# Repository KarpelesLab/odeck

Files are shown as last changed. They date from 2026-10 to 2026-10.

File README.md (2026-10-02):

# odeck

An open-hardware USB-C deck you can order fully assembled from JLCPCB and use as a bare PCB the day it
arrives: USB-C upstream, display out, USB-A, SD + microSD, 2.5 GbE, up to **140 W** pass-through
charging, a small status LCD instead of a wall of LEDs, and an RP2350 you can reprogram.

The long-term goal is a **40 Gbps USB4** deck. The first board, **odeck-10**, is a 10 Gbps USB-C deck
built only from parts JLC stocks, to prove out everything the USB4 version will reuse: power, PD,
firmware, display, card reader, Ethernet, board shape and silkscreen.

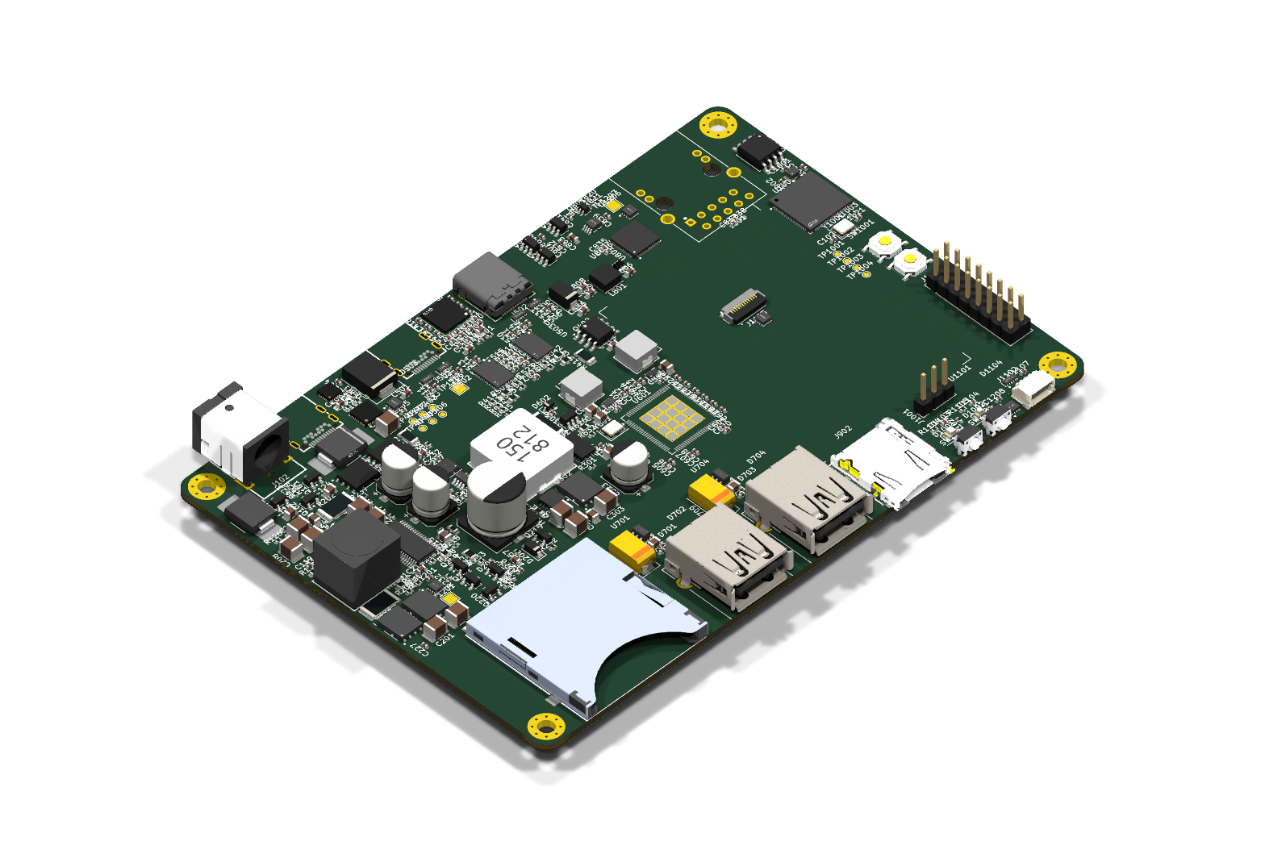
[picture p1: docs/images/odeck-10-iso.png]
odeck-10 rough placement


> **Status (2026-10): schematic complete and reviewed, placement done (DRC-clean, unrouted) — not routed,
> not fabricated.** Placement is code: `hardware/odeck-10/layout/*.py` (one script per board region, see
> `docs/floorplan.md`). The LCD panel and the two JAE USB-C receptacles have no 3D model yet, and the
> GPIO header is shown although it ships unpopulated. More views: [top](docs/images/odeck-10-top.png) ·
> [bottom](docs/images/odeck-10-bottom.png).

## odeck-10 at a glance

| | |
|---|---|
| Upstream | USB-C, USB 3.2 Gen 2 (10 Gbps) + DisplayPort Alt Mode (2-lane HBR3, 4K60) |
| Charging the laptop | USB PD 3.1 EPR up to **140 W** (28 V × 5 A), 100 W SPR fallback |
| Power inputs | USB-C PD in (EPR, up to 48 V) · DC barrel 5.5×2.5 mm 9–24 V · or bus-powered from the laptop |
| Display | Downstream USB-C with DP Alt Mode (works with any USB-C→HDMI/DP cable) |
| USB | 2× USB-A 10 Gbps (BC1.2 charging), downstream USB-C 10 Gbps, forced-5 V "dumb charge" mode with auto-off |
| Storage | SD + microSD (Genesys GL3224) |
| Network | 2.5 GbE (Realtek RTL8156BG) |
| Brains | RP2350B — drives a 2.0" 320×240 IPS status LCD, reads every PD contract / link speed / temperature / port current, and updates every other chip's firmware from a single UF2 |
| Hackable | 2 user buttons, unpopulated GPIO header (series-R + ESD protected), Qwiic connector, SWD |
| Board | 6-layer JLC impedance stack-up (JLC061611-1080A), 130×89 mm, ~800 parts (double-sided), all JLC stock |

### Architecture

```
 Laptop USB-C ══ TUSB1064 ══ USB 10G ══► Microchip USB7206C hub ──► USB-A ×2 · GL3224 (SD/µSD) · RTL8156BG (2.5GbE)
 (10G + DP alt,      ║                                        └──► downstream USB-C ◄══ TUSB1046 ◄═ DP 2-lane
  140 W EPR out)     ╚═════════════ DP lanes + AUX ═══════════════════════════════╝      (USB2 port → RP2350)

 Infineon PMG1-S3: laptop port (EPR source, DP UFP_D) + downstream port (5 V/3 A, DP DFP_D)
 TI TPS26750: USB-C PD-in sink (up to 48 V)        Barrel 9–24 V ─┐
 PD-in ─► ideal-diode OR ◄──────────────────────────────────────────┘ → VIN 9–48 V
   VIN ─► LM51770 buck-boost → 5–28 V × 5 A → laptop (gated, interlocked, hardware OVP)
   VIN ─► LM5148 → 5 V / 8 A → 3.3 V, 1.15 V …     laptop VBUS ─► 5 V when bus-powered
 RP2350B: LCD, buttons, I²C to PD controllers / INA2xx power monitors / 8× TMP1075 / hub SMBus
```

## Repository layout

| Path | What |
|---|---|
| `docs/requirements.md` | Goals and constraints for the whole project (USB4 end goal) |
| `docs/odeck-10.md` | **Start here** — odeck-10 architecture, part choices, design rules, integration items, status |
| `docs/power-budget.md`, `docs/board-layout.md` | Power/thermal budget, outline & placement plan, stack-up |
| `docs/design/*.md` | Per-sheet design notes with every calculation |
| `docs/review/*.md` | Independent schematic and footprint reviews, with resolutions |
| `docs/research/*.md` | Chip, JLC capability and sourcing research (incl. why 40G is not buildable from JLC stock yet) |
| `hardware/odeck-10/` | KiCad 10 project. Schematic sheets are **generated** from `sheets/*.py` |
| `hardware/lib/` | Project symbols, footprints (all checked against manufacturer drawings) and 3D models |
| `tools/schgen/` | Schematics-as-code generator + netlist verification |
| `tools/pcbsync.py` | Scripted "update PCB from schematic" (keeps placed parts where they are; `--refresh` reloads footprints) |
| `tools/apply_layout.py`, `tools/apply_routing.py` | Placement-as-code and routing-as-code runners (`layout/*.py`, `routing/*.py`) |
| `tools/autoroute.py` | Freerouting wrapper for the non-critical nets |
| `tools/bom_check.py` | Checks every part against live JLC stock (rule: JLC parts only, ≥ 5 in stock) |
| `tools/import_lcsc.sh` | Imports LCSC parts (symbol/footprint/3D) via easyeda2kicad |

## Working on it

Requires KiCad 10 (`/Applications/KiCad` on macOS) and Python 3.10+.

```sh
# regenerate every schematic sheet from its Python source and verify the netlist
python3 hardware/odeck-10/sheets/build_all.py

# electrical rules check
/Applications/KiCad/KiCad.app/Contents/MacOS/kicad-cli sch erc hardware/odeck-10/odeck-10.kicad_sch

# every part in JLC stock?  (+ cost summary)
python3 tools/bom_check.py

# push schematic changes into the PCB (uses KiCad's bundled Python)
/Applications/KiCad/KiCad.app/Contents/Frameworks/Python.framework/Versions/3.9/bin/python3 tools/pcbsync.py hardware/odeck-10

# render
/Applications/KiCad/KiCad.app/Contents/MacOS/kicad-cli pcb render --side top -o top.png hardware/odeck-10/odeck-10.kicad_pcb
```

Edit schematics by editing `hardware/odeck-10/sheets/<sheet>.py`, never the generated `.kicad_sch`.
Inter-sheet nets are declared in `tools/schgen/nets.py`.

## Roadmap

1. **odeck-10** (10 Gbps, JLC parts only) — schematic ✅ · review ✅ · footprints ✅ · placement ✅ ·
   routing ⏳ · firmware · order prototypes · bring-up
2. **20/40 Gbps USB4** — waiting on a USB4 hub controller (and its firmware) that can actually be sourced;
   see `docs/research/usb4-hub.md`.

## License

- **Hardware** — everything under `hardware/` (schematics, sheet sources, PCB, symbols, footprints, 3D
  models we created) and the hardware documentation in `docs/`: **CERN-OHL-P v2**
  ([LICENSE-HARDWARE](LICENSE-HARDWARE)).
  Copyright © 2026 Karpelès Lab Inc.
- **Software** — `tools/` and future firmware: **MIT** ([LICENSE-SOFTWARE](LICENSE-SOFTWARE)).

Not covered: third-party datasheets in `docs/datasheets/` (copyright of their manufacturers, included for
reference), footprints/3D models derived from KiCad's libraries or LCSC/EasyEDA (their own terms), and vendor
firmware/libraries (e.g. Infineon's PD stack), which are fetched at build time and never committed.

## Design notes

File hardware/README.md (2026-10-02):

# Hardware

KiCad 10 projects.

- `odeck-10/` — 10 Gbps prototype (see `../docs/odeck-10.md`, `../docs/board-layout.md`)
  - Hierarchical schematic: one sheet per block (power input, laptop power out, rails, PD controller,
    USB-C muxes & DP, USB hub, USB-A, Ethernet, card reader, MCU, display & UI, sensors)
  - PCB: JLC061611-1080A 6-layer stackup, 110 × 75 mm provisional outline, JLC design rules, net classes
- `lib/` — shared project symbol/footprint libraries (`odeck.kicad_sym`, `odeck.pretty`), referenced via
  each project's `sym-lib-table` / `fp-lib-table`. Parts from LCSC can be imported with `easyeda2kicad`.

CLI checks:

```sh
K=/Applications/KiCad/KiCad.app/Contents/MacOS/kicad-cli
$K sch erc odeck-10/odeck-10.kicad_sch
$K pcb drc odeck-10/odeck-10.kicad_pcb
```

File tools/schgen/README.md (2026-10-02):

# schgen — schematics as code

odeck-10 schematic sheets are generated from Python so they can be reviewed, diffed and verified.

- Sheet sources: `hardware/odeck-10/sheets/<sheet>.py`, each exposing `build(project_dir) -> Sheet`.
- Build + verify everything: `python3 hardware/odeck-10/sheets/build_all.py` (or pass module names).
  Verification exports the netlist with `kicad-cli` and checks every pin is on its intended net.
- Never hand-edit generated `.kicad_sch` files — edit the Python and rebuild.

## Writing a sheet

```python
import sys, os
sys.path.insert(0, os.path.join(os.path.dirname(__file__), "..", "..", "..", "tools", "schgen"))
from schgen import Sheet

def build(D):
    s = Sheet(D, "sensors.kicad_sch", "odeck-10 — Sensors", ref_base=1200)
    s.part("odeck:TMP1075DSGR", "U", "TMP1075", at=(60.96, 50.8),
           pins={"SDA": "I2C_SYS_SDA", "SCL": "I2C_SYS_SCL", "ALERT": "TEMP_ALERT_N",
                 "V+": "+3V3", "GND": "GND", "A0": "GND", "A1": "GND", "A2": "GND", "EP": "GND"})
    s.c("100n", "+3V3", "GND", at=(91.44, 50.8), lcsc="C1525")
    s.r("10k", "I2C_SYS_SDA", "+3V3", size="0402", lcsc="C25744")
    s.flag("+3V3")           # PWR_FLAG, only on the sheet that sources the rail
    s.note("Design notes ...", at=(20.32, 200))
    s.build()
    return s
```

- `pins` maps pin **name or number** → net. Every pin must be mapped or listed in `nc=[...]`.
- Nets in `nets.py: GLOBAL_NETS` become global labels (inter-sheet). `GND` uses the power symbol.
  Everything else is a local label scoped to the sheet. Add new inter-sheet nets to `nets.py`.
- `ref_base`: sheet reference offset (power_input 100, power_laptop 200, power_rails 300, pd_pmg1 400,
  usbc_muxes 500, usb_hub 600, usb_a 700, ethernet 800, card_reader 900, mcu 1000, display_ui 1100,
  sensors 1200) so references never collide.
- `at` positions in mm on a 2.54 mm grid; place related parts near each other. Symbols are placed
  unrotated (rot=0); a short wire stub + label is added on each pin.
- Passives: `s.r()`, `s.c()` with KiCad standard footprints; set `lcsc=` to a JLC **basic** part
  whenever possible. Other parts: `s.part("Device:L", ...)`, `s.part("odeck:<symbol>", ...)`.

## Adding parts from LCSC

```sh
tools/import_lcsc.sh C42166327 C43131250      # symbol + footprint + 3D into hardware/lib
```
Then set pin electrical types (easyeda imports them as unspecified):
```python
from fix_pins import fix_pins
fix_pins("TPS26750SRSMR", {"VBUS": "power_in", "GND": "power_in", "SDA": "bidirectional"}, default="passive")
```
Both tools take a lock on `hardware/lib/.lock`, so parallel runs are safe. Always check the imported
footprint against the datasheet land pattern before layout.

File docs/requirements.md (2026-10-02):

# odeck — Requirements

Open USB4 (40 Gbps) deck, designed to be fabricated **and fully assembled** by JLCPCB,
usable as a bare PCB straight out of the box.

## Goals

- **Upstream:** USB-C, USB4 40 Gbps (TB3/TB4 host compatible), PD source to host up to **140 W (PD 3.1 EPR, 28 V × 5 A)**, 100 W SPR fallback.
- **Downstream:**
  - 1× USB-C USB4/TB (daisy chain, DP alt mode monitor — "USB display")
  - 1× HDMI (target HDMI 2.1 / 4K120 via DP→HDMI PCON; 4K60 minimum) — 40G version; odeck-10 uses DP alt mode on the downstream USB-C only
  - 2× USB-A 10 Gbps
  - SD (UHS-I min, UHS-II stretch) + microSD
  - 2.5GbE RJ45
- **Power:** both modes
  - Bus-powered: runs from host with reduced features / downstream power budget
  - PD-in USB-C (EPR sink, up to 240 W chargers): full features + pass-through charging of host
  - DC barrel jack (5.5×2.5 mm high-current, accept 9–24 V, up to ~200 W at 24 V, overvoltage + reverse polarity
    protected): full features; host charging limited by PSU capability (12 V ≈ 60 W total)
  - Input priority: PD-in > barrel > bus power (ideal-diode / power-mux OR-ing, no back-feeding)
  - MCU-managed dynamic power budget: laptop contract renegotiated as input capability and downstream load change
  - Power path: 9–48 V in → buck-boost (LM5176/LM5177 class, external FETs) → 5–28 V PD source
- **Status display** (small SPI IPS LCD, MCU-driven; replaces most status LEDs — size TBD):
  - Negotiated link speed per port (USB2 / 5G / 10G / 20G / 40G)
  - LAN link speed (from RTL8156 LED pins) and activity
  - Display output: mode / lanes / resolution where readable
  - PD: input source + W available, contract with host (V × A), downstream port power, bus-powered mode
  - Mounting: panel on ~1 mm+ double-sided foam tape (or perimeter foam gasket) on the board surface; FPC tail
    bent back and soldered to pads or plugged into a connector. Area under the panel: copper/silk only if full-pad
    tape, or low-profile parts inside a perimeter gasket. Confirm JLC can apply tape + mount panel.
  - Keep a minimal LED or two (power / fault) for when the display is off or firmware is broken
  - Optional: MCU as USB device on the hub so a host-side app can push extra info
- **System MCU: RP2350B** (QFN-80, 48 GPIO; JLC C42415655 in stock) + QSPI flash
  - Drives the LCD, collects status (I2C/SMBus to PD controllers & hub, LED pins of PHY/card reader)
  - USB device on an internal hub port: UF2 drag-and-drop firmware updates through the deck itself,
    optional host-side status app, can reflash other on-board SPI flashes
  - **RP2350 flashes every other programmable component** (PD controllers, config EEPROMs, hub config);
    its firmware bundles their images so a single UF2 updates the whole deck.
  - PD controllers still boot autonomously from their own flash/EEPROM at runtime; hardware backstops
    (independent VBUS OVP, power-good gating) protect the laptop regardless of any firmware.
  - **User GPIO expansion (optional, unpopulated by default or low-profile):** 2.54 mm header with spare
    GPIOs (incl. ADC-capable pins, PIO-friendly), 3V3 / 5V / GND, series resistors + ESD; Qwiic/STEMMA QT
    (JST-SH 4-pin) I2C connector; SWD pads; BOOTSEL + reset buttons
- **Form factor:** compact, target ~100×60 mm, bare-PCB friendly (no sharp/live parts
  exposed on the bottom, thermal solution that works without an enclosure).
- **Silkscreen:** looks good — port/LED legend, back-side spec & pinout art.

## Constraints

- All parts orderable through JLCPCB assembly (LCSC stock or Global Sourcing).
- Works on arrival: any chip firmware must be pre-programmed by JLC, ROM-based, or
  self-flashable on first boot without extra tools.
- **Openness:** schematic, layout, and MCU firmware fully open. Vendor firmware blobs
  allowed but not committed if license forbids; no NDA content in the repo.
- Tooling: KiCad 9+, JLC impedance-controlled stackup (6–8 layers expected).

## Roadmap
1. **odeck-10** — USB 3.2 10 Gbps + DP alt mode, all JLC-assemblable (see `odeck-10.md`). Current focus.
2. 20G / 40G — USB4 core, once a chip + firmware can be sourced. Not started.

User GPIO header ships unpopulated. Display: 2.0" 320×240 IPS.

## Phases (per board)

0. Chip selection — availability, package/pitch, datasheet access, firmware story
1. Block diagram, power budget, stackup, board outline & connector placement
2. Schematic
3. Layout
4. MCU firmware (PD policy, status LEDs)
5. Prototype order (2–5 assembled) & bring-up
6. Rev B

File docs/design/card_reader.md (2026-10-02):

# odeck-10 — Card reader sheet (`card_reader.kicad_sch`, ref 900)

Source: `hardware/odeck-10/sheets/card_reader.py`. Genesys **GL3224-ONY04** (QFN-48, 2 LUN) on USB7206C hub port 1. It
drives a full-size SD socket (slot 1) and a microSD socket (slot 2).

```
CR_SS_TXP/N (hub TX, 220 nF on usb_hub) ──────────► RXP/RXN 11/10
CR_SS_RXP/N ◄── 100 nF ◄── TXP/TXN 8/7                     GL3224-ONY04 (U901)
CR_DP/CR_DN ──────────────── DP/DM 5/4                      ROM firmware, internal POR
+5V ── VBUS 22 ─► int. LDO ─► CR_3V3 (25; AVDD33 6/15, DVDD33 34/44) ─► int. LDO ─► CR_1V2 (26; AVDD12 9)
25 MHz (YXC 3225) X1/X2 13/14     RTERM 16 ── 680 Ω 1 %      SPI_MISO 10k PU (ROM boot), SPI_CK DNP 10k PD
S1M1_VCC 23 ─ CR_SD_VCC ─► SD-111  VDD      S1 CLK/CMD/D0-3, SD1_CDZ ◄─ CD sw, SD1_WP ◄─ WP sw
S2M2_VCC 24 ─ CR_USD_VCC ► DM3AT   VDD      S2 CLK/CMD/D0-3, SD2_CDZ = MS2_INS/SD2_WP ◄─ detect sw
SD1_CDZ ─ 1k ─► CR_CD_SD_N    SD2_CDZ ─ 1k ─► CR_CD_USD_N    LED 21 ─ 1k ─► CR_LED  (+ DNP bench LED)
```

## Choices

### GL3224-ONY04 (C157358, 1646 in stock)
- **It is USB 3.1 Gen1 (5 Gbps), not 10G** (DS rev 1.11 ch. 1–2), so hub port 1 trains at 5 Gbps.
  - That is about 400 MB/s usable, against UHS-I SDR104 at 104 MB/s per card, so it is not a bottleneck.
  - No Gen2 card reader is in JLC stock.
- Runs from ROM. **No SPI flash fitted**:
  - SPI_MISO has a 10 kΩ pull-up to CR_3V3, so a missing flash reads 0xFF and the chip boots from ROM.
  - SPI_CS and SPI_MOSI are NC.
  - SPI_CK has a DNP 10 kΩ pull-down. This is the Genesys ROM-option strap: pull-down = SSC on the card clock, for EMI
    tuning.
  - A flash footprint is not worth it. Updates go through Genesys' MP tool only, and the RP2350 does not need it.
- No reset pin; the chip has an internal POR (DS fig. 5.2: 95 ms from reset release to USB ready).
- MS (Memory Stick) is not supported by our sockets. S1D4–S1D7 (MMC 8-bit) are NC.

### Power
- The only supply is **+5V on VBUS** (4.75–5.25 V; +5V is about 5.11 V).
- The internal 5 → 3.3 V LDO output is DVDD33 pin 25, which feeds the local net CR_3V3 (AVDD33 6/15, DVDD33 34/44). The
  internal 3.3 → 1.2 V LDO output is DVDD12 pin 26, which feeds CR_1V2 (AVDD12 9).
  - These nets are **local** and must never be tied to +3V3.
- Decoupling follows the Genesys GL3224(E) QFN48 demo board V3.00 and the open GL3224 designs (wuxx/SD-Reader-GL3224,
  OSHWHub):

  | Pin(s) | Cap |
  |---|---|
  | VBUS 22 | 10 µF + 100 nF |
  | CR_3V3 at pin 25 | 10 µF |
  | AVDD33 6 | 1 µF + 100 nF |
  | AVDD33 15, DVDD33 34, 44 | 100 nF each |
  | AVDD12 9 | 2.2 µF |
  | DVDD12 26 | 1 µF |
  | VUHS_1 43, VUHS_2 33 (internal SD IO 3.3/1.8 V for UHS-I) | 1 µF each |
  | Card VCC (S1M1_VCC 23, S2M2_VCC 24; on-chip card power FETs) | 4.7 µF + 100 nF each, at the socket |

- Card VCC is kept below the 10 µF some designs use, so the internal LDO dips less at card power-on.
- Budget:
  - GL3224 draws 147 mA in SS U0 active (DS table 5.3). Each UHS-I card draws up to about 200 mA. Everything runs through
    the internal LDO.
  - Worst case is (5.11 − 3.3) V × ~0.35–0.55 A ≈ 0.6–1.0 W in the QFN. θJA is 33 °C/W, giving +20…33 K.
  - The power budget lists 0.4 W for the chip plus 1.0 W for the cards; the LDO loss sits inside those numbers.
  - The thermal pad needs a via array to inner GND.

### Clock, USB, RTERM
- 25 MHz crystal: YXC X322525MOB4SI (C9006, JLC basic, the same as the hub). CL is 12 pF with 2 × 20 pF.
  - The GL3224 only needs ±300 ppm (25 MHz ± 0.03 %).
  - The Genesys demo board V3 removed its crystal option. Crystal-less operation is not documented for the -ONY04, so
    the crystal stays.
- RTERM: 680 Ω 1 % (UNI-ROYAL 0603WAF6800T5E 0603, C23228) to GND, as DS table 3.1 recommends.
- AC coupling, following integration item 14 (the transmitter side owns the cap):
  - Hub TX → CR_SS_TX* (220 nF on usb_hub) → GL3224 RX directly.
  - GL3224 TX → **100 nF** here → CR_SS_RX* → hub RX.
  - **100 nF, not 220 nF**, because the GL3224 is a Gen1 transmitter, and Gen1 allows C_AC_COUPLING of 75–200 nF. The
    open-source GL3224 boards also use 100 nF.
  - The hub-side 220 nF is fine because the USB7206C is a Gen2 transmitter (75–265 nF).
- USB2 D+/D− go to the hub directly.
- Embedded link, so no ESD on the USB lines. The hub straps port 1 as non-removable.

### Sockets
- **Full-size SD: Hanbo SD-111** (C410353, 5209 in stock), push-push.
  - From the Hanbo drawing, the **CD** switch (pin 10) closes to VSS1 (pin 3) when a card is inserted.
  - The **WP** switch (pin 11) closes to GND when the card is **unlocked**. It is open when the card is locked or no card
    is present.
  - This matches the GL3224 directly. SD1_CDZ: 0 = card. MS1_INS/SD1_WP has a 46 kΩ pull-up: 0 = write enable,
    1 = write protect.
  - With no card, pin 2 is high, so the ROM never sees a false Memory Stick insert.
- **microSD: Hirose DM3AT-SF-PEJM5** (C114218, 16 792 in stock), push-push.
  - The detect switch is normally open between SW_A (GND) and SW_B (CR_USD_CDZ).
  - Shell pads 10, 12, 13 and 14 go to GND.
  - **Pin 35 MS2_INS/SD2_WP is tied to `CR_USD_CDZ`** (review data #1). It is a shared pin: as Memory Stick insert
    detect, 0 means card inserted (GL3224 DS Table 3.1).
    - The old tie to GND made slot 2 permanently report "MS inserted". The internal pull-up alone would report every
      microSD as write-protected.
    - With the tie to CR_USD_CDZ: no card → high, so no MS and no WP. Card → low, so SD present and write enabled.
      This is the same state slot 1 has with an unlocked SD.
    - The two 46 kΩ internal pull-ups in parallel (≈ 23 kΩ) are fine.
- CMD/DAT pull-ups: the GL3224 has internal 15 kΩ pull-ups on CMD and D[3:0] (DS table 5.3), so there are no external
  resistors.
- No ESD array on the card lines, which follows every reference design. The GL3224 is rated 4 kV HBM. Any array would load
  the 208 MHz SDR104 clock; see open issues.

### Card detect → TCA9534, activity → RP2350
- The GL3224 needs both CD switches itself (SD1_CDZ / SD2_CDZ), so the switches connect to the GL3224. The **TCA9534
  I/O expander** (mcu, P3/P4) taps the same nodes through 1 kΩ, onto `CR_CD_SD_N` and `CR_CD_USD_N`.
  - The TCA9534 has no internal pulls (DS §8) and is 5 V tolerant, so the old "RP2350 pulls off" rule no longer
    applies.
  - The 1 kΩ limits current if the pin is ever mis-configured as an output against a closed switch.
  - CR_3V3 exists whenever +5V exists, and +3V3 is made from +5V, so there is no back-powering path.
- `CR_LED`: the GL3224 LED output (push-pull 3.3 V, active high) goes through 1 kΩ to an RP2350 GPIO, and the LCD shows
  activity.
  - A DNP 1 kΩ + green 0805 LED is provided for bench use.

## Part list (this sheet)

| Ref | Part | LCSC | JLC stock (2026-10-02) | Type | Qty |
|---|---|---|---|---|---|
| U901 | Genesys GL3224-ONY04 QFN-48 | C157358 | 1646 | ext | 1 |
| J901 | Hanbo SD-111 full-size SD push-push | C410353 | 5209 | ext | 1 |
| J902 | Hirose DM3AT-SF-PEJM5 microSD push-push | C114218 | 16 792 | ext | 1 |
| Y901 | YXC X322525MOB4SI 25 MHz 3225 | C9006 | 199 410 | basic | 1 |
| R901 | UNI-ROYAL 0603WAF6800T5E 680 Ω 1 % 0603 | C23228 | 2 389 645 | basic | 1 |
| R902, R903 (DNP) | 10 kΩ 0402 | C25744 | 21 M | basic | 2 |
| R904–R906, R907 (DNP) | 1 kΩ 0402 | C11702 | 7.2 M | basic | 4 |
| D901 (DNP) | KENTO KT-0805G green LED | C2297 | 3.1 M | basic | 1 |
| C901 | 10 µF 25 V 0805 | C15850 | 4.9 M | basic | 1 |
| C903 | 10 µF 10 V 0603 | C19702 | 10 M | basic | 1 |
| C909 | 2.2 µF 0402 | C12530 | 5.1 M | basic | 1 |
| C913, C915 | 4.7 µF 0402 | C23733 | 2.4 M | basic | 2 |
| C904, C910–C912 | 1 µF 0402 | C52923 | 5.6 M | basic | 4 |
| C902, C905–C908, C914, C916–C918 | 100 nF 0402 (decoupling + 2× TX AC caps) | C1525 | 21 M | basic | 9 |
| C919, C920 | 20 pF C0G 0402 | C1554 | 657 k | basic | 2 |

`tools/bom_check.py`: 149 unique parts across the project, 0 failing, 0 without LCSC.

## Open issues
1. **No official GL3224 SD reference schematic** was available; the datasheet has no application circuit.
   - Decoupling and pin usage come from the Genesys eMMC demo board (same QFN48) and two working open designs.
   - Ask Genesys or the LCSC FAE for the SD/microSD reference before layout, especially about card-VCC capacitance and
     whether VUHS needs 1 µF or 0.1 µF.
2. **Thermal.** The internal LDO burns up to about 1 W with two UHS-I cards active.
   - Option (seen on OSHWHub "GL3224_DUALTF"): an external 3.3 V buck onto DVDD33, back-driving the internal LDO.
   - That is undocumented, so it is not done here. Revisit with prototype temperature data (place a TMP1075/NTC nearby).
3. **+5V in bus-powered mode** must stay ≥ 4.75 V at the GL3224 (integration item 2).
4. **Footprints.** Check the SD-111 easyeda footprint (NPTH pegs, WP/CD pad positions) and the DM3AT (shell pads 10, 12,
   13, 14 and switch pads 9/11) against the manufacturer land patterns. The GL3224 EP is 5.1 mm (QFN-48 7×7).
5. **Card-line ESD / series termination.** None is fitted. If SDR104 shows ringing on the bench, add 22–33 Ω series
   resistors on CLK; a 0402 footprint could be added at layout.
6. **Firmware (RP2350):** CD inputs on TCA9534 P3/P4. Optionally clear BC1.2 on hub port 1 (usb_hub already plans
   `BC_CONFIG_P1` = 0).

No new inter-sheet nets are needed. The mcu sheet reads CR_CD_SD_N and CR_CD_USD_N on the TCA9534, and CR_LED on an
RP2350 GPIO with pulls disabled.
7. **Bench: MS-vs-SD priority** (review data #1 and #7). Both slots rely on the GL3224 ROM giving SDx_CDZ = 0 priority
   over MSx_INS = 0, and the DS does not state that priority. Test: an unlocked SD in slot 1 and a microSD in slot 2 must
   each enumerate as a writable SD, not as MS. If either fails, add an inverter or strap and ask the Genesys/LCSC FAE.

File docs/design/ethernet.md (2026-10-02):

# odeck-10 — Ethernet sheet (`ethernet.kicad_sch`, refs 800+)

Source: `hardware/odeck-10/sheets/ethernet.py` (generated, netlist-verified). Stock figures are from the JLC parts API on
2026-10-02. Re-check them before ordering.

## Sources used
- **RTL8156BG(S)-CG datasheet Rev 1.1** (Realtek, NDA, but a copy circulates publicly, e.g. on doc.chipmall.com). It gives
  pinout, power, sequencing, crystal specs, EEPROM/eFuse/I2C-MACID behaviour and LED registers.
- **Realtek RTL8125D/8125B(G)(S)/8111K reference schematic** (2024, public). This is the PCIe sibling and uses the same
  2.5G PHY and the same `POW_EXT_SWR` scheme. It gives RSET, the magnetics centre-tap capacitor, LED circuit, strap pull-ups
  and the "switcher must run PWM ≥ 1 MHz" rule.
- **gamefunc/rtl8156-vl822-fe2.1-open-pcb** (GitHub, verified working RTL8156B board). The EasyEDA Pro `.eprj` file is
  SQLite, and its pad netlist was extracted. It confirms the pull values (4.7k PU on GPI, LANWAKEB, DOCK_DET, GPIO1/2/4, LED0,
  LED1; 4.7k PD on EECS; 2.49k RSET; 1 µF on DVDD09_UPS; 12 pF crystal caps) and that CONFIG_SEQ/GPIO3/LED2/3 can float.
  It also warns that some EasyEDA RTL8156 libraries use a 7×7 package: the real part is **QFN-56 6×6, 0.35 mm**.

## Topology

```
+3V3 ─ TPS22918 (ON = ETH_RESET_N, CT 1 nF, QOD) ─► ETH_3V3 ─┬─ RTL8156BG 3.3 V pins (+ bead ─► pin 9 PLL)
                                                              └─ TPS62A02A (EN = POW_EXT_SWR) ─ 1 µH ─► ETH_0V95 ─► 0.95 V pins
hub P4 ── ETH_SS_TX± (capped on usb_hub) ──► U3SSRX     U3SSTX ─ 100 nF ─► ETH_SS_RX± ── hub P4
       ── ETH_DP/DN ─────────────────────► U2DP/DM
RTL MDI0..3 ──► USAKRO DGUK211Q340CD2A4D2 (2.5G magjack, CT 390 pF, green/yellow LEDs)
RTL LED0/1/2 ─┬─ jack LEDs (LED0 green, LED1 yellow, 510 Ω from ETH_3V3)
              └─ SN74LVC3G17 (+3V3) ─► ETH_LED0..2 ─► RP2350 GPIO36-38
24AA025E48 (I2C_SYS 0x50) ── RP2350 reads EUI-48
RTL GPIO1/SDA, GPIO2/SCL ── BSS138DW bridge (gates = ETH_I2C_EN AND ETH_3V3, via 74LVC1G17 on ETH_3V3) ── I2C_SYS   (MAC programming into the PHY eFuse)
```

## 1. Reset = power cycle
**The RTL8156BG has no reset pin.** Its 56 pins are fully allocated: there is no PERST#/RESETB. So `ETH_RESET_N` drives the
ON pin of a TPS22918 load switch that feeds the whole PHY. Because the 0.95 V buck runs from ETH_3V3, it switches off too.
- `ETH_RESET_N` comes from TCA9534 P5 on the mcu sheet, with a 10k pull-up there (no pull-up on this sheet).
  - The expander powers up as inputs, so the PHY is powered with a dead or blank RP2350.
- **Firmware:** hold `ETH_RESET_N` low for at least 100 ms. That covers t4 (≥ 50 ms off-to-on interval, DS table 25)
  plus QOD discharge of ~45 µF.
  - The same control turns 2.5GbE off for thermal derating, which saves ~0.6 W.
- **Rise time:** CT = 1 nF gives tR ≈ 1.7 ms at 3.3 V (TPS22918 DS), inside the PHY's t1 of 0.5–10 ms. Inrush is about
  45 µF × 3.3 V / 1.7 ms ≈ 90 mA.
- **QOD** is tied to VOUT, so the internal pull-down discharges ETH_3V3 and the 0.95 V buck sees UVLO quickly.
- **No back-powering of the off PHY:**
  - Every strap and pull-up returns to ETH_3V3, never +3V3.
  - The LED buffer inputs have no VCC clamp (LVC Ioff).
  - The I2C bridge's body diodes point away from the PHY.
  - The USB lines come from the hub, and an unpowered USB device is a normal case.
- Alternative (unused): DOCK_DET low triggers a "self-reset" (DS 6.23). The feature is eFuse-dependent and undocumented, so
  DOCK_DET is simply pulled high.

## 2. 0.95 V core rail (integration item #1)
- **Requirement (DS 9.2/9.7/8.1):**
  - 0.92–0.98 V (±3 %), 364 mA typ / 650 mA max.
  - Rise 0.5–2.2 ms; ≥ 50 ms off-on.
  - Abs max 1.05 V.
  - The PHY enables the regulator itself through **pin 5 POW_EXT_SWR**, an active-high output.
  - Realtek's reference says a switcher feeding the PHY must run PWM ≥ 1 MHz.
- **Part:** TPS62A02A**DRLR** (C5820994, 11.6k stock).
  - It is the forced-PWM "A" variant at 2.4 MHz, so there is no PSM ripple at the PHY's light load.
  - Internal 1 ms soft start, which meets t3.
  - VIN 2.5–5.5 V from ETH_3V3, with UVLO at 2.3–2.5 V.
  - Output discharge when disabled.
  - Chosen over TLV62569 (the PSM part named in power_rails.md) because of the forced-PWM requirement.
- **Setpoint:** VOUT = 0.6 V × (1 + 59k/100k) = **0.954 V**.
  - Tolerance stack: VFB ±1.5 % over temperature and two 1 % resistors (±0.8 %).
  - Worst case 0.932–0.977 V, inside the 0.92–0.98 V window. Ripple at 2.4 MHz with 2×22 µF is a few mV.
- **Filter:**
  - L = 1 µH SWPA4018S1R0NT; COUT = 2 × 22 µF 0603 at the buck (TI table 8-3 standard combination for VOUT < 1.2 V).
  - Plus 3 × 2.2 µF + 2 × 10 µF + 4 × 100 nF + 2.2 µF at the PHY pins.
- **EN:** 100k pull-down. The buck stays off until the PHY asserts POW_EXT_SWR. PG is unused.
- **Loss:** ≈ 0.1 W in the buck. PHY total ≈ 0.6–0.65 W typ (0.95 V × 0.36 A + 3.3 V × 0.09 A), about 1 W worst case.

## 3. Clock, bias, straps
- **Crystal:** YXC X322525MOB4SI 25 MHz (C9006, basic). This is the same part as the hub (12 pF CL, ±10 ppm) with 2 × 20 pF.
  The PHY needs ±50 ppm all-in, ESR ≤ 70 Ω and an SMD package. A 0 Ω series resistor on the CKXTAL2 side (Realtek R27) lets
  the drive level be tuned (PHY DL max 0.5 mW).
- **RSET:** 2.49k 1 % at pin 14.

| Pin | Net | Termination | Why |
|---|---|---|---|
| 1 LANWAKEB | ETH_LANWAKE_N | 4.7k PU | open drain, unused |
| 2 GPI | ETH_GPI | 4.7k PU | LAN-disable input if enabled in eFuse; otherwise idle |
| 5 POW_EXT_SWR | ETH_SWR_EN | 100k PD → buck EN | defined level while the PHY powers up |
| 30 EECS/TWSI_SCL | ETH_EECS | 4.7k PD | no EEPROM (Realtek and open design) |
| 33/34 GPIO2/SCL, GPIO1/SDA | ETH_SCL/SDA | 4.7k PU + bridge | I2C slave for MACID (§5) |
| 35 CONFIG_SEQ | ETH_CFG_SEQ | 10k PD (+10k PU DNP) | low = CDC-NCM first; only active if enabled in eFuse |
| 37 DOCK_DET | ETH_DOCK_DET | 4.7k PU | "connected" → no self-reset |
| 38 LED0/EEDI | ETH_LED0_N | 4.7k PU + green LED | strap/idle; mcu requires ≤ 10k on strap pins |
| 39 LED1/EESK | ETH_LED1_N | 4.7k PU + yellow LED | Realtek "PU for normal application" |
| 40 LED2 | ETH_LED2_N | 10k PU | LED pins float when off |
| 53 GPIO4 | ETH_GPIO4 | 4.7k PU | as the open design |
| 3, 4, 6, 8, 28, 29, 32, 41 | — | NC | BGS-only pins, CKOUT, SPI flash, GPIO3, LED3 |

## 4. LEDs
- **Jack LEDs:**
  - LED anode at ETH_3V3, cathode through 510 Ω into the PHY pin (Realtek's low-side, active-low scheme). This gives
    ~2.5–3 mA.
  - Green (left) = LED0, yellow (right) = LED1.
  - What each LED shows (link speed, activity) is set by the LED registers (DS tables 14–18, OCP 0xDD90 area) through eFuse or
    the host driver. Blink rate is set at OCP 0xDD88.
- **RP2350 inputs:**
  - The jack LEDs and 4.7k pull-ups load the pins, and the PHY rail is switched. So a SN74LVC3G17 Schmitt triple buffer on
    +3V3 drives `ETH_LED0..2`.
  - The levels are **active low** (low = LED lit). The mcu sheet counts edges on GPIO36-38 for activity.
  - With the PHY off, the buffer inputs sit at 0 V, so the outputs are low. Firmware ignores the LEDs while it holds
    ETH_RESET_N low.
  - The buffer also means the RP2350 never loads the LED0/LED1 strap pins (mcu requirement 3).

## 5. MAC address
How the RTL8156BG gets its MAC (DS 6.4, 6.6, tables 20–21):
1. **eFuse/OTP autoload** (≥ 512 B, programmed with Realtek's PG tool). Distribution parts are blank, so you get the chip's
   default MAC or a host-randomised one. Commercial dongles have their MAC burnt into eFuse at the factory.
2. **External 93C46/56/66 (3-wire) or TWSI EEPROM.** It is only read after an eFuse autoload command (`20 DC 00 01` = TWSI)
   selects it, which again needs the PG tool. The content uses Realtek's layout, which a 24AA0xxE48 with its EUI-48 at
   0xFA–0xFF does not match. **Not usable as a plug-in MAC source.**
3. **I2C slave "MACID modified via I2C" (DS 6.6, figure 4)** on GPIO1/SDA (34) and GPIO2/SCL (33). The host writes a 36-byte
   "OTP code":
   - `[7-bit addr][W] 25 C0 00 MAC0 MAC1 MAC2 MAC3 MAC4 MAC5` followed by 26 × `00`.
   - Decoded, `25 C0 00` is an eFuse autoload record: "write 6 bytes to OCP 0xC000". That address is PLA_IDR, the MAC
     register in the Linux r8152 driver.
   - So this **burns the MAC into the PHY's eFuse** from an I2C master. That master can be the RP2350.

**Implemented path:**
- **U805, 24AA025E48T-I/OT** (C129895, SOT-23-6) on I2C_SYS at **0x50** (A1 = A0 = GND).
  - The 24AA**02**E48 was rejected: it ignores its chip-select bits and would occupy 0x50–0x57.
  - The RP2350 reads the EUI-48 at 0xFA–0xFF.
- **I2C bridge Q801 (BSS138DW, VGS(th) 0.5–1.5 V):**
  - Sources sit on the PHY side, pulled up to ETH_3V3. Drains sit on I2C_SYS.
  - The gates are `ETH_BR_G`, driven by **U806 74LVC1G17 powered from ETH_3V3**. Its input is `ETH_I2C_EN` (TCA9534
    P6, 100k PD R820), and R821 (100k) holds ETH_BR_G low.
    - The gates can therefore be high only while ETH_I2C_EN = 1 **and** ETH_3V3 is up.
    - With ETH_3V3 off, the driver is unpowered. The LVC Ioff input takes the 3.3 V from P6 without back-feeding
      ETH_3V3, and R821 keeps the gates at 0 V.
    - While ETH_3V3 decays, VOH ≤ ETH_3V3, so the gates never exceed the PHY rail. The TPS22918 QOD then takes it to
      0 V.
  - This fixes review mcu_ui #5. Before, ETH_I2C_EN = 1 with ETH_RESET_N = 0 (a firmware bug, or a thermal power-down
    in the middle of a write) pulled I2C_SYS into the dead 4.7k pull-ups and PHY clamps to about 2.25 V. That is
    below VIH, and it locked the TCA9534 that controls both signals until a power cycle. Firmware should still clear
    P6 before powering the PHY down.
  - **Off:** the PHY can see I2C_SYS traffic through the body diodes but can never pull I2C_SYS low. An unpowered PHY is not
    back-fed.
  - **On:** a normal bidirectional bridge. The BSS138DW replaces the 2N7002DW (VGS(th) up to 2.5 V) for solid
    conduction with a 3.3 V gate.
- **Firmware flow:**
  1. On first boot (flag in RP2350 flash), with the PHY powered, set ETH_I2C_EN.
  2. Write the OTP code with the EUI-48.
  3. Clear ETH_I2C_EN.
  4. Power-cycle the PHY through ETH_RESET_N so the eFuse is re-autoloaded.
  - **Program once.** eFuse is one-time, and every rewrite appends ~36 B of the ≥ 512 B.
- **Unknowns to settle on the bench:**
  - The 7-bit slave address is not given in the datasheet. Scan with the bridge on and the PHY powered.
  - Whether the I2C slave is active on a blank eFuse.
  - Whether the address collides with an I2C_SYS device while the bridge is on (0x20, 0x41/0x44/0x45, 0x48–0x4F,
    0x50). Scan with the bridge on and then off.
  - Whether the write **persists**. Write once, power-cycle with ETH_RESET_N, and read PLA_IDR back over USB. If the
    write turns out to be volatile, use the host-tool or OS fallbacks rather than rewriting on every power-up, which
    would race the host driver.
- **Fallbacks:**
  - (a) A host tool (Realtek PG tool for Windows, or `rtunicpg` on Linux) writes the same EUI-48 over USB. The RP2350 shows the
    address in the status app/LCD.
  - (b) The OS sets the MAC at runtime (`ip link set address`, `ifconfig en… ether`).
  - (c) The 24AA025E48 still gives every deck a unique, printable address for the label.

## 6. MDI and magjack
- **Jack:** USAKRO DGUK211Q340CD2A4D2 (C19725134, 111 in stock, $2.85), tab-up, THT.
  - The jack datasheet shows **green (14+/13−) and yellow (12+/11−) LEDs**, so the "no LEDs" note in odeck-10.md was wrong.
  - 1CT:1CT, OCL 180 µH, return loss to 200 MHz, Hi-pot 2250 VDC. Cable-side 4 × 75 Ω + 1000 pF/2 kV are inside.
  - It is the only stocked 2.5G-rated jack with ≥ 100 stock. Alternates: DGUK511Q340AB2A8D2 (C19725141, 47 stock, same
    LEDs, different footprint) and DGUK111Q340AB2A1D2 (8 stock). The common HR911130A (10k stock) is 1G-rated only.
- **Footprint:** the imported easyeda footprint numbered both shell pads "15", while the symbol has 15/16. The second shell
  pad was renamed to 16 in `hardware/lib/odeck.pretty/RJ45-TH_DGUK211Q340CD2A4D2.kicad_mod`. Verify the rest of the
  footprint against the drawing (pitch 1.27/2.54 staggered, LED pins 11–14, Ø3.2 pegs).
- **Pair mapping:** MDI0→TD1 (RJ 1/2, BI_DA), MDI1→TD2 (3/6, BI_DB), MDI2→TD3 (4/5, BI_DC), MDI3→TD4 (7/8, BI_DD). If the
  QFN-to-jack order forces crossings, use the PHY MDI-swap option (DS 6.15) rather than vias. Auto-MDIX and polarity
  correction cover the rest.
- **PHY-side centre taps** (pins 5 and 6): 390 pF C0G to GND, the RTL8125B-series value (2.5G voltage-mode driver: no bias
  feed). A 100 nF DNP alternate is provided.
- **No ESD array on MDI.** The magnetics isolate and Realtek's reference has none.
- **Shell to GND directly.** This follows the odeck convention of no chassis net, the same as USB connectors.

## Global nets used
`+3V3`, `GND`, `ETH_SS_TXP/TXN/RXP/RXN`, `ETH_DP`, `ETH_DN`, `ETH_LED0..2`, `ETH_RESET_N`, `I2C_SYS_SCL`, `I2C_SYS_SDA`.
There are no PWR_FLAGs: ETH_3V3 and ETH_0V95 are local and driven by power_out pins.

## Inter-sheet nets
- `ETH_I2C_EN` is global (TCA9534 P6 on mcu). Its only pull-down is R820 (100k) on this sheet; mcu has none.
- New local nets: `ETH_BR_G` (bridge gates).

## Part list (this sheet)

| Ref | Part | LCSC | JLC stock | Type |
|---|---|---|---|---|
| U801 | Realtek RTL8156BG-CG (QFN-56 6×6) | C41376388 | 2 915 | ext |
| U802 | TI TPS22918DBVR load switch | C131941 | 12 939 | ext |
| U803 | TI TPS62A02ADRLR 2 A FPWM buck | C5820994 | 11 582 | ext |
| U804 | TI SN74LVC3G17DCUR | C68245 | 3 108 | ext |
| U805 | Microchip 24AA025E48T-I/OT | C129895 | 6 430 | ext |
| Q801 | Diodes BSS138DW-7-F | C154900 | 121 051 | ext |
| U806 | Diodes 74LVC1G17W5-7 (bridge gate driver) | C151394 | 10 871 | ext |
| J801 | USAKRO DGUK211Q340CD2A4D2 2.5G magjack | C19725134 | 111 | ext |
| L801 | Sunlord SWPA4018S1R0NT 1 µH | C91250 | 5 113 | ext |
| FB801 | Sunlord GZ2012D101TF 100 Ω bead 0805 | C1015 | 2.3 M | basic |
| Y801 | YXC X322525MOB4SI 25 MHz | C9006 | 199 k | basic |
| R | 2.49k 1 % C25884, 59k 1 % C32297 | | > 100 k | ext |
| C | 390 pF C0G 50 V C282239 (same as pd_pmg1 CC caps) | | 70 k | ext |
| R/C basic | 0 Ω C17168, 510 Ω C25123, 4.7k C25900, 10k C25744, 100k C25741; 20 pF C1554, 1 nF C1523, 100 nF C1525 (incl. C835/C836 PHY TX AC caps, C841), 1 µF C52923, 2.2 µF C12530, 10 µF 0603 C19702, 22 µF 0603 C59461 | | | basic |

DNP: the CONFIG_SEQ pull-up (10k) and the 100 nF alternate CT cap.

## Open issues / risks
1. **I2C MACID path is unverified.** The slave address and whether it works on a blank eFuse are unknown. Bench-test early.
   The host-tool fallback always works.
2. ~~3.3 V supply PWM ≥ 1 MHz~~ — resolved: +3V3 is already the TPS62933**F** (FCCM, 1.2 MHz) on power_rails.
3. **RTL QFN-56 footprint:** EP is 4.7 mm in the easyeda import vs 4.5 mm (J/K) in the datasheet. Pads are 0.15 mm at
   0.35 mm pitch. Check paste and mask.
4. **Magjack stock (111)** is low. Order early, or switch footprint to C19725141.
5. **LED functions/polarity** depend on eFuse defaults of the delivered chips. Firmware can only observe, not set them, unless
   the host driver or PG tool programs the LED registers.
6. **Thermal:** about 1 W worst case in a 6×6 QFN, θJA 19 °C/W on Realtek's 4-layer board, gives about +20 K. The DS notes
   the PHY masks 2.5G when it overheats. TMP1075 U1206 sits between the QFN and the jack.

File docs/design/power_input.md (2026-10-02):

# odeck-10 — power_input sheet

Source: `hardware/odeck-10/sheets/power_input.py` (generates `power_input.kicad_sch`, ref_base 100, A2).
Status: second pass after the power review (`docs/review/power.md`), 2026-10-02. `build_all.py power_input` →
`netlist verify: OK`.
Stock figures: JLC parts API on 2026-10-02.

## Topology

```
 USB-C PD-in (J101) ─ VBUS_PDIN ─┬─ 5.0SMDJ51A, 2.2 µF + 100 nF
   CC ─ TPD4S480 (U101) ─ TPS26750 (U102) ── EEPROM AT24C512C (U103, private I2Cc)
   │       VBUS → VBUS_LV (×0.42 in EPR) → TPS26750 VBUS
   │       TPS26750 POWER_PATH_EN ─ 2×2N7002 buffer ─ PD_SINK_EN
   └─ Q104 ──(PD_MID)── Q105 ──┐   LM74800 U104: ideal diode + load switch, EN = PD_SINK_EN, OV 57 V
                                ├── VIN_OR ── 2 mΩ shunt ── VIN (47 µF/100 V alu damping + 1 µF + 100 nF)
 Barrel PJ-063BH (J102) ─ VBAR ─┤                           INA237 (U109) on I2C_SYS, 0x45
   5.0SMDJ48CA, 100 nF          │
   └─ Q106 ──(BAR_MID)── Q107 ──┘   LM74800 U105: reverse polarity, OV 27.4 V, UVLO 6.8 V
                                    (always armed: no PD-in priority, the higher input feeds VIN)

 EXT_PWR_PRESENT = BAR_OK OR PD_OK      (SN74LVC1G32, U108; all on +3V3)
   BAR_OK = TLV6700 window on VBAR (8.2 … 28.5 V), via 1N4148W
   PD_OK  = TLV6700 window on VBUS_PDIN (7.7 … 56.2 V) AND TPS26750 sink path enabled (Q103)
```

All four path FETs are BSC026N08NS5 (80 V, 2.6 mΩ, TDSON-8). Both inputs are true ideal diodes with a
second, series cut-off FET, so neither input can back-feed the other. VIN may also be back-fed from
downstream (e.g. the bidirectional buck-boost); both paths block that.

**No hardware input priority (review findings 1 and 2).** Both LM74800s stay armed whenever their input is
within its UVLO/OV window; the input with the higher voltage supplies VIN, and when it goes away the other ideal
diode takes over within the LM74800 reverse/forward response (µs), with VIN dipping only to the other input's
voltage. The earlier design shut the barrel LM74800 down from `PDIN_PRESENT` (Q108); that browned the deck out on
every PD-in loss (HGATE needs ms to re-arm from 0 V) and disabled a working barrel on a 5 V PD contract. Source
preference is now a firmware/power-budget policy: to prefer PD-in over a barrel, request a PD voltage above the
barrel (e.g. 28/36/48 V vs 19–24 V); to prefer the barrel, request a lower PD voltage or none. `PDIN_PRESENT` is
kept as an informational signal only.

### Interface nets
Global (from `nets.py`): `VIN`, `VBUS_PDIN`, `EXT_PWR_PRESENT`, `PDIN_PRESENT`, `I2C_PD_SCL/SDA`,
`PDIN_INT_N`, `I2C_SYS_SCL/SDA`, `+3V3`, `GND`. **No new inter-sheet nets.** (The `nets.py` comment on
`PDIN_PRESENT` still says "disables barrel path"; that is no longer true — it is status only.)
PWR_FLAGs: `VIN`, `VBUS_PDIN`, plus local `VBAR`.

## 1. PD-in connector and protection

- **J101 JAE DX07S024XJ1R1100** (C134113, 1626 in stock): 24-pin, 5 A / 48 V EPR rated. Same part as the
  laptop port, so one footprint to validate. Power only: VBUS, CC1/CC2, GND, shell → GND.
  **USB2 D+/D-, SBU and SuperSpeed pins are left unconnected** (no data on this port). Consequence: no
  BC1.2 detection, which is irrelevant here since a 5 V-only charger cannot run the deck anyway.
- **TVS 5.0SMDJ51A** (Liown, C2990373, 2.8k; replaced SMCJ51A C408371 on the same SMC/DO-214AB footprint):
  VRWM 51 V ≥ 50.4 V (EPR 48 V + 5 %), VBR 56.7–62.7 V, VC 82.4 V at 61 A. The 5 kW die has about a third of the
  SMCJ51A dynamic resistance (≈ 0.32 Ω vs ≈ 1.1 Ω): ≈ 64 V at 5 A and ≈ 68 V at 18 A, where the SMCJ51A was at
  82 V. See risks: the TPD4S480 VBUS pin is 63 V abs max.
- **TPD4S480** (C43131250, 2881): follows the TI reference (TPD4S480 Fig. 7-1, TPS26750 Fig. 8-24):
  RPD_G1/G2 shorted to C_CC1/C_CC2 (dead-battery Rd needed: the deck may be completely unpowered),
  VBIAS 100 nF/100 V (≥ 63 V required), VPWR from TPS26750 LDO_3V3 with 1 µF, VBUS_LV 100 nF/50 V,
  FLT# 10 k to LDO_3V3 → TPS26750 GPIO2. EPR_EN from TPS26750 GPIO0 (also auto-asserts above
  EPR_THRESH). EPR_BLK_G unused (the optional blocking FET is only needed to source 5 V from PP5V).
  SBU channels unused.

## 2. TPS26750 (U102)

- Supplies: VIN_3V3 = `+3V3` (10 µF), LDO_3V3 10 µF (5–25 µF allowed), LDO_1V5 10 µF (4.5–12 µF), CC1/CC2
  220 pF each (200–480 pF). VBUS pins = VBUS_LV (≤ 21.2 V in EPR: 0.42 × 50.4 V).
- **PP5V tied to GND**: sink-only port, no 5 V source and no VCONN needed. (Open issue: confirm with TI that
  grounding PP5V is acceptable; alternative is +5V with 10 µF.)
- **ADCIN1/ADCIN2 = 100 k / 100 k each** (DIV 0.5 → decoded 5/5): *AlwaysEnableSink*, I2C target address
  index #2 = **0x21**. The sink path is enabled at the implicit 5 V contract. **With a blank EEPROM (JLC
  delivers it blank) USB PD stays disabled** until a host loads a configuration (SLVSH67 §7.4.1), so VIN is only
  5 V, which does not start the LM5148 (UVLO 8 V): the RP2350 does **not** power up from PD-in alone. First
  programming needs the barrel, laptop bus power, or the I2Cc test pads (see bring-up below). Consider ordering
  the EEPROM pre-programmed. This matches the TI example schematic. Alternative (TI's recommendation when a patch is loaded from EEPROM): *SafeMode*,
  ADCIN1 → LDO_3V3, ADCIN2 → GND (7/0), address 0x20 — then a blank EEPROM means no PD-in power.
- **EEPROM AT24C512C-SSHD-T** (C12371, 53k): 64 KB ≥ 36 KB required, address 0x50 (A2..A0 = GND), WP = GND,
  4.7 k pull-ups to LDO_3V3 (was 2.2 k: less load on the 5 mA dead-battery LDO), own 100 nF. Test pads TP101/TP102 on I2Cc for recovery programming.
  The RP2350 reaches it only through the TPS26750 host interface (I2Ct at 0x21); see open issues.
- GPIO use (configured in the EEPROM image):
  - GPIO0 → `PDIN_EPR_EN` (TPD4S480 EPR_EN), 100 k pull-down.
  - GPIO1 → `PDIN_PRES_L` → 47 k (R117) → **`PDIN_PRESENT`**; 100 k pull-down so Hi-Z / blank EEPROM = low.
    Configure as push-pull "sink contract active / PD power path enabled". **Informational only** (PMG1 P7.2,
    RP2350); it no longer controls any power path. The 47 k limits back-drive into the unpowered PMG1 P7.2
    (not fail-safe) during a PD-in-only cold start to (3.3 − 0.5) V / 47 k ≈ 60 µA (< 0.5 mA PMG1 injection limit,
    < 1 mA TPS26750 GPIO limit). Both loads are CMOS inputs, so the RC delay is negligible.
  - GPIO2 ← TPD4S480 FLT#.
  - GPIO3–7, GPIO11: 100 k to GND (datasheet: tie low when unused; resistor avoids a short if a config drives one).
  - I2Ct_IRQ → `PDIN_INT_N` (10 k to +3V3 on this sheet). I2Cc_IRQ 10 k to LDO_3V3 (must not be grounded).
  - I2Ct SDA/SCL → `I2C_PD_SDA/SCL`; pull-ups expected on the MCU sheet.
- POWER_PATH_EN (6–12 V, ~10 µA charge-pump output, not a logic level) is buffered exactly as datasheet
  Fig. 8-5: Q101 inverts it (`PD_PP_EN_INV`, 100 k to LDO_3V3), Q102 gives `PD_SINK_EN` (100 k to LDO_3V3)
  for the LM74800 EN. Q103 (gate = `PD_PP_EN_INV`) pulls `PD_OK` low while the sink path is off.

## 3. PD-in sink path (U104 LM74800-Q1, Q104/Q105)

Chosen over a TPS26750-driven FET pair because POWER_PATH_EN is referenced to GND and cannot drive a high-side
NFET at 48 V; the LM74800 adds reverse blocking (ideal diode), OV cut-off and inrush control.

- Common-drain back-to-back: Q104 source = VBUS_PDIN (DGATE, ideal diode), Q105 source = VIN_OR (HGATE).
  VS = C = PD_MID, 100 nF VS–GND (100 V), 100 nF CAP–VS.
- **OV**: R121 100 k (from SW) / R122 2.2 k → V_OV = 1.231 × (102.2 / 2.2) = **57.2 V** (55.5–58.9 V with
  V_OVR 1.195–1.267 V); recovery at 1.13 × 46.45 = 52.5 V. Above 50.4 V EPR max, below 70 V abs max.
- **Inrush**: CdVdT = 47 nF/100 V + 100 Ω on HGATE. dV/dt = 55 µA / 47 nF = 1.17 V/ms → 48 V in ~41 ms;
  into ≤ 100 µF total on VIN (§6) I ≈ 0.12 A. (The cap sees up to VIN + 11 V ≈ 62 V → 100 V part.)
  HGATE dV/dt acts only at turn-on: during PD voltage transitions the path is fully on and the source charges
  all of VIN directly, which is why VIN capacitance is budgeted to cSnkBulkPd (§6).
- R121 (OV divider top, sees VBUS_PDIN through SW) is 0805 (150 V working voltage), like every resistor with a
  terminal on VBUS_PDIN or VBAR.
- Losses: 5 A × (2 × 2.6 mΩ) = 0.13 W (+ 10.5 mV regulated drop on Q104 at light load).

## 4. Barrel path (U105 LM74800-Q1, Q106/Q107)

- **J102 Same Sky PJ-063BH** (C3095900, 240 stock — low, pre-order): 5.5 × 2.5 mm, 8 A, 24 V.
  Pin 1 = centre pin (+), pin 2 = sleeve/spring (–) per datasheet. The two MS (mounting/shield) tabs are
  **left unconnected**: tying them to GND would short a reversed plug if the shield touches the sleeve.
- **TVS 5.0SMDJ48CA** (Littelfuse, C2649886, 1.3k; replaced SMCJ48CA C408370, same SMC footprint, bidirectional):
  standoff 48 V so a wrongly plugged 36–48 V brick or a reversed 24 V supply does not destroy it; VC 77.4 V at
  65 A, ≈ 64 V at 19 A (SMCJ48CA: 77.4 V at 19 A), under the 80 V FETs and the 70 V LM74800 A pin.
- **Why LM74800 instead of the planned LM74720 (C5219205)**: the LM74720 turns its second FET off by pulling
  the gate (PD pin) to GND. In an OR-ing design VIN stays up from PD-in, so that gives Vgs ≈ −48 V (beyond the
  ±20 V rating); TI's 18 V gate-source zener would then conduct and dump up to 10 mA × ~47 V into the PD
  pull-down. The LM74800 references HGATE to OUT, provides the same −65 V reverse protection and an
  adjustable OV, adds an accurate UVLO, needs no boost inductor, and is the same part as the PD path (4040 in
  stock vs 776).
- **OV**: R125 100 k / R126 4.7 k → 1.231 × 104.7 / 4.7 = **27.4 V** (26.6–28.2 V); recovers at 25.2 V
  (1.132 × 22.28). A 24 V ± 5 % brick (25.2 V max) never trips it.
- **UVLO**: R127 100 k / R128 22 k on EN/UVLO → rising 1.231 × 122 / 22 = **6.8 V**, falling 6.3 V.
  R125/R127 (tops on BAR_SW / VBAR) are 0805, 150 V.
- **No PD-in priority** (review findings 1/2): Q108 and the `PDIN_PRES_L` → EN/UVLO connection are removed.
  Both paths are always-armed ideal diodes; the higher voltage wins with no cross-conduction, and a hand-over
  in either direction never passes through a shutdown/re-arm of an LM74800.
- Inrush: identical to the PD path (47 nF + 100 Ω, 1.17 V/ms).
- Losses: 8.3 A × 2 × 2.6 mΩ = 0.36 W (on top of the jack contact resistance).

## 5. EXT_PWR_PRESENT

Derived from the input side only (VIN can be back-fed, and a plain VIN comparator would see that):

**Meaning:** VIN is (or is about to be) supplied at ≥ ~8 V by PD-in or the barrel. Because both input paths
are always armed, an asserted OK term really means that input is feeding (or about to feed) VIN; a 5 V PD
contract never counts. The laptop sink switch is released only on `EXT_PWR_PRESENT` AND `PG_5V` (power_laptop),
so an `EXT_PWR_PRESENT` that rises while VIN is still ramping cannot brown the deck out.

- **BAR_OK**: TLV6700 U106 window on VBAR through D103 (1N4148W, keeps negative voltage off the TLV6700
  inputs, abs min −0.3 V). Ladder R129 1 M (0805) / R130 39 k / R131 15 k (total 1.054 MΩ), V_IT 0.40 V, diode
  ≈ 0.4 V at the ~8 µA ladder current (0.3–0.5 V):
  - UV (INA+ at the 1 M / 39 k node): 0.4 × 1054 / 54 + 0.4 = **8.2 V** (≈ 8.0–8.5 V with TLV6700, 1 % R and
    diode tolerance), so a 9 V −5 % brick (8.55 V) counts. Was 9.2 V (review finding 7).
  - OV (INB− at the 39 k / 15 k node): 0.4 × 1054 / 15 + 0.4 = **28.5 V** (≈ barrel OV 27.4 V; in the
    26.6–28.5 V band BAR_OK may read high while the LM74800 is already cut off — only reachable with an
    out-of-spec 27–28 V brick; harmless now because the sink release also needs `PG_5V`).
  - At 48 V on VBAR the UV input sees 2.4 V (< 7 V abs max).
- **PD_OK**: TLV6700 U107 window on VBUS_PDIN, R133 1 M (0805) / R134 47 k / R135 7.5 k (1.0545 MΩ):
  UV 0.4 × 1054.5 / 54.5 = **7.7 V**, OV 0.4 × 1054.5 / 7.5 = **56.2 V**, wire-ANDed with Q103 (sink path
  enabled). **A 5 V PD contract therefore does not count as external power** (5 V on VIN cannot run the
  buck-boost/laptop source path usefully).
- Open-drain outputs per source wire-AND into BAR_OK / PD_OK (100 k pull-ups to +3V3), then SN74LVC1G32 U108
  → `EXT_PWR_PRESENT` (push-pull, +3V3). Everything runs from +3V3, which exists whenever anything powers the
  deck (both TLV6700s are low when +3V3 is absent, and so is the gate).

## 6. VIN: shunt, monitor, bulk

- **Shunt** R137 TA-I RLP25FEGR002, 2 mΩ 1 % 3 W 50 ppm 2512 (C459679, 52k; same part as R312): 8.3 A → 16.6 mV, P = 0.14 W.
  Placed between VIN_OR and VIN so both sources and any back-feed are measured. Route IN+/IN− as Kelvin pairs.
- **INA237** (U109, C2864837, JLC stock ~5k; replaced the 0-stock INA228 — same pinout):
  85 V common mode, 16-bit. VBUS pin = VIN. VS = +3V3. Address **0x45**
  (A1 = A0 = VS) — chosen to avoid the TMP1075 range 0x48–0x4F and the usual 0x40/0x41 of the INA226s.
  ADCRANGE = 1 (±40.96 mV) → ±20.5 A full scale. The INA237 is 16-bit: CURRENT_LSB = 20.48 A / 2¹⁵ = 625 µA;
  SHUNT_CAL = 819.2 × 10⁶ × 625 µA × 0.002 Ω × 4 (ADCRANGE=1) = **4096**. ALERT unused (NC).
- **VIN capacitance (review finding 4).** With the PD-in sink path on, the PD source charges *everything* on
  VBUS_PDIN and VIN at every upward PD transition (HGATE dV/dt only acts at turn-on). USB PD limits this to
  **cSnkBulkPd ≤ 100 µF**. The old 2 × 100 µF + 2 × 47 µF electrolytics (≈ 320 µF) are gone; VIN now carries
  one **47 µF / 100 V alu (C122, SamYoung MVK, C371305)** for damping, plus C123 1 µF / 100 V and C124 100 nF.
  The converter sheets keep only their input ceramics. Budget (ceramics with DC-bias derating; alu at +20 %
  tolerance, 56.4 µF):

  | Where | Parts | at 5 V | at 20 V | at 48 V |
  |---|---|---|---|---|
  | VBUS_PDIN (before the switch) | C101 2.2 µF/100 V 1210, C102 100 nF, PD_MID 100 nF | 2.4 | 2.0 | 1.4 |
  | VIN, power_input | C122 47 µF alu, C123 1 µF/100 V 0805, C124 100 nF, BAR_MID 100 nF | 57.6 | 57.3 | 57.0 |
  | VIN, power_laptop | C201–C204 4 × 4.7 µF/100 V X7S 1210, C214 100 nF, C215 1 µF | 19.9 | 14.9 | 9.0 |
  | VIN, power_rails | C301–C304 4 × 4.7 µF/100 V X7S 1210, C305/C306 100 nF, C315 1 µF (behind D301) | 20.0 | 15.0 | 9.1 |
  | **Total** | | **≈ 100 (worst)** | **≈ 89** | **≈ 76** |

  Derating used: 4.7 µF/100 V X7S 1210 ≈ 75 % at 20 V and 45 % at 48 V; 2.2 µF/100 V X7R ≈ 80 % / 55 %;
  1 µF/100 V 0805 ≈ 70 % / 40 %. With the nominal 47 µF the 5 V figure is 91 µF. At 30 mV/µs (vSrcSlewPos max)
  the transition charge current is ≤ 2.7 A at 20 V+, ≤ 3 A at 5 V.
- **Damping / input-filter stability.** The source (charger + cable, ≈ 0.5–2 µH, ≈ 30 mΩ) and the ≈ 31 µF of
  converter ceramics form an LC with Z0 ≈ 0.13–0.25 Ω; undamped, its peak output impedance is 0.55–2.2 Ω, which
  meets the converters' negative input impedance (|Zin| = V²/P ≥ 1.35 Ω at 9 V / 60 W, 2.1 Ω at 20 V / 190 W).
  The 47 µF alu is a series R-C damping branch through its own ESR (≈ 0.1–0.6 Ω): computed peak |Zout| is
  0.13–0.5 Ω over that L/ESR range (0.7 Ω with a cold, 1 Ω ESR and 2 µH) — ≥ 6 dB below |Zin|min. It sits at
  the VIN node next to the shunt, between the two converter input groups.
- Firmware contract: before any PD-in renegotiation (Request after Accept, EPR entry) the deck must drop to
  pSnkStdby (≤ 2.5 W) — reduce the laptop contract (PMG1) and port loads, or renegotiate only while the barrel
  carries the load. VIN hold-up with ≈ 90 µF is negligible; a PD hard reset without a barrel resets the deck.

## Part list

| Ref | Part | LCSC | JLC stock | Notes |
|---|---|---|---|---|
| J101 | JAE DX07S024XJ1R1100 | C134113 | 1626 | USB-C 48 V/5 A, hybrid THT |
| J102 | Same Sky PJ-063BH | C3095900 | 240 | Low stock; pre-order |
| U101 | TI TPD4S480RUKR | C43131250 | 2881 | |
| U102 | TI TPS26750SRSMR | C42166327 | 165 | Low stock; Mouser ~1500 |
| U103 | Microchip AT24C512C-SSHD-T | C12371 | 53480 | |
| U104, U105 | TI LM74800QDRRRQ1 | C3215600 | 4040 | LM74800MDRRR C7216630 (6031) is a drop-in |
| U106, U107 | TI TLV6700DDCR | C2868382 | 1613 | |
| U108 | TI SN74LVC1G32DBVR | C10096 | 112k | |
| U109 | TI INA237AIDGSR | C2864837 | 5240 | Replaced INA228 (0 stock) |
| Q104–Q107 | Infineon BSC026N08NS5 | C5955453 | 5786 | 80 V 2.6 mΩ; TPH2R608NH C5379811 alternative |
| Q101–Q103 | 2N7002 | C8545 | basic | (Q108 removed with the PD-in priority) |
| D101 | 5.0SMDJ51A (Liown) | C2990373 | 2797 | 5 kW, SMC; same footprint as SMCJ51A |
| D102 | 5.0SMDJ48CA (Littelfuse) | C2649886 | 1332 | 5 kW bidirectional, SMC |
| D103 | 1N4148W | C81598 | basic | |
| R137 | RLP25FEGR002 2 mΩ 2512 | C459679 | 52095 | same as R312 |
| C122 | SamYoung MVK 47 µF 100 V alu 10×10 | C371305 | 1847 | VIN damping (only VIN electrolytic) |
| C123 | 1 µF 100 V X7S 0805 | C126585 | 30k | |
| C101 | 2.2 µF 100 V X7R 1210 | C153036 | 347k | |
| C102, C103, C112, C115, C116, C124 | 100 nF 100 V X7R 0805 | C28233 | 1.25M | basic |
| C114, C118 | 47 nF 100 V 0603 | C576852 | 233k | |
| C106–C108 | 10 µF 0603 | C19702 | basic | |
| R121, R125, R127 | 100 k 0805 (150 V) | C149504 | basic | divider tops on VBUS_PDIN / BAR_SW / VBAR |
| R129, R133 | 1 M 0805 (150 V) | C17514 | basic | |
| others | 0402/0603 R & C | C25741, C25744, C25879, C25900, C25076, C25768, C25756, C25792, C1525, C14663, C52923, C1603 | basic | |
| R135 | 7.5 k 1 % 0603 | C23234 | 1.3M | basic |
| R130 | 39 k 1 % 0603 | C23153 | 458k | basic |

Approximate cost of the sheet: ≈ $21 incl. INA237 (~$1.9) and TPS26750 (~$3.2).

## Assumptions

- PD-in sources are USB PD compliant: VBUS starts at vSafe5V, and 28–48 V only after EPR entry. This matters
  because the TPD4S480 VBUS pin tolerates only 24 V until VPWR (TPS26750 LDO_3V3) is up.
- The TPS26750 configuration (TI web tool) sets: sink-only, PDOs 5 V + 9/15/20 V SPR + 28/36/48 V EPR,
  GPIO0 = EPR mode, GPIO1 = power path / contract active (push-pull), GPIO2 = fault input.
- Total VIN capacitance (this sheet + downstream) ≤ 100 µF (§6); other sheets must not add capacitance on VIN.
- +3V3 is generated from VIN (or from laptop 5 V in bus-powered mode) on the power_rails sheet.

## Open issues / risks

1. **TVS margin (accepted residual risk for the prototype).** No stocked TVS with VRWM ≥ 50.4 V stays under
   63 V (TPD4S480 VBUS abs max) at its full rated surge. The 5 kW parts now fitted clamp PD-in at ≈ 64 V (5 A) /
   68 V (18 A) and the barrel at ≈ 64 V (19 A), i.e. inside the 70 V LM74800 A/VS rating and the 80 V FETs up to
   ≈ 20 A, and marginally above the TPD4S480 63 V only for surges ≥ ~5 A. Realistic events on these ports are
   cable hot-plug ringing and ESD (sub-amp to few-amp, µs); IEC 61000-4-5 surge does not apply to a ≤ 3 m DC/USB
   cable input. Fallback if a prototype fails: a series 10–47 Ω on the TPD4S480 VBUS sense pin (check its
   supply current first). A reversed barrel together with 48 V PD-in still exceeds the LM74800 OUT/C rating
   (70 V + V(A)) — see item 7.
2. **AlwaysEnableSink at 5 V**: before a contract (or with a blank EEPROM) the sink path is closed at 5 V.
   5 V on VIN runs nothing (LM5148 UVLO 8 V, LM51770 8.06 V, `PD_OK` low), and the always-armed barrel still
   feeds VIN if present. A blank EEPROM therefore cannot boot the deck from PD-in (see §2 bring-up).
3. **EEPROM update path**: RP2350 → TPS26750 I2Ct → EEPROM requires the TPS26750 host commands for I2C
   pass-through/EEPROM programming — confirm in the TPS26750 Host Interface TRM. Fallback: I2Cc test pads
   TP101/TP102 (programming jig) or an optional link from RP2350 to the I2Cc bus (would need a new global net).
   WP is hard-tied to GND (writable); the odeck-10 plan mentions a controlled WP — not implemented, needs a net.
4. **PP5V tied to GND** — confirm with TI (E2E) for a sink-only TPS26750.
5. **TPS26750 I2C address 0x21** on I2C_PD: check against the PMG1-S3 address chosen on pd_pmg1.
6. **PJ-063BH footprint** (easyeda import): pad spacing (hole → MS 2.0 mm, hole → pin 2 3.0 mm, pin 2 → pin 1
   6.0 mm) has to be checked against the datasheet's recommended layout (which seems to give 3.0 / 5.0 / 12.0
   mm from a different reference) before layout.
7. **Reverse barrel + PD 48 V at the same time**: with A = −24 V, the LM74800 OUT/C pins are rated only up to
   70 V + V(A) = 46 V while VIN = 48 V. Edge case; accepted for the prototype.
8. **BAR_OK OV window** (28.5 V) is ~1 V above the LM74800 OV (27.4 V); EXT_PWR_PRESENT may read high with an
   out-of-spec 27–28 V brick while the barrel path is already off.
9. PJ-063BH (240) and TPS26750 (165) stock is low at JLC — order early.
10. `tools/import_lcsc.sh` appends symbols with space indentation that `kicad-cli sym upgrade` does not
    rewrite unless `--force` is given, and `fix_pins.py` only matches tab-indented symbols. I ran
    `sym upgrade --force` once under the lock. Also `schgen.verify()` reports `#FLG` PWR_FLAG pins as missing,
    and multi-line `note()` text is lost (embedded newlines). The sheet works around both locally.

## Bring-up: first EEPROM programming

The TPS26750 EEPROM ships blank, and a blank TPS26750 never negotiates above 5 V, so the RP2350 cannot be
powered from PD-in alone. Program it with one of:
1. Barrel (≥ 9 V) or laptop bus power, then RP2350 → TPS26750 host interface (I2Ct, 0x21) → EEPROM.
2. A programming jig on the I2Cc test pads TP101/TP102 (TPS26750 held unpowered or in reset).
3. JLC/LCSC pre-programmed EEPROM (cleanest for production).

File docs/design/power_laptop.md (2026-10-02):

# odeck-10 — power_laptop sheet

Source: `hardware/odeck-10/sheets/power_laptop.py` (generates `power_laptop.kicad_sch`, ref_base 200, A2).
Status: second pass after the power review (`docs/review/power.md`), 2026-10-02. `build_all.py power_laptop` → `netlist verify: OK`;
`tools/bom_check.py` → all parts on this sheet are JLC parts with stock (none consigned).
Stock figures: JLC parts API on 2026-10-02. Datasheets used: TI SNVSCL2A (LM51770), SNOSD95C (LM7480-Q1),
SNOSDE5A (LM74502), SLVSFC9C (TPS25947), SBOS300C (TLV3011), SBOS547 (INA226), Infineon BSC0805LS rev 2.1,
TI SLPS633 (CSD18543Q3A).

## Topology

```
 VIN 9-50 V ──┬─ 4x4.7µ/100V (no electrolytic: VIN ≤ 100 µF budget, see power_input §6)
              Q201 (HO1) ─ BB_SW1 ─ RCS 4 mΩ ─ L201 10 µH ─ BB_SW2 ─ Q204 (HO2) ─ BB_PSO ─ RISNS 8 mΩ ─ VBB_OUT
              Q202 (LO1)                                  Q203 (LO2)    4x10µ/50V              2x10µ + 2x100µ polymer
              U201 LM51770: 347 kHz, PSM, avg I-limit 6.25 A (hiccup), FB network selected by VBB_VSEL0..2
              EN = VBB_EN AND LAPTOP_OVP_N (discharge 150 Ω while disabled), nFLT = VBB_PG

 VBB_OUT ─ Q213 (DGATE, ideal diode) ─ SRC_MID ─ Q214 (HGATE) ─ VBUS_LSW ─ 5 mΩ (INA226 U204, 0x44) ─ VBUS_LAPTOP
            U202 LM74800-Q1, EN = SRC_ON, OV backstop 32.6 V on VBUS_LAPTOP          10 µF/50 V + 100 nF   (to connector)

 VBUS_LSW ─ Q215 (60 V, LM74502 U205, OV 6.5 V) ─ SNK_MID ─ U206 TPS259470A eFuse (3.3 A, OVLO 6 V, RCB) ─ +5V
            EN = SNK_ON

 PG5_DLY = PG_5V delayed 2.7–6.7 ms on rising, fast falling               (R251/C242/D204, node SNK_PGD)
 SRC_ON = LAPTOP_SRC_EN · EXT_PWR_PRESENT · VBB_PG · LAPTOP_OVP_N · PG5_DLY  (U203 74LVC1G11 + BAT54A + Q215/Q216)
 SNK_ON = LAPTOP_SNK_EN · /(EXT_PWR_PRESENT · PG5_DLY) · /SRC_ON          (resistor + series FET pair + kill FET)
 VBB_PG = nFLT, held low while disabled and 5.4–9.2 ms after enable (Q208, BB_PGH 1M/4.7 nF)
 LAPTOP_OVP_N = NOT latch( max(VBUS_LAPTOP, VBB_OUT) > 31.1 V ), reset by VBB_EN low   (U207 TLV3011)
```

### Interface nets
Global (all from `nets.py`): `VIN`, `VBB_OUT`, `VBUS_LAPTOP`, `+5V`, `VBB_EN`, `VBB_PG`,
`VBB_VSEL0..2`, `LAPTOP_SRC_EN`, `LAPTOP_SNK_EN`, `LAPTOP_OVP_N`, `EXT_PWR_PRESENT`, **`PG_5V`** (input; LM5148
power-good from power_rails, open drain, 100 k to 5V_BUCK, 5.1 V level), `I2C_SYS_SCL/SDA`, `+3V3`, `GND`.
PWR_FLAG on `VBB_OUT`.

Signals this sheet *drives*: `VBB_PG` (open-drain + 10k pull-up to +3V3 here), `LAPTOP_OVP_N` (open-drain FET +
10k pull-up here), `VBB_OUT`, `VBUS_LAPTOP` (when sourcing), `+5V` (when sinking). Other sheets must not add
pull-ups/pull-downs to `VBB_PG` / `LAPTOP_OVP_N`. Inputs `VBB_EN`, `VBB_VSELx`, `LAPTOP_SRC_EN` have 100k
pull-downs here (floating PMG1 → converter off, 5 V setting, source off). `LAPTOP_SNK_EN` has an effective
47k pull-down (through 10k). Inputs are 3.3 V logic (5 V tolerant except `LAPTOP_SNK_EN`, which sees 0.82× its level).

PMG1 firmware contract:
- VBB_EN high → converter starts at 5.115 V; `VBB_PG` is held low for 5.4–9.2 ms after enable (LM51770 nFLT is
  not valid during its 2.2 ms soft start) and is a true power-good after that. Firmware should still check VBUS
  with the PMG1 ADC before PS_RDY.
- VSEL codes (VSEL2..0): `000` 5.1 V, `001` 9 V, `010` 15 V, `100` 20 V, `111` 28 V. Any code change is
  slewed in hardware (τ 4.6–7 ms, ≤ 5 mV/µs); wait ≥ 35 ms (or measure VBUS) before PS_RDY.
- Assert `LAPTOP_SRC_EN` only after `VBB_PG`; hardware blocks it otherwise (and also until `PG_5V` has been
  high for the RC delay, i.e. the deck runs from its own buck and the sink switch is released).
- `LAPTOP_SNK_EN` may stay asserted through a bus-power → external-power hand-over: hardware releases the sink
  only after the LM5148 regulates. De-assert it before a PR_Swap to source.
- To clear an OVP latch, drop `VBB_EN` (≥ 1 ms), then restart at 5 V.
- After a down-step with no laptop load, enable the PMG1 VBUS discharge or cycle VBB_EN.

## 1. Buck-boost power stage (LM51770)

Part choice: **LM51770DCPR** (C43351171, 1007 in stock, $5.32): 3.5–78 V in (85 V abs), 1.8 MHz capable,
average current limiter, PSM. LM5177 (60 V, 151 stock) has less margin at 50.4 V; LM51772 (I2C, 55 V) has
1 piece in stock. Its features fit: external FB divider (hardware voltage select), ISNS average current
limit with hiccup, nFLT power-good.

| Quantity | Formula (datasheet) | Value |
|---|---|---|
| fsw | R_RT = (1/fsw − 20 ns)·30.3 GΩ (Eq. 2) | R_RT = 86.6k → **347 kHz** |
| Gate charge check | ≤ 42 nC/driver at 600 kHz | BSC0805LS 16 nC, CSD18543Q3A ~6 nC at 5 V |
| Inductor ripple, buck 48→28 V | (VIN−VO)·D/(L·f) | 3.36 A p-p (worst) |
| Ripple, buck 48→5 V / 20→5 V | | 1.29 / 1.08 A |
| Ripple, boost 14→28 / 12→28 / 9→28 V | VIN·D/(L·f) | 2.0 / 1.98 / 1.76 A |
| Peak inductor current, 140 W from 20 V | IIN + ΔI/2 = 7.19 + 0.83 | 8.0 A |
| Peak current limit | Vth+(CSB−CSA) / RCS = 50 mV / 4 mΩ | **12.5 A** (10.6–14.4 A) |
| Inductor | Isat 17.5 A > 14.4 A max limit; Irms 15.5 A | XAL1010-103 |
| Avg output current limit | 50 mV / RISNS 8 mΩ (49–51.7 mV) | **6.25 A** (6.1–6.5 A), hiccup 1 ms/24 ms |
| Slope | R_SLOPE = L/RCS · 50e6 (Eq. 12) = 125k | **100k** (×0.8 → more slope, TI guidance) |
| Eq. 13 / Eq. 14 | RCS/L < fsw/(10·VOmax); 100 < RCS/L < 8000 | 400 < 1240 ✓; 400 ✓ |
| CSA/CSB filter | C = t_on,min / (2π·20 Ω·10) | 10 Ω + 10 Ω + 100 pF |
| Soft start | C_SS = 10 µA · t / 1 V | 22 nF → 2.2 ms |
| UVLO | 1.25 V·(1 + 200k/43k) + 200k·5 µA | on 8.06 V, off 6.78 V |
| VCC | ≥ 10 µF effective | 2× 22 µF 0805 (≈ 24 µF at 5 V) |

Full 140 W needs VIN ≳ 16 V: from 12 V the input current would be 12.4 A average (13.4 A peak), above the
10.6 A guaranteed peak limit. With CFG row 8 the peak/average limit **hiccups** (1 ms on / 24 ms off) rather than
limiting, so the laptop would lose VBUS — it does *not* "deliver ~100–130 W". PMG1 policy must cap the laptop
offer by input voltage so the input current stays below ≈ 10 A peak: 12 V barrel → ≤ 100 W including the 5 V
rail (a 12 V barrel is budgeted at 60 W total in `power-budget.md` anyway).

CFG = 6.49k (R2D setting #7, table row 8): DRSS spread spectrum **on**, hiccup **on**, PSM entry 10 %,
ISNS **current limiter** on. SYNC = VCC (positive limit direction latched at start-up, no external clock),
DTRK = GND, HO1_LL/HO2_LL open. BIAS = VBB_OUT via 10 Ω/1 µF: VMAX picks min(VIN, BIAS) above 6.5 V, so the VCC
LDO runs from VBB_OUT (≤ 28 V) instead of 48 V once the output is above 6.5 V.

MODE = GND (PSM, 0 Ω; DNP 0 Ω to VCC selects FPWM). Reasons: no reverse current, so down-steps never pump
VBB_OUT energy back into VIN (VIN is fed through ideal diodes and could rise by tens of volts with only the
input caps to absorb 0.5·220 µF·(28²−5²) = 83 mJ); OVP1 is masked in PSM so nFLT does not glitch during
down-steps; light-load efficiency. Down-steps are then discharged by the laptop (it drops to standby before a
lower PDO, ~90 mA at 28 V → ~0.4 V/ms on 220 µF) and the PMG1 VBUS discharge.

### Compensation (Eq. 3–11), starting point
Feedback AC gain is fixed by the slew network (section 2): at crossover Cm shorts node BB_FBM, so the AC divider is
Rtop : (Rbot‖Rs) = 100k : 1.42k → **71.8 V equivalent** for every code.

- f_RHPZ = VO(1−D)²/(2π·IO·L): 14.4 kHz (9 V→28 V, 3.2 A current-limited), 20 kHz (12 V, 4.1 A), 45 kHz (20 V, 5 A).
- f_BW < f_RHPZ/3 = 4.8 kHz and < (1−Dmax)·fsw/10 = 11 kHz → **f_BW = 3 kHz**.
- R_COMP = 2π·3 kHz·71.8·10·4 mΩ·220 µF / (600 µS·(1−0.68)) = **62k**.
- f_pole,boost = 2·IO/(2π·VO·CO) = 258 Hz; f_CZ = 1.5× = 387 Hz → C_COMP = **6.8 nF**; C_HF = 1/(2π·10·f_BW·R) = **82 pF**.
- Buck mode (5 V, 20 V in) crossover ≈ 8 kHz with the same network (no RHPZ), boost ≈ 2.6 kHz.
- Current limiter (IMONOUT): 10k + 1 nF → integrator crossover ≈ 6 kHz (gm_ILIM 200 µS · RISNS/(10·RCS)).
- The Cm/Rs network adds a lag doublet at ~25–35 Hz (higher loop gain below it at low codes). Phase there is
  well below crossover; check conditional stability in SIMPLIS/PSpice (TI model) and by bode measurement at
  5, 20 and 28 V, 0.5 A and 5 A, before freezing values.

### Capacitors
- Input: 4× 4.7 µF/100 V X7S 1210 (≈ 2.1 µF each at 48 V, ≈ 3.5 µF at 20 V). RMS in buck
  = IO·√(D(1−D)) = 2.5 A worst → < 1 A per ceramic. **The 47 µF alu was removed** (review finding 4): the PD-in
  source sees all VIN capacitance, budgeted to ≤ 100 µF (cSnkBulkPd); the single 47 µF damping alu for the VIN
  node is on power_input (stability calculation there, §6). Do not add bulk on VIN here.
  All VIN-side parts ≥ 100 V (≥ 63 V required; VIN max 50.4 V).
- Output, power-stage side (BB_PSO): 4× 10 µF/50 V X7R 1210 (hot loop for Q203/Q204). VBB_OUT: 2× 10 µF/50 V +
  2× 100 µF/35 V polymer (80 % of rating at 28 V) + 100 nF. Boost RMS = IO·√(VO/VIN − 1) = 3.2 A at 20 V in.
  Ripple at 20 V in: ΔV ≈ IO·D/(C·f) ≈ 18 mV + ESR.

### Efficiency / loss estimate at 28 V × 5 A (140 W)
Model: R_DS(on) at 4.5 V gate × 1.4 (hot), switching ½·V·I·(tr+tf)·f with 16 ns (BSC0805LS) / 6 ns
(CSD18543Q3A), Coss via Qoss, Qrr + 40 ns dead time, DCR × 1.25 (hot), core loss rough, gate drive from VCC LDO.

| VIN | Mode | D | IL avg | ΔI p-p | Ipk | Loss | η |
|---|---|---|---|---|---|---|---|
| 12 V* | boost | 0.57 | 12.4 A | 2.0 A | 13.4 A | 9.3 W | 93.8 % |
| 20 V | boost | 0.29 | 7.2 A | 1.65 A | 8.0 A | **3.9 W** | 97.3 % |
| 48 V | buck | 0.58 | 5.0 A | 3.4 A | 6.7 A | **3.7 W** | 97.4 % |

*12 V × 140 W exceeds the guaranteed current limit (see above); shown for reference only.
Breakdown at 20 V: Q201 0.62, Q203 0.25 + 0.21 sw, Q204 0.62 + 0.52 (Qrr/dead), Coss 0.23, L 0.92, RCS 0.21,
RISNS 0.20 W. At 48 V: Q201 0.18 + 0.67 sw, Q202 0.13 + 0.31, SW1 Coss 0.67, Q204 0.44, L 0.69, VCC LDO 0.31 W.

## 2. Output voltage select (VBB_VSEL0..2 from PMG1)

VOUT = 1 V·(1 + Rtop·G_FB). Rtop = 100k (VBB_OUT → FB), Rbot = 24.3k → **5.115 V** with all VSEL low (also when
PMG1 is unpowered: 100k pull-downs). Switched branches hang off node **BB_FBM**, joined to FB by **Rs = 1.5k** and
held by **Cm = 4.7 µF**; each branch is a resistor + AO3400A to GND (gate via 1k).

Why not plain FET-switched FB resistors: (1) an abrupt FB step makes the output slew as fast as the loop allows
(≫ 30 mV/µs) and trips nFLT (FB outside ±10 %), which would drop VBB_PG and open the source switch on every
step; (2) per-gate RC slowing gives independent bit timing, and a multi-bit change can pass through an
intermediate code (e.g. 010 → 101 via 111 = 28 V). With the shared Rs/Cm node every change, single- or multi-bit,
moves the FB current as **one first-order exponential**; FET switching glitches last ns and are filtered.

| Code VSEL2..0 | Use | Nominal | ±1 % R + ±1 % VREF (MC) |
|---|---|---|---|
| 000 | default / vSafe5V | 5.115 V | ±2.6 % |
| 001 | 9 V | 8.991 V | −2.9/+2.4 % |
| 010 | 15 V | 14.958 V | −2.8/+2.3 % |
| 100 | 20 V | 19.974 V | −2.7/+2.5 % |
| 111 | 28 V | 27.973 V | −2.5/+2.4 % (max 28.7 V) |
| 011 / 101 / 110 | unused | 17.8 / 22.3 / 26.1 V | |

Branch resistors: VSEL0 24.3k, VSEL1 8.66k, VSEL2 5.23k (E96, solved so that one-hot gives 9/15/20 V and all-on
gives 28 V exactly; G is monotonic in each bit, so **no code can exceed 28 V**). Time constant
τ = Cm/(1/Rs + ΣG) = 7.1 ms (→000), 6.6 ms (001), 5.5 ms (100), 4.6 ms (111). Largest step 5→28 V: initial
slew 23 V/4.6 ms = **5 mV/µs** (PD vSrcSlewPos ≤ 30 mV/µs); 99 % settled in < 35 ms (tSrcSettle 275 ms).
The loop (3 kHz) tracks a ms ramp, so FB stays within ±10 % and VBB_PG stays high during steps.
Optional PPS/AVS fine trim is not implemented (laptops use fixed 28 V for 140 W); a future injection resistor from a
PMG1 PWM/RC into BB_FBM would add it with limited authority.

## 3. Enable, discharge, VBB_PG qualification

- BB_ENKILL is pulled up from VIN (470k 0805, 5.1 V zener) → by default it turns on Q (EN/UVLO → GND, converter
  off), the 2N7002 + 150 Ω/1 W VBB_OUT discharge (τ = 33 ms on 220 µF, 83 mJ max) and Q208 holding VBB_PG low
  (nFLT is high-Z in shutdown and its PG comparator is disabled during soft start, SNVSCL2A §8.3.15).
- **VBB_PG soft-start blanking (review finding 8):** Q208's gate is node BB_PGH, charged from BB_ENKILL through
  D201 (1N4148W, fast: VBB_PG drops as soon as the converter is disabled) and discharged through R233 1 M into
  BB_ENKILL with C227 4.7 nF to GND (τ 4.7 ms). From ≈ 4.5 V the gate falls below the AO3400A threshold
  (0.65–1.45 V) 5.4–9.2 ms after enable — ≥ 2× the 2.2 ms soft start — so VBB_PG high means VBB_OUT is regulated.
  The extra 4.7 nF on BB_ENKILL slows its rise on disable by < 0.4 ms at 9 V VIN.
- Two series AO3400A (gates VBB_EN and LAPTOP_OVP_N) pull BB_ENKILL low → converter enabled. So the
  LM51770 runs only with **VBB_EN AND no OVP latch**, and the discharge is off exactly when it runs.
- With VIN absent nothing is pulled; VBB_PG floats high through its pull-up but `EXT_PWR_PRESENT` is low then,
  so the source switch stays off. Treat VBB_PG as valid only while VBB_EN is high (and ≥ 10 ms after it rose).

## 4. Laptop source switch (LM74800-Q1 + 2× BSC026N08NS5)

- Common-drain back-to-back pair, A = VBB_OUT, OUT = VBUS_LSW. DGATE FET = ideal diode (reverse comparator
  −4.5 mV, 0.5 µs turn-off): the laptop can never back-feed VBB_OUT/the converter (FRS, PR_Swap, faults).
  HGATE FET = on/off. 80 V/2.6 mΩ at 10–11 V gate drive: 5 A → 2·25·2.6 mΩ·1.3 = **0.17 W**.
  (Same FET as the power_input LM74800 pairs; was BSC040N08NS5 before the cost pass. Qg 74 nC vs 43 nC:
  turn-on is set by the 22 nF dV/dt cap anyway; DGATE 2.6 A pull-down discharges 74 nC in ~30 ns, so the
  0.5 µs reverse turn-off is unaffected.)
- EN/UVLO = SRC_ON (100k pull-down). Inrush: HGATE 55 µA into 22 nF (+100 Ω) → 2.5 V/ms; closes at vSafe5V
  into ≤ 20 µF → negligible inrush.
- OV backstop independent of +3V3 and logic: VSNS = VBUS_LAPTOP, SW → 255k/10k → OV: 1.231·26.5 = **32.6 V**
  (31.7–33.6 V), turns HGATE off in 4 µs.
- **Hardware enable** SRC_ON = LAPTOP_SRC_EN AND EXT_PWR_PRESENT AND VBB_PG AND LAPTOP_OVP_N AND PG5_DLY:
  SN74LVC1G11 (3-input AND) with input C = SRC_PGOK, a BAT54A diode-AND of the two open-drain signals
  (10k pull-up; low level ≈ 0.3 V < VIL 0.8 V), plus Q216 pulling SRC_PGOK low while Q215 (gate = SNK_PGD, the
  delayed PG_5V) is off (R242 100 k pull-up to +3V3 on its drain). PG_5V is not diode-ORed into SRC_PGOK
  directly: the 10 k/+3V3 pull-up would back-feed the PG_5V node (100 k to an unpowered 5V_BUCK) to ≈ 2.8 V and
  fake "good" in bus-powered mode.
- Logic unpowered (+3V3 absent) → SRC_ON pulled low → off.

## 5. Bus-power sink switch (VBUS → +5V)

Requirement: ~3 A limit, withstand ≥ 30 V when off (VBUS is 28 V while sourcing), never on together with the
source, never back-feed.
- **Stage 1** — CSD18543Q3A (60 V) as high-side switch driven by **LM74502** (C3236215, 8157 stock; 3.2–65 V,
  charge pump, OV pin). Drain on VBUS_LSW, source on SNK_MID: off it blocks VBUS up to 60 V; its body diode
  points back towards VBUS (reverse is handled by stage 2). OV cut-off 422k/100k → 1.25·5.22 = **6.5 V**
  (6.1–6.9 V), 1 µs: a >5 V contract can never reach +5V.
- **Stage 2** — **TPS259470A** eFuse (C3662799, 1538 stock; 28 V abs, used ≤ 6.5 V): true reverse-current blocking
  (+5V from the LM5148 never back-feeds VBUS), active current limit ILM 1.0k → 3340/R = **3.34 A** (3.0–3.7 A),
  auto-retry 110 ms; OVLO 40.2k/10k → **6.0 V**; UVLO 121k/47k → **4.29 V** rising / 3.9 V falling;
  dVdt 3.3 nF → ~0.6 V/ms soft start into the +5V bulk (≈ 0.6 A into 1000 µF); ITIMER 1 nF ≈ 0.8 ms.
- **Enable** SNK_ON = LAPTOP_SNK_EN (10k series, 47k pull-down → 2.7 V high) AND NOT (EXT_PWR_PRESENT AND
  PG5_DLY) AND NOT SRC_ON → LM74502 EN/UVLO (1.24 V threshold). Q218 (gate EXT_PWR_PRESENT) and Q219 (gate
  SNK_PGD) in series pull SNK_ON low; Q220 (gate SRC_ON) pulls it low directly.
- **PG5_DLY / SNK_PGD** = `PG_5V` through R251 100 k into C242 100 nF (τ = 20 ms with the 100 k PG pull-up on
  power_rails): crosses the AO3400A threshold 2.7–6.7 ms after the LM5148 PG rises — after its soft start has
  finished and 5V_BUCK has taken over +5V. D204 (BAT46W) discharges it at once when PG_5V drops. A rising EXT
  edge alone never kills the sink; loss of external power (EXT low) re-enables it in µs via Q218.
- **Bus-power → external-power hand-over is make-before-break (review finding 3):**
  1. External power appears → `EXT_PWR_PRESENT` high; the sink stays on (PG_5V low) and keeps +5V up.
  2. VIN ramps (barrel 1.17 V/ms), LM5148 starts at 8 V and soft-starts 5V_BUCK; when 5V_BUCK exceeds +5V the
     LM74700 conducts. During the overlap both paths feed +5V: the TPS259470A blocks reverse current into
     VBUS, the LM74700 blocks reverse current into 5V_BUCK, so whichever is higher carries the load, no backfeed.
  3. PG_5V high + 2.7–6.7 ms → Q219 on → sink off → +5V carried by the buck alone (load step ≤ 3 A).
  4. Only now can SRC_PGOK go high (Q215/Q216), so a source enable can never cut the sink before the buck runs.
- **Interlock / mutual exclusion:** the source requires EXT_PWR_PRESENT AND PG5_DLY high, which is exactly the
  sink release term; in addition SRC_ON forces the sink off through Q220 in ~2 µs while the source LM74800
  HGATE needs ms to turn its FET on. Even if the two thresholds on SNK_PGD (Q215 vs Q219) differ, the explicit
  SRC_ON kill opens the sink long before the source conducts, so both are never on together.
- Loss at 3 A: 9·(8 mΩ·1.3 + 28 mΩ + 5 mΩ shunt) ≈ 0.39 W.

Why not a single eFuse: no stocked eFuse combines ≥ 30 V off-state, 3 A and reverse blocking at 5 V: TPS2663x
(60 V) has a 4.5 V minimum and a 15.5 V default UVLO, and only fixed 35 V OV clamp variants are in stock
(would pass up to 33 V to +5V); TPS2660 is 2.2 A; TPS25947 alone is 28 V abs max (< 31.1 V OVP trip).

## 6. Independent VBUS OVP (latched) → LAPTOP_OVP_N

- Senses **max(VBUS_LAPTOP, VBB_OUT)** through a BAV70 (100 V; BAT54C is only 30 V): catches a run-away converter
  (e.g. open Rtop, which would otherwise run to the 83.5 V OVP2) before the source switch closes.
- Divider 1.1M/46.4k + diode: trip = 1.242·(1 + 1100/46.4) + 0.45 = **31.1 V**; ≈ 29.9–32.3 V RSS (29.3–33.1 V
  with every corner stacked: ref 1.208–1.276 V, offset ±15 mV, 1 % resistors, Vf 0.35–0.55 V) — above the 28.7 V
  worst-case regulation, ≤ 34 V PMG1 VBUS abs max. C243 2.2 nF → 98 µs filter.
- **Load-dump margin (review finding 9):** a 5 A unplug at 28 V overshoots VBB_OUT by ≈ 5 A/(2π·3 kHz·220 µF)
  ≈ 1.2 V for ~100 µs; through the 98 µs filter the comparator sees ≈ 0.7 V of it (simulated first-order), i.e.
  ≤ 29.4 V against a ≈ 29.9 V (RSS) minimum trip — no false latch. Cost: a run-away (≤ 28 V/ms at the current
  limit) trips ≈ 2.6 V later; VBUS_LAPTOP stays protected by the 4 µs LM74800 backstop (31.7–33.6 V). Bench
  check the overshoot at 28 V / 5 A; if > 1 V, raise C243 to 4.7 nF.
- **TLV3011** (C2870632; open-drain, internal 1.242 V reference; TLV3012 would be push-pull). Output pull-up
  10k goes to **VBB_EN**. On a trip the output releases, 1N4148W + 4.7k drive IN+ to 2.0 V (> 1.242 V even with
  VBUS = 0) → **latched**. AO3400A inverts to LAPTOP_OVP_N (10k to +3V3).
- Effects: SRC_ON drops (source switch opens), the LM51770 EN AND drops (converter off, VBB_OUT discharged,
  VBB_PG low).
- **Reset only by VBB_EN low** (the latch pull-up source disappears). Latched instead of auto-retry because >30 V
  on the laptop port means a real hardware fault (feedback open, FET short, back-feed); auto-retry would
  re-apply the overvoltage periodically. Clearing requires a deliberate PMG1 VBB_EN cycle, which restarts from the
  5.1 V default and re-arms the latch. RP2350 has no path to VBB_EN.

## 7. VBUS_LAPTOP monitor and capacitance

- **INA226** (C49851, 44k stock) at **0x44** (A1 = VS, A0 = GND; power_rails uses 0x41, power_input INA237 0x45).
  Shunt 5 mΩ 1206 (RLM12FTCMR005, 1 W) between VBUS_LSW (IN+) and VBUS_LAPTOP (IN−): 5 A → 25 mV of ±81.92 mV, 0.125 W;
  positive = sourcing, negative = bus-powered sink. CURRENT_LSB = 0.5 mA → CAL = 0.00512/(0.5 mA·5 mΩ) = **2048**,
  POWER_LSB 12.5 mW. VBUS pin on the connector side (36 V max). ALERT unused.
- Connector-side capacitance (VBUS_LAPTOP + VBUS_LSW, no switch between them): 10 µF/50 V X7R + 2× 100 nF →
  ≈ 9 µF at 5 V, ≈ 4 µF at 28 V: inside **cSnkBulk 1–10 µF** for bus-powered attach, and small for fast
  vSafe0V/role swaps. **cSrcBulk ≥ 10 µF** is met behind the source switch (VBB_OUT ≈ 220 µF). VBUS TVS and the
  receptacle live on `usbc_muxes`.

## Thermal estimate (140 W, 20 V in)

| Item | Loss | Note |
|---|---|---|
| Q201 / Q203 / Q204 | 0.62 / 0.46 / 1.14 W | TDSON / VSONP on 2 oz pours + via arrays: ~35–45 K/W → ≤ +50 K at Q204 |
| L201 XAL1010-103 | 0.9 W | (7.2/15.5)²·40 K ≈ +9 K self-heating |
| RCS + RISNS | 0.41 W | 2512 |
| LM51770 | 0.1–0.5 W | VCC LDO; worst 48 V in at 5 V out: 11 mA·48 V = 0.53 W → +18 K (33.6 K/W) |
| Source FETs + 5 mΩ shunt | 0.39 W | |
| **Total hot zone** | **≈ 4.5 W** | 48 V in: ≈ 4.3 W |

Consistent with `power-budget.md` (5.5 W budget for buck-boost + path). Place a TMP1075 (sensors sheet) between
Q204 and L201; firmware derates the contract on temperature. Keep the zone away from the LM5148 stage and hub.

## Part list (this sheet)

| Ref | Part | LCSC | JLC stock | Note |
|---|---|---|---|---|
| U201 | TI LM51770DCPR | C43351171 | 1007 | buck-boost controller |
| Q201, Q202 | Infineon BSC0805LS | C534374 | 15000 | 100 V, 7.7 mΩ @4.5 V |
| Q203, Q204, Q217 | TI CSD18543Q3A | C840100 | 12215 | 60 V, 12 mΩ @4.5 V |
| L201 | Coilcraft XAL1010-103MED | C6358489 | 707 | 10 µH, Isat 17.5 A |
| R201 | TA-I RLP25FEGR004 2512 | C459681 | 15078 | 4 mΩ peak sense (3 W, 50 ppm; same as R303) |
| R202 | Yageo PE2512FKE070R008L | C2075410 | 1855 | 8 mΩ output sense |
| R243 | TA-I RLM12FTCMR005 1206 | C316225 | 201600 | 5 mΩ INA226 shunt (1 W; same as R415) |
| U202 | TI LM74800QDRRRQ1 | C3215600 | 4038 | source switch (also 2× on power_input) |
| Q213, Q214 | Infineon BSC026N08NS5ATMA1 | C5955453 | 5786 | 80 V, 2.6 mΩ (same as Q104–Q107) |
| U203 | TI SN74LVC1G11DBVR | C22046 | 13937 | 3-input AND |
| U204 | TI INA226AIDGSR | C49851 | 44390 | 0x44 |
| U205 | TI LM74502DDFR | C3236215 | 8157 | sink stage 1 |
| U206 | TI TPS259470ARPWR | C3662799 | 1538 | sink stage 2 eFuse |
| U207 | TI TLV3011AIDBVR | C2870632 | 7893 | OVP comparator + ref (TLV3011B has POR: see risks) |
| D202 | BZT52C5V1 | C173407 | 610k | |
| D203 | BAT54A | C130910 | 288k | |
| D205 | BAV70 | C68978 | 210k | basic |
| D201, D206 | 1N4148W | C81598 | 5.2M | basic |
| D204 | BAT46W | C83152 | 107k | PG_5V delay fast discharge |
| Q205–Q211, Q215, Q216, Q218–Q221 | AO3400A | C20917 | 959k | basic |
| R255 | 46.4 k 0402 | C5126026 | 175k | OVP divider |
| Q212 (discharge) | 2N7002 | C8545 | 1.6M | basic |
| Q217 | TI CSD18543Q3A | C840100 | 12215 | sink stage 1 (listed above with Q203/Q204) |
| C201–C204 | Taiyo HMK325C7475KN-TE 4.7 µF/100 V | C697607 | 330k | (47 µF VIN alu removed) |
| C205–C210, C233 | TDK C3225X7R1H106KT000E 10 µF/50 V | C432929 | 28k | |
| C211, C212 | KNSCHA 100 µF/35 V polymer | C2982822 | 7842 | 6.3×7 |
| R235 | 150 Ω 1 W 2512 | C2934049 | 52k | discharge |
| others | 0402/0603/0805 R/C | see `power_laptop.py` | ≥ 18k | mostly basic |

`python3 tools/bom_check.py` passes for every part on this sheet.

## Assumptions
- VIN 9–50.4 V from power_input; ≥ 140 W available only from inputs ≥ ~16 V (PD 20/28/48 V, barrel 19–24 V).
- PMG1 (pd_pmg1 sheet) drives VBB_EN, VBB_VSEL0..2, LAPTOP_SRC_EN, LAPTOP_SNK_EN as 3.3 V push-pull GPIOs,
  provides VBUS discharge and its own VBUS OVP/OCP; laptop connector + TVS on usbc_muxes.
- EXT_PWR_PRESENT is a 3.3 V push-pull signal (74LVC1G32 on power_input).
- The laptop drops to standby current before accepting a lower voltage (PD sink behaviour).

## Open issues / risks
1. **Loop compensation** is a datasheet-equation starting point; the Cm/Rs doublet must be checked for
   conditional stability (TI model in SIMPLIS/PSpice, bode measurement). Fallback: Cm 2.2 µF (2× faster slew,
   still ≤ 10 mV/µs) or FPWM.
2. **LM74800 at VS = 5.1 V**: gate drive is specified 7 V for 3–5 V supply while the CAP UVLO rising threshold
   is up to 7.9 V — confirm the source switch closes at vSafe5V on the bench. Fallbacks: default 5.2 V
   (Rbot 23.7k), or LM74502H + discrete reverse comparator.
3. **Dead-battery bus power**: LAPTOP_SNK_EN must be driven high by PMG1 from its VBUS-powered domain while +3V3
   is absent; otherwise the deck can never boot from the laptop. Coordinate with pd_pmg1.
4. **PSM down-steps** rely on the laptop load/PMG1 VBUS discharge; with no load VBB_OUT stays at the old
   voltage until VBB_EN is cycled (then the 150 Ω discharge runs). FPWM option exists (DNP R) but returns
   energy to VIN.
5. OVP window (≈ 29.9–32.3 V RSS) is driven by the TLV3011 1 % reference + 15 mV offset; tighter would need a
   separate 0.5 % reference. The non-B TLV3011 has **no power-on reset**: its output is undefined while +3V3
   ramps, so with VBB_EN already high (PMG1 alive on laptop VBUS through a +3V3 brownout) the latch can set
   spuriously. Use TLV3011B (same pinout) when stocked, or have firmware cycle VBB_EN after any +3V3 recovery.
10. **OVP1/nFLT in PSM during VSEL down-steps** (review note 15): the "OVP1 masked in PSM" sentence in SNVSCL2A
    §8.3.15 may mean pulse-skipping operation rather than MODE = low. If nFLT asserts while VBB_OUT lags a
    down-step, VBB_PG drops and SRC_ON opens on every 28→5 V step. Bench-verify a 28→5 V step at standby load;
    fallback FPWM (DNP 0 Ω) or firmware blanking.
6. 12 V input cannot deliver 140 W (current limit) — PMG1 policy must cap the offer by input source (already
   in power-budget.md).
7. Footprints to check before layout: XAL1010 (EasyEDA name references XAL1010-332ME land pattern), LM51770
   HTSSOP-38 exposed pad, TPS259470 RPW HotRod pads, polymer/alu caps use KiCad CP_Elec footprints (6.3×7.7,
   10×10) — compare with the KNSCHA 6.3×7 / SamYoung 10×10 land patterns.
8. Layout: minimise the two hot loops (VIN caps–Q201–Q202, BB_PSO caps–Q204–Q203), Kelvin-route CSA/CSB, ISNSP/N
   and INA226 IN± , keep BB_FB/BB_FBM small and away from SW nodes, 2 oz copper + via arrays under the FETs.
9. Optional RC snubbers on BB_SW1/BB_SW2 and gate resistor values (0 Ω placeholders R203–R206) to be tuned for EMI.

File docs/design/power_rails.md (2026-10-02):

# odeck-10 — power rails sheet (`power_rails.kicad_sch`, refs 300+)

Source: `hardware/odeck-10/sheets/power_rails.py` (generated, netlist-verified; second pass after
`docs/review/power.md`). Stock figures are from the JLC parts
API on 2026-10-02. Re-check them before ordering.

## Topology

```
VIN 9-50 V ──┬─ D301 BAT46W ─► LM5148 VIN pin (controller bias only)
             └─ Q301 BSZ070N08LS5 / Q302 BSC0805LS ─ L301 4.7 uH ─ RS303 4 mΩ ─► 5V_BUCK (5.13 V)
                                                                                │  6x 47 uF
                     LM74700-Q1 + Q303 BSC0901NS (ideal diode, source = 5V_BUCK) ▼
                                                                              5V_OR ─ R312 2 mΩ (INA226) ─► +5V
                                                     laptop VBUS sink switch (power_laptop) ──────────────► +5V
+5V ─► TPS62933  (1.2 MHz) ─► +3V3  (3.33 V, 3 A part, ~2.2 A max load)
+5V ─► TPS62933P (1.2 MHz) ─► +1V15 (1.154 V, USB7206C VCORE), EN = +3V3 divider, PG ─► RAILS_PG
```

Global nets used: `VIN`, `+5V`, `+3V3`, `+1V15`, `I2C_SYS_SCL`, `I2C_SYS_SDA`, `RAILS_PG`, `PG_5V`, `GND`.
PWR_FLAGs on `+5V`, `+3V3`, `+1V15`. **`+1V1` is not created** (see "Rails not needed").

Power-good outputs (both global in `nets.py`):
- `RAILS_PG`: open drain with 100 k to +3V3. It is high when +1V15 is in regulation, which implies +3V3 is up.
  usb_hub wire-ORs it onto `HUB_RESET_N` through a Schottky, so the hub is held in reset until VCORE is good.
- `PG_5V`: LM5148 PG, open drain, **100 k pull-up to 5V_BUCK** (≈ 5.1 V level). Consumed on power_laptop to release
  the bus-power sink switch (and to permit the source switch) only once the buck regulates. The pull-up rail is
  deliberately 5V_BUCK: an unpowered LM5148 cannot hold its open-drain PG low, so a pull-up to an always-present
  rail (+3V3/+5V, which the laptop keeps alive in bus-powered mode) would read "good" exactly during the hand-over
  window while VIN ramps. With 5V_BUCK it is 0 V whenever the buck is off. Not for 3.3 V-only inputs (5.1 V level);
  consumers must not source current into it (power_laptop uses FET gates only).

## 1. Backfeed problem and its solution

In bus-powered mode the laptop feeds `+5V` through the sink switch while VIN is absent. With a plain synchronous
buck, +5V would reach VIN through L301 and the body diode of the high-side FET, putting about 4.3 V on VIN. That
voltage would:
- Wake the LM51770 buck-boost (UVLO 3.5 V).
- Bias the LM5148 (VIN 3.5 V min).
- Forward-bias the LM5148's internal VOUT→VIN ESD diode.
- Drain the laptop's 15 W budget into VIN capacitance and loads.

The fix:
1. **The buck regulates a private node, `5V_BUCK`.** Every LM5148 pin that senses or biases from the output is on
   this node, never on +5V. That covers FB divider, VOUT/ISNS+, VCCX and the PG pull-up.
2. **An ideal diode connects `5V_BUCK` to `+5V`:** LM74700-Q1 plus BSC0901NS (30 V, 2.4 mΩ at 4.5 V), with the source
   on the buck side.
   - **VIN absent:** ANODE (5V_BUCK) sits at 0 V, so the LM74700 is unpowered and the gate is off. The FET body diode
     points 5V_BUCK→+5V, so it is reverse-biased and no current flows back.
   - **Buck running:** the forward drop is regulated to 20 mV (0.16 W at 8 A).
   - **Reverse current:** it is detected at −11 mV, and the gate is discharged with 2.37 A in under 0.75 µs.
3. **The LM5148 runs in diode-emulation mode** (PFM/SYNC = VDDA). The low-side FET cannot sink negative inductor
   current, so the buck cannot pump energy from its output back into VIN at light load or during an overvoltage.
4. **VIN at a few volts.**
   - The EN/UVLO divider (100 k / 14.3 k, 1.0 V threshold with 10 µA hysteresis current) starts the controller at
     8.0 V and stops it at 7.0 V. Including tolerance, that is 7.6–8.4 V on and 6.6–7.4 V off.
   - Below that the LM5148 sits in standby (124 µA) and never switches, so a 5 V-only PD-in contract or a dying
     barrel brick cannot make it run in deep dropout.
   - D301 (BAT46W, 100 V) in series with the controller's VIN pin follows the TI datasheet recommendation (SNVSC01
     §8.3.1). It stops the internal VOUT→VIN ESD diode from discharging 5V_BUCK into a VIN that collapses faster than
     the output.
   - The power stage has no such diode. The only charge that can flow back into a collapsing VIN is the buck's own
     ~150 µF on 5V_BUCK, through Q301's body diode. +5V stays isolated behind Q303.
5. **Handover when external power arrives while bus-powered (make-before-break, review finding 3).**
   1. `EXT_PWR_PRESENT` rises (input side) but does **not** open the sink switch on its own.
   2. VIN ramps, the LM5148 passes its 8 V UVLO and soft-starts (1.9–4.6 ms) into the unloaded 5V_BUCK.
   3. When 5V_BUCK rises above +5V (≈5.0 V from the laptop), Q303 conducts and +5V rises to ≈5.11 V. During the
      overlap the TPS259470A (reverse-current blocking) and the LM74700 form a two-way ideal-diode OR on +5V;
      neither source can back-feed the other. If laptop VBUS is higher (up to 5.5 V) the sink keeps carrying
      the load and the LM74700 simply stays off.
   4. PG_5V goes high; after the 2.7–6.7 ms RC on power_laptop the sink switch opens (`EXT_PWR_PRESENT` AND
      `PG_5V`) and the buck takes the full load (≤ 3 A step, ≈ 60 mV dip).
   No pre-bias issue arises, because 5V_BUCK starts from 0 V.
6. **External power lost while sourcing.** +5V droops while the laptop takes over (FRS or PR_Swap, decided on other
   sheets). The 330 µF polymer plus ceramics on +5V bridge about 150 µs at ≤2 A (≈0.9 V droop). At full 8 A load they
   cannot, so a brief brownout or reset there is expected.

## 2. +5V buck (LM5148) calculations

Requirements:
- VIN 9–50.4 V (EPR 48 V + 5 %). The TVS clamps on power_input are 51/48 V standoff and break down at about 57–63 V.
- VOUT 5.13 V at 8 A. Power budget: 37 W / 7.4 A max.

| Item | Value | Calculation |
|---|---|---|
| Output voltage | 5.127 V (≈5.11 V on +5V after the 20 mV OR drop) | VREF 0.8 V × (1 + 64.9 k / 12 k). Chosen above 5.0 V for USB-A and downstream port drops; GL3224 needs 4.75–5.25 V |
| Switching frequency | 299 kHz | RT = (10⁶/f − 53)/45 = 72.9 k → 73.2 k. Lower fsw keeps switching and Coss losses at 48 V manageable |
| Duty / on-time | D = 0.10 (50 V) … 0.59 (9 V); tON(min) = 340 ns ≫ 50 ns | Dropout (tOFF(min) 90 ns) begins at ~5.3 V, below UVLO |
| Inductor | 4.7 µH, Sunlord MWSA1206S-4R7MT, 15 A Irms, 24 A Isat, 9 mΩ | ΔI = Vo(1−Vo/Vin)/(L·f) = 3.25 A p-p at 48 V, 2.7 A at 20 V, 1.6 A at 9 V |
| Slope compensation | L_ideal = Vo·Rs/(24·f) = 2.85 µH; actual 1.65× | Over-compensated, so stable at all duty cycles |
| Current sense | 4 mΩ 2512 1 % (RLP25FEGR004), Kelvin | VCS-TH 49/60/73 mV gives peak limit 12.3/15.0/18.3 A. Min DC limit at 48 V = 12.3 − 1.63 = 10.6 A (≥ 1.3 × 8 A). A 5 mΩ shunt would give only 8.2 A minimum, too tight |
| Short-circuit peak | 18.3 A + 48 V × 45 ns / 4.7 µH = 18.7 A | < 24 A Isat. FETs fine. Hiccup after 512 cycles |
| Output capacitance | 6 × 47 µF 10 V X7R 1210 on 5V_BUCK (~150 µF effective at 5 V) + 330 µF polymer + 2 × 22 µF on +5V | Ripple ΔI/(8·f·C) = 3.25/(8 × 300k × 150µ) = 9 mV. Cap RMS 0.94 A total |
| Load step 4 A | ≈ ΔI/(2π·fc·C) = 4/(2π × 18k × 430µ) ≈ 80 mV (1.6 %) | |
| Compensation | RCOMP 10 k, CCOMP 10 nF, CHF 100 pF | fc = 2π-form: RCOMP = 2π·fc·(Vo/VREF)·(Rs·Gcs/gm)·C → fc ≈ 18 kHz with 430 µF, ≈ 52 kHz with 150 µF only (light load: the LM74700 linear-regulates, which partly decouples the far-side bulk). Zero 1.6 kHz, pole 159 kHz |
| Input capacitance | 4 × 4.7 µF 100 V X7S 1210 + 2 × 100 nF 100 V 0603. **No alu here** (review finding 4): VIN total ≤ 100 µF for USB PD cSnkBulkPd; the single 47 µF damping alu for VIN sits on power_input (stability calc there) | ICIN,rms = Io·√(D(1−D)) = 2.5 A (48 V) … 3.96 A (9 V), split over 4 MLCCs. ΔVIN ≈ D(1−D)Io/(f·C) = 0.42 V p-p at 48 V (~6 µF effective) |
| Soft start | 3 ms internal | Inrush into 5V_BUCK ≈ 150 µF × 5.1 V / 3 ms = 0.26 A (+5V is behind the diode) |
| UVLO | on 8.0 V, off 7.0 V | RUV1 = ΔV/IHYS = 1 V/10 µA = 100 k (0805, VIN side, 150 V rating); RUV2 = 100k × 1/(8 − 1) = 14.3 k |
| Bias | VCCX = 5V_BUCK (> 4.3 V switches VCC to VCCX) | The VIN LDO would otherwise dissipate (14 + 16 nC) × 5 V × 300 kHz × 48 V / 5 V ≈ 0.4 W, plus IQ |
| CNFG | 41.2 k: primary, dual random spread spectrum ON | |
| CBOOT | 100 nF | ΔV = Qg/C = 14 nC / 100 nF = 0.14 V |
| Snubber | 2.2 Ω + 1 nF across SW–GND, **DNP** | Fit only if SW ringing at 48 V exceeds ~70 V |

### MOSFETs
- Q301 HS is the **BSZ070N08LS5**: 80 V, 9.4 mΩ max at 4.5 V, Qsw 6.9 nC, Qg 14 nC at 4.5 V, 3.3 × 3.3 mm. It is
  logic-level because LM5148 gate drive is 5 V. Low Qsw matters because switching loss dominates at 10 % duty.
- Q302 LS is the **BSC0805LS**: 100 V, 8.5 mΩ max at 4.5 V, Qrr 12 nC, 5 × 6 mm. Conduction dominates (89 % duty).
- Voltage margin: VIN max 50.4 V vs 80 V. The VDS spike must stay below 80 V, so layout needs a tight hot loop with
  the 100 nF caps at the HS drain. RHO is a 0 Ω placeholder and the snubber is DNP.

### Loss / efficiency at 8 A (estimate)
Assumptions: Rds(on) at 4.5 V max × 1.45 hot; DCR × 1.25; core loss 0.25 W; switching loss from Qsw with HO
1.06 Ω / 0.5 Ω + Rg; Coss loss ≈ ½ Qoss·V·f; Qrr·V·f.

| VIN | HS | LS | Switching + Coss + Qrr | Inductor | Shunt | Buck η | + OR FET 0.20 W + INA shunt 0.13 W | Total loss |
|---|---|---|---|---|---|---|---|---|
| 12 V | 0.39 | 0.44 | 0.24 | 0.97 | 0.26 | 94.4 % | **93.7 %** | 2.8 W |
| 20 V | 0.23 | 0.59 | 0.43 | 0.98 | 0.26 | 94.0 % | **93.3 %** | 3.0 W |
| 28 V | 0.17 | 0.65 | 0.66 | 0.98 | 0.26 | 93.5 % | **92.8 %** | 3.2 W |
| 48 V | 0.10 | 0.71 | 1.36 | 0.98 | 0.26 | 92.0 % | **91.4 %** | 3.9 W |

- The ~93 % target is met for barrel (12–24 V) and 20/28 V PD inputs at full load, and exceeded at typical loads.
- At 48 V × 8 A (240 W charger, all ports maxed) the 5V path dissipates ≈3.9 W, about 1.1 W over the power-budget
  figure.
- Hot spots:
  - Q301 at ~1.2–1.4 W in 3.3 × 3.3 mm. Needs a copper pour and via array, θJA ≈ 40 K/W → +50 K.
  - L301 at ~1 W (13.5 × 12.6 mm).
  - Q302 at ~0.7 W.
- Put a TMP1075 next to Q301/L301 (already planned on the sensors sheet). Firmware should derate charge-mode ports
  first when VIN = 48 V and the stage runs hot.

## 3. +3V3 (TPS62933F, C5219272)
- +5V → 3.33 V (31.6 k / 10 k). RT = GND sets 1.2 MHz.
- L = 2.2 µH MWSA0503S-2R2MT: ΔI = 3.33 × (1 − 3.33/5.13)/(2.2 µ × 1.2 M) = 0.44 A.
- Cout 3 × 22 µF 25 V 0805 X5R, about 35 µF effective (TI table: 30 µF typ, 10 µF min).
- Cin 2 × 10 µF + 100 nF.
- **Soft start:** CSS 22 nF → 22 n × 0.8 / 5.5 µA = 3.2 ms (3.9 ms worst case). This satisfies the RTL8156BG
  3.3 V rise (0.5–10 ms) and the USB7206C (≤ 5 ms unless RESET_N is held).
- **EN divider** 100 k / 39 k (EN 1.21 V rising): starts at +5V ≥ 4.31 V and stops around 4.0 V, so the rail cannot
  limp along on a collapsing bus-powered +5V.
- **Load:**
  - Hub VDD33 0.1 A, RTL8156BG 3.3 V 0.09 A, TUSB1064 + TUSB1046 ~0.3 A, PMG1/TPS26750 ~0.05 A, RP2350 + flash
    ~0.06 A, LCD ~0.1 A, SD + microSD up to 0.3 A, sensors and LEDs.
  - Total ≈ 1–1.5 A typ, ≤ 2.2 A worst case, for 0.3–0.7 W loss.
  - GL3224 is not on this rail (it is 5 V-fed).

## 4. +1V15 (TPS62933P, C5219254) — USB7206C VCORE
- **Datasheet (DS00003850F §9.2):** VCORE 1.09–1.21 V (1.15 V nominal), so the net name +1V15 is correct.
- **Current:** 410 mA + 179 mA per active SS port, ≈ 1.31 A with 5 ports at 10G. The 3 A part is used at ≤ 2 A.
- **Output:** 4.42 k / 10 k → 1.154 V. With ±1 % VREF and 1 % resistors that is about ±1.5 % (1.137–1.171 V), well
  inside the window.
- **Sequencing (§9.6.1):** VCORE must rise after or together with VDD33. EN is therefore taken from +3V3 through
  12 k / 10 k, which enables at 2.66 V typ and 2.82 V max with +3V3 at 3.33 V.
  - Rise times must be ≤ 5 ms. The TPS62933P has a fixed 2 ms soft start.
  - The PG output (85/90 % thresholds, 70 µs delay) drives `RAILS_PG`.
- L = 1.5 µH MWSA0503S-1R5MT: ΔI = 0.50 A p-p, 17 % of 3 A. That is above the ≥ 10 % peak-current-mode guideline.
- **Output capacitance:** 4 × 22 µF 6.3 V 0603 here plus the hub's 9 × (4.7 µF + 0.1 µF + 1 nF) on the hub sheet. The
  internal compensation wants more capacitance at low VOUT, so ≈ 80 µF effective is provided here.
- **Why from +5V and not +3V3:** one conversion instead of two (≈ 85 % vs ≈ 80 % overall). It also avoids a 5.5 V-max
  part on the +5V rail (TPS62A02 / TLV62569), which could see laptop VBUS transients in bus-powered mode. And it
  shares a part family with +3V3.

## 5. Rails not needed / handled elsewhere
- **+1V1: not created.** The RP2350 core (DVDD 1.1 V) comes from its on-chip switching regulator, fed from +3V3
  (VREG_VIN). Its inductor and caps belong on the MCU sheet.
- **RTL8156BG needs an external 0.95 V rail.**
  - Datasheet §5.8/§5.13/§7: only the RTL8156B**GS** has the built-in switching regulator. The RTL8156BG (the stocked
    part, C41376388; the BGS is not stocked) needs 0.95 V (0.92–0.98 V, ±3 %, ≤ 650 mA max / 364 mA typ) on AVDD09,
    DVDD09, U2VDD09 and U3VDD09.
  - It enables its regulator itself through **pin 5 POW_EXT_SWR** (active high), with a 0.95 V rise of 0.5–2.2 ms
    and a ≥ 50 ms off-on interval. DVDD09_UPS must stay isolated.
  - Because the enable comes from the PHY and the rail should be dedicated, it belongs on the **ethernet sheet**. A
    suitable choice is TLV62569 (C141836, 2 A, 242k stock) from +3V3 with EN = POW_EXT_SWR and FB divider
    0.6 × (1 + 5.83 k / 10 k) ≈ 0.95 V. The 1–2 ms soft start meets the 0.5–2.2 ms rise.
  - Budget: 0.95 V × 0.65 A ≈ 0.6 W max from +3V3, which is already inside the +3V3 headroom above.
- **GL3224:** single 4.75–5.25 V supply on its VBUS pin, with internal 5→3.3 V and 3.3→1.2 V regulators (datasheet
  §4.6, §5). It is fed from +5V with no external sequencing. In bus-powered mode +5V can sag below 4.75 V under heavy
  load, so watch the sink-switch drop.

## Part list (this sheet)

| Ref | Part | LCSC | JLC stock | Type |
|---|---|---|---|---|
| U301 | TI LM5148RGYR (VQFN-24) | C7470701 | 57 474 | ext |
| Q301 | Infineon BSZ070N08LS5 (TSDSON-8FL) | C534678 | 3 281 | ext |
| Q302 | Infineon BSC0805LS (TDSON-8) | C534374 | 15 000 | ext |
| L301 | Sunlord MWSA1206S-4R7MT 4.7 µH 15 A | C408521 | 879 | ext |
| R303 | TA-I RLP25FEGR004 4 mΩ 2512 | C459681 | 15 078 | ext |
| D301 | Diodes BAT46W-7-F | C83152 | 107 563 | ext |
| C301–C304 | Taiyo HMK325C7475KN-TE 4.7 µF 100 V 1210 | C697607 | 330 431 | ext (47 µF alu removed) |
| C305–C306 | Samsung CL21B104KCFNNNE 100 nF 100 V X7R 0805 | C28233 | 1 251 499 | basic |
| C309–C314 | Murata GRM32ER71A476KE15L 47 µF 10 V 1210 | C84494 | 56 437 | ext |
| C315 | Murata GCM21BC72A105KE36L 1 µF 100 V 0805 | C126585 | 30 481 | ext |
| U302 | TI LM74700QDBVTQ1 (SOT-23-6) | C2653623 | 5 563 | ext |
| Q303 | Infineon BSC0901NS (TDSON-8) | C152424 | 5 000 | ext |
| R312 | TA-I RLP25FEGR002 2 mΩ 2512 | C459679 | 52 095 | ext |
| U303 | TI INA226AIDGSR (VSSOP-10) | C49851 | 44 400 | ext |
| C323 | 330 µF 6.3 V polymer 6.3×6 (MA6.3V330M6X6) | C54321566 | 6 338 | ext |
| U304 | TI TPS62933FDRLR (SOT-583, forced PWM) | C5219272 | 2 524 | ext; keep the F variant (RTL8156BG needs PWM) |
| U305 | TI TPS62933PDRLR (SOT-583) | C5219254 | 7 010 | ext |
| L302 | Sunlord MWSA0503S-2R2MT 2.2 µH | C408408 | 7 617 | ext |
| L303 | Sunlord MWSA0503S-1R5MT 1.5 µH | C408407 | 2 445 | ext |
| R (E96) | 73.2 k C26986, 14.3 k C25855, 64.9 k C26984, 41.2 k C100420, 31.6 k C11463, 4.42 k C52269 | | all > 7k | ext |
| R/C basic | 10 k C25744, 12 k C25752, 39 k 0603 C23153, 100 k C25741, 100 k 0805 (150 V) C149504, 0 Ω C17168; 100 pF C1546, 10 nF C15195, 22 nF C1532, 100 nF C1525 / C14663 (50 V 0603), 4.7 µF C19666, 10 µF 25 V C15850, 22 µF 25 V 0805 C45783, 22 µF 6.3 V 0603 C59461 | | | basic |

DNP: R302 2.2 Ω 0805 and C308 1 nF 100 V 0603 (SW snubber).

## Thermal / loss summary (worst case, everything maxed)
| Block | Loss |
|---|---|
| 5V buck + OR + shunt at 8 A | 2.8 W (12–20 V in) … 3.9 W (48 V in) |
| +3V3 at 2.2 A | ~0.7 W |
| +1V15 at 1.31 A | ~0.3 W |
| **Sheet total** | **≈ 3.8–4.9 W** (typ. 1.5–2 W at 3–4 A on +5V) |

## Assumptions
- External power always gives VIN ≥ 9 V. The UVLO is 8 V, so 5 V-only PD contracts do not run the 5 V buck; that is
  intended.
- +5V loads on other sheets add ≥ 50 µF ceramic plus bulk. The USB-A ports need ≥ 120 µF each per the USB spec.
- The I2C_SYS pull-ups and the I2C address plan are owned by the MCU sheet.
  - Addresses: INA226 here at **0x41** (A1 = GND, A0 = VS); INA237 on VIN at 0x45 (power_input); laptop-VBUS
    INA226 at 0x44 (power_laptop); TMP1075s at 0x48–0x4F.

## Open issues / risks
1. ~~`RAILS_PG` → `HUB_RESET_N`~~ resolved: `RAILS_PG` is global and usb_hub wire-ORs it through a Schottky.
2. **RTL8156BG 0.95 V regulator is missing from the plan.** It must be added on the ethernet sheet (§5). The draft
   docs assumed an internal regulator.
3. **48 V corner:** HS FET ~1.3 W in 3.3 × 3.3 mm. Validate the temperature on the prototype. Fallback: BSC0805LS
   (5 × 6) for Q301 as well, which costs +0.2 W switching loss but spreads heat better. Alternatively lower fsw to
   250 kHz with the same L, giving 3.9 A ripple, still within limits.
4. **Inductor stock:** MWSA1206S-4R7MT has 879 in stock. Drop-in alternate: Bourns SRP1265A-4R7M (C780205, 8.4 mΩ,
   28 A sat), but it shares stock with the buck-boost. Check the footprint, since both are 13.5 × 12.5 mm class.
5. **Loop stability with the ideal diode in the output path** needs a bench Bode plot. At light load the LM74700
   regulates the OR-FET linearly, so the +5V bulk is partly decoupled and fc moves toward ~50 kHz (< fsw/5).
6. **Hold-up on loss of VIN at high load** is not covered (330 µF ≈ 150 µs at 2 A). It depends on the PR_Swap/FRS
   policy.
7. **GL3224 4.75 V minimum in bus-powered mode** depends on the sink-switch/cable drop on power_laptop.
8. **Tooling note:** `tools/import_lcsc.sh` runs `kicad-cli sym upgrade` without `--force`, so newly imported symbols
   stay in easyeda's 2-space format and `fix_pins.py` cannot find them. This sheet worked around it with
   `kicad-cli sym upgrade --force` under the lib lock. The script should add `--force`.

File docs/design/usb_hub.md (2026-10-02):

# odeck-10 — USB hub sheet (`usb_hub.kicad_sch`, refs 600+)

Source: `hardware/odeck-10/sheets/usb_hub.py` (generated, netlist-verified). References:
- USB7206C datasheet DS00003850F (cited as "DS").
- AN2935 rev C, *Configuration of USB7206/USB7206C/…*.
- USB7206 Hardware Design Checklist DS00003336A. The USB7206C checklist PDF is blocked behind a 403. The USB7206 and
  USB7206C share pinout and strap tables.

Stock figures are from the JLC parts API on 2026-10-02.

## Block
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

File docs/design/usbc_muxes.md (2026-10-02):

# odeck-10 — usbc_muxes sheet

Source: `hardware/odeck-10/sheets/usbc_muxes.py` (generates `usbc_muxes.kicad_sch`, ref_base 500, A1).
Status: first schematic pass, 2026-10-02. `build_all.py usbc_muxes` gives `netlist verify: OK`.
`tools/bom_check.py`: every part on this sheet is a JLC part with stock ≥ 5 (none consigned).
Datasheets used: TI SLLSF48C (TUSB1064), SLLSEW2E (TUSB1046-DCI), SLVSH00 (TPD4S480), SLVSDK3C (TPD6S300),
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

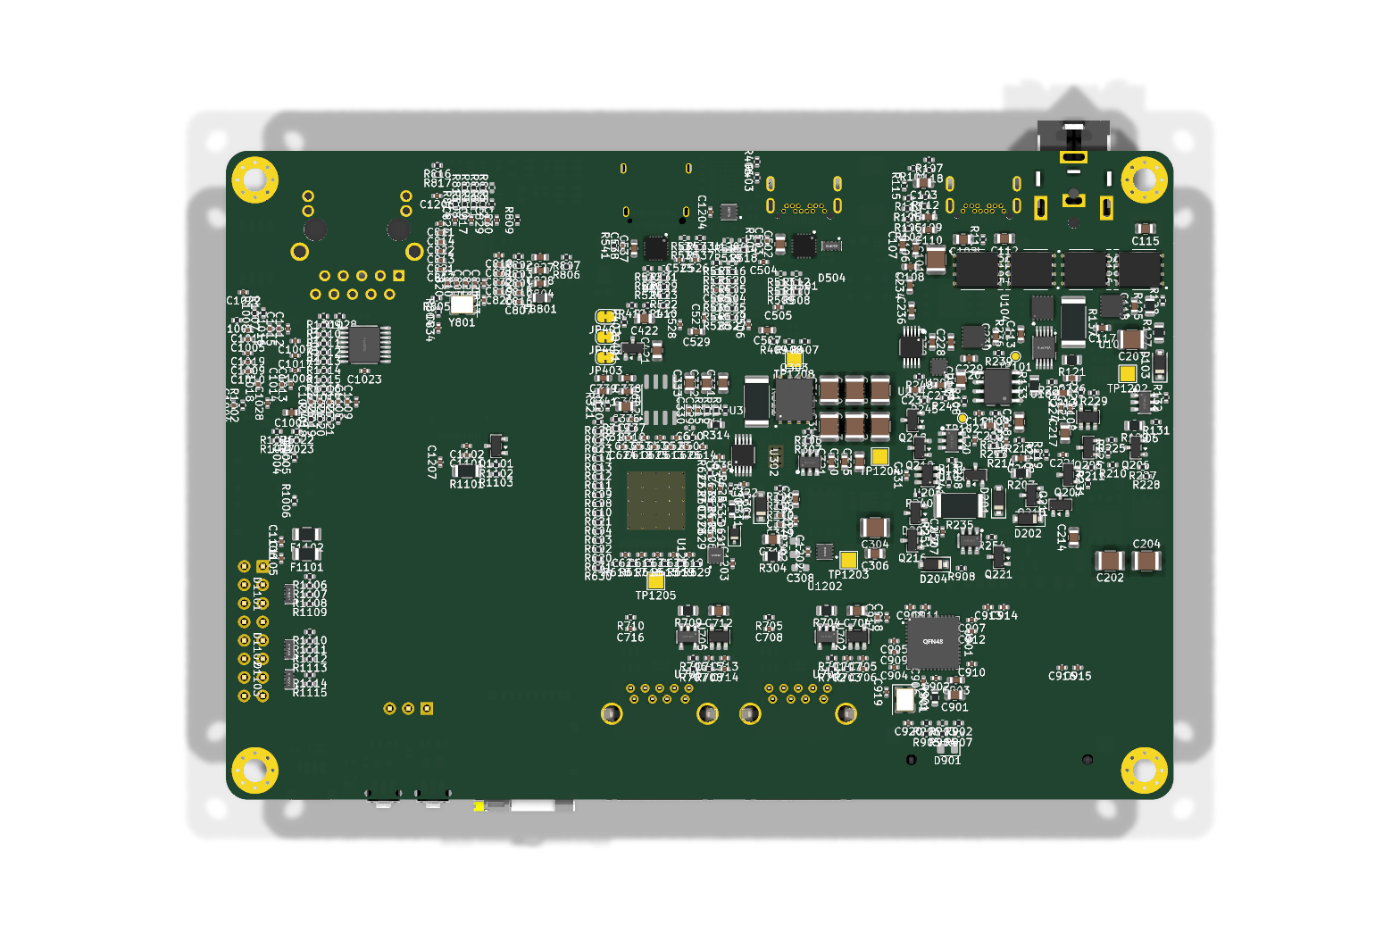
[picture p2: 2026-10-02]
docs/images/odeck-10-bottom.png

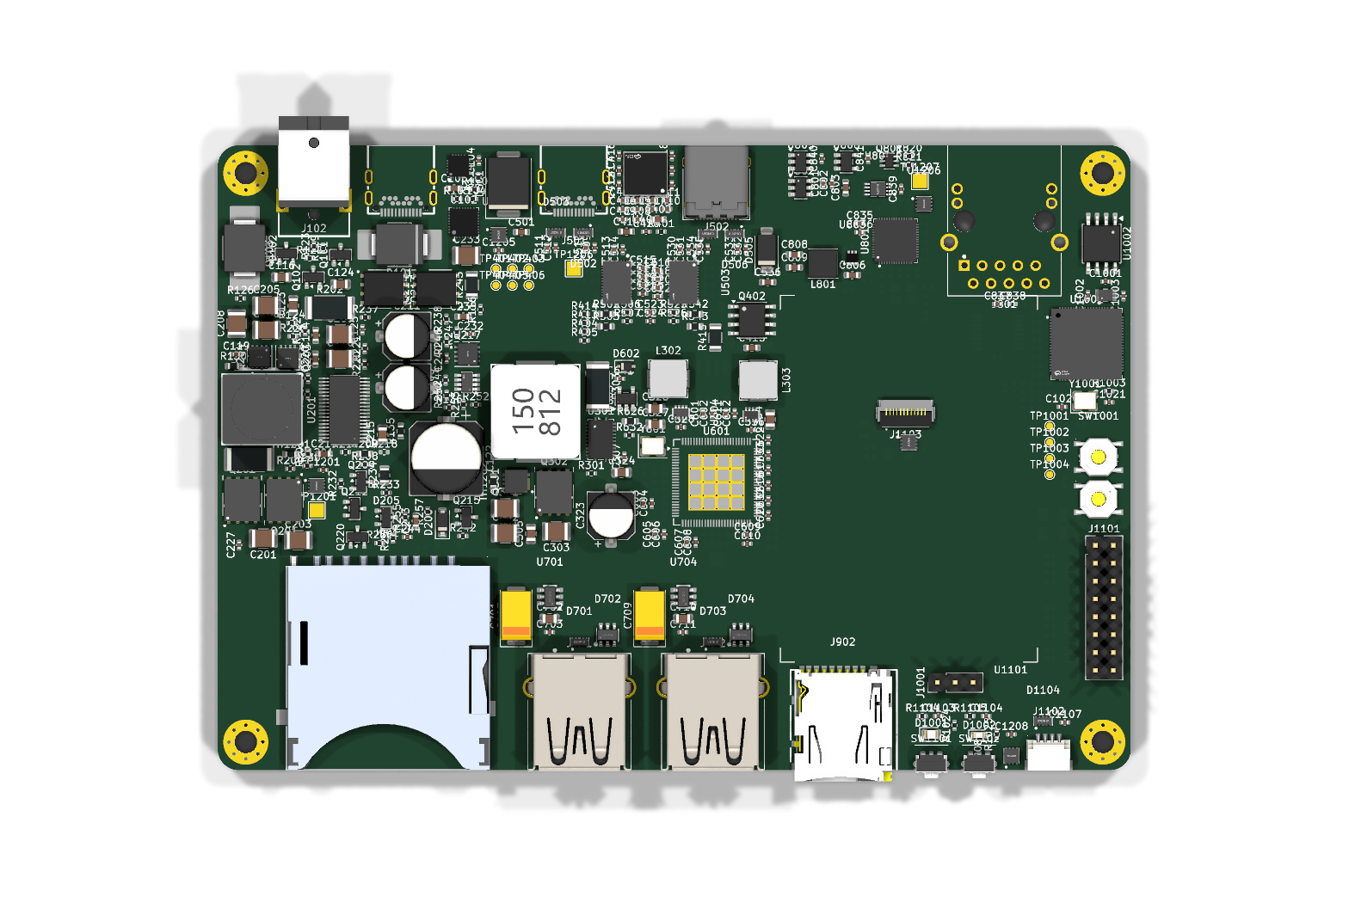
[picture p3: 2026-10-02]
docs/images/odeck-10-top.png

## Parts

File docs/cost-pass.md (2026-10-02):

# odeck-10 — JLC extended-part cost pass (2026-10-02)

JLC charges ~$3 per unique **extended** (non-basic) LCSC part per assembly order. This pass swapped every
generic passive that has a JLC **basic** equivalent with equal-or-better specs (same value, same or larger
voltage/power rating, same-or-better dielectric/tolerance/TCR), and merged duplicate extended parts.
Net connectivity is unchanged (`build_all.py`: netlist verify OK); `tools/bom_check.py`: 0 failing.

## Result

| | Before | After | Delta |
|---|---|---|---|
| Unique LCSC parts | 187 | 181 | −6 |
| Extended unique parts | 129 | 114 | **−15** |
| Extended-part fee per order | ~$387 | ~$342 | **−$45 / order** |
| Parts cost per board (qty-1 prices) | $161.91 | $161.88 | −$0.03 |

The JLC basic library is now small (e.g. 0402 resistors: ~30 basic values, all E6/E12-ish; no basic
zener, NTC, PTC, dual FET, power inductor, ≥ 0.1 µF/100 V ceramic below 0805, or 2512 resistor), so most
remaining extended parts are ICs, connectors, power parts or precision values with no basic equivalent.

## Swaps

| Ref(s) | Old LCSC | New LCSC (basic unless noted) | Why equivalent |
|---|---|---|---|
| C102, C103, C112, C115, C116, C124, C214, C305, C306, C502 | C15725 CL10B104KC8NNNC 100 nF 100 V X7R **0603** | C28233 CL21B104KCFNNNE 100 nF 100 V X7R **0805** | Same C/V/dielectric/tolerance; no basic 100 V 100 nF in 0603, so footprint 0603→0805 (HV decoupling, power zone not space-critical). |
| C243 (OVP_DIV filter) | C1531 2.2 nF 50 V X7R 0402 | C1604 2.2 nF 50 V X7R **0603** | Same value/V/X7R; node < 3 V. |
| C239 (SNK_DVDT) | C1536 3.3 nF 50 V X7R 0402 | C1613 3.3 nF 50 V X7R **0603** | Same value/V/X7R; dV/dt pin is low voltage. |
| C223 (LM51770 COMP zero) | C1542 6.8 nF 50 V X7R 0402 | C1631 6.8 nF 50 V X7R **0603** | Same value/V/X7R; keep it next to the COMP pin. |
| C837 (ETH magnetics CT) | C76967 GRM1555 390 pF C0G 50 V 0402 | C282239 CC0402JRNPO9BN391 390 pF C0G 50 V 0402 *(ext, merged)* | Identical spec; merged with the pd_pmg1 CC caps (C416–C419). |
| R304 (LM5148 UVLO top, VIN) | C96346 RC0805FR-07100KL 100 k 1 % 0805 150 V | C149504 0805W8F1003T5E 100 k 1 % 0805 150 V | Identical spec (already used on power_input). |
| R130 (BAR_MON ladder), R314 (3V3_EN) | C25783 39 k 1 % 0402 | C23153 39 k 1 % **0603** | Same value, 1 %, 100 ppm; 0402 39 k is extended. |
| R135 (PD_MON ladder) | C25918 7.5 k 1 % 0402 | C23234 7.5 k 1 % **0603** | Same value, 1 %, 100 ppm. |
| R626 (hub VBUS sense) | C36871 68 k 1 % 0402 | C23231 68 k 1 % **0603** | Same value, 1 %, 100 ppm. |
| R633 (hub VBUS_DET attenuator) | C25897 49.9 k 1 % 0402 | C23184 49.9 k 1 % **0603** | Same value, 1 %, 100 ppm. |
| R901 (GL3224 RTERM) | C137948 RC0402FR-07680RL 680 Ω 1 % | C23228 0603WAF6800T5E 680 Ω 1 % **0603** | Same value/tolerance. Keep the short GND return. |
| R137 (VIN shunt, INA237) | C844691 WSL25122L000FEA18 2 mΩ 1 % 2 W ±275 ppm 2512 | C459679 RLP25FEGR002 2 mΩ 1 % **3 W ±50 ppm** 2512 *(ext, merged)* | Better power and TCR; same footprint; merged with R312. |
| R201 (LM51770 peak sense) | C844693 WSL25124L000FEA 4 mΩ 1 % 1 W ±150 ppm 2512 | C459681 RLP25FEGR004 4 mΩ 1 % **3 W ±50 ppm** 2512 *(ext, merged)* | Better power and TCR; same footprint; merged with R303 (LM5148 sense). |
| R243 (INA226 laptop VBUS shunt) | C844900 WSL25125L000FEA 5 mΩ 1 % 1 W ±110 ppm **2512** | C316225 RLM12FTCMR005 5 mΩ 1 % 1 W ±100 ppm **1206** *(ext, merged)* | Same R/power, slightly better TCR; 5 A → 0.125 W (12 % of rating). Merged with R415; footprint shrinks 2512→1206. |
| Q213, Q214 (laptop source LM74800 pair) | C534333 BSC040N08NS5 80 V 4 mΩ | C5955453 BSC026N08NS5ATMA1 80 V **2.6 mΩ** *(ext, merged)* | Same package family (TDSON-8 5×6), same pinout, lower R_DS(on) (0.26 W → 0.17 W at 5 A). Same FET as the power_input LM74800 pairs. Qg 74 vs 43 nC: turn-on set by the 22 nF dV/dt cap, DGATE 2.6 A pull-down still turns off in ~30 ns. |

Docs updated: design/power_input.md, power_laptop.md, power_rails.md, usbc_muxes.md, ethernet.md,
usb_hub.md, card_reader.md.

## Kept extended (reason)

**ICs (no basic equivalent, function-specific)** — RP2350B, USB7206C, RTL8156BG, GL3224, PMG1-S3, TPS26750,
LM51770, LM5148, LM74800 (×3), LM74700, LM74502, TPS259470, TPS62933F/P (different modes by design),
TPS62A02A, TPS2553, TPS22918, INA226, INA237, INA180A2, TLV6700, TLV3011, TMP1075, TCA9534, AT24C512C,
24AA025E48 (EUI-48), SST26VF016B, SN74LVC1G32/1G11/3G17, 74LVC1G17, TUSB1064, TUSB1046, TPD4S480,
TPD6S300, TPD4E02B04, USBLC6-2SC6.

**Connectors / mechanical** — USB-C ×2 (DX07S024), USB-A ×2, PJ-063BH barrel, 12401610E4#2A, RJ45 magjack,
SD-111, DM3AT µSD, FH34SRJ FPC, SM04B Qwiic, SKRTLAE010 buttons, LCD module.

**Power semis / magnetics** — BSC0805LS, BSZ070N08LS5, BSC0901NS, CSD18543Q3A, AO4842, XAL1010-103,
MWSA1206S-4R7, MWSA0503S-2R2/-1R5, SWPA4018S1R0 (no basic power inductors), AOTA-B201610 3.3 µH and
ABM8-272-T3 12 MHz (RPi-mandated for RP2350).

**Protection** — 5.0SMDJ51A, 5.0SMDJ48CA, SMCJ28A, SMAJ6.0A (no basic TVS with these standoff voltages;
the only basic SMB TVS are 6.5 V/6.8 V bidirectional), MF-NSMF050-2 PTC (no basic PTC).

**Small discretes** — BAT54WS (VBUS-sense clamp: basic 1N5819WS leaks 500 µA, would corrupt the 47k/68k
divider), BAT54A (common anode; basic BAV70 is common cathode), BAT46W (100 V; basic 1N4148W is only
75 V on a 48–50 V net with TVS overshoot), BZT52C5V1 (no basic zener), BSS138DW (I²C bridge; basic
AO3400A adds ~10× capacitance, 2N7002 V_GS(th) up to 2.5 V at 3.3 V drive), NCP18XH103 NTC (no basic NTC).

**Capacitors** — 1 µF/2.2 µF/4.7 µF/47 nF 100 V and 10 µF 50 V X7R (no basic 100 V caps except 100 nF
0805; basic 10 µF 50 V is X5R 0805/1206 — DC-bias loss at 28 V), 47 µF 10 V X7R 1210 (basic is X5R 1206),
1 nF 100 V C308 (DNP snubber — not placed, so no JLC fee in practice), 390 pF C0G and 82 pF C0G (no basic
value), POSCAP 150 µF, polymer 100 µF/35 V and 330 µF/6.3 V, alu 47 µF/100 V.

**Resistors** — precision 1 % E96 set-points with no basic value in any size (checked 0402, 0603 and 0805):
41.2 k (LM5148 CNFG strap), 73.2 k (RT), 64.9 k / 14.3 k (FB, UVLO), 31.6 k, 4.42 k (FB), 24.3 k / 8.66 k
/ 5.23 k (buck-boost VSEL FB), 6.49 k (CFG strap), 86.6 k (RT), 62 k (COMP), 43 k (EN), 1.1 M / 46.4 k (OVP
31.1 V), 255 k, 422 k / 121 k / 40.2 k (sink OV/UV), 2.49 k (PHY RSET), 59 k (PHY buck FB), 27 Ω (RP2350
USB termination, RPi value), 39 Ω 1206 (backlight), 150 Ω 2512 1 W (discharge), shunts 8 mΩ 2512, 30 mΩ 0805,
2/4/5 mΩ (merged above). Changing these to basic values would move thresholds/output voltages; not done.

## Further options (not applied)

- Several E96/E24 values exist as JLC **"preferred extended"** in 0603 (40.2 k C12447, 62 k C23221, 43 k
  C23172, 27 Ω C25190). If the order uses Economic PCBA and JLC still waives the fee for preferred
  extended parts, moving these to 0603 would save another ~$12/order. `bom_check.py` counts them as
  extended either way.
- Re-picking feedback dividers to basic-value pairs (e.g. +3V3 FB 47 k/15 k = 3.307 V instead of 31.6 k/10 k)
  would remove a few more, at the cost of re-verifying each rail/threshold; out of scope for a no-degradation pass.

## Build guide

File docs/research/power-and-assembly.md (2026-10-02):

# odeck-10 — power stage & JLC assembly research (2026-10-02)

Tags: **[V]** checked against a datasheet, vendor page or JLC page (URL given) · **[S]** JLC parts API stock on 2026-10-02
(`q.py`, LCSC numbers) · **[I]** inference or engineering estimate, verify before committing.
Stock moves fast. Re-check before ordering.

---

## 0. Key findings

1. **The LTC4417 cannot take the PD-in rail.** It is specified for 2.5–36 V, with ±42 V protection [V: Newark/ADI
   listing "PowerPath Prioritizer 2.5 to 36 V", https://www.newark.com/analog-devices/ltc4417iuf-pbf/powerpath-prioritizer-qfn-ep-24/dp/51AK7246].
   A 48 V EPR source (50.4 V max) is out of range. **Use discrete ideal-diode controllers (LM74720/LM74800/LM74700),
   with priority set by hardware enable logic.**
2. **The LM5176 has thin margin at 48 V.** It operates up to 55 V, 60 V abs max [V: https://www.ti.com/product/LM5176].
   **LM51770** runs 3.5–78 V (85 V abs) and is "bidirectional" [V: https://www.ti.com/product/LM51770]. It is in stock
   (JLC 1007, Mouser 2131) and is the preferred buck-boost.
3. **Do not put bus power onto VSYS. Feed it straight onto the 5 V rail.** A laptop sources 5 V (Macs ≈ 15 W), and a
   5 V input cannot go through a buck to make 5 V. Keeping VSYS as an "external power only" rail (9–48 V) also
   makes the source and sink paths simple to interlock.
4. **Thermals are the biggest risk.** At full load, the losses on a bare 100×60 mm board come to about 12–14 W, which
   means a rise of roughly 60–80 K. See §5.
5. **JLC will hand-solder the LCD.** The HS20HS072RX part page says "Assembly Type: Wave Soldering, Standard Only",
   which means operator-soldered. Applying foam tape is **not** a listed service. See §6.

---

## 1. Input OR-ing and the laptop-port direction problem

### Comparison

| Option | V range | Fits? | JLC stock [S] | Notes |
|---|---|---|---|---|
| LTC4417 (3-input priority, back-to-back PFETs) | 2.5–36 V, ±42 V | **No** (48 V EPR) | C688510 IUF#TR 3248, C688503 2602 | Would only work if PD-in were capped at 28 V. PFETs at 8 A are lossy and large |
| LTC4418 (dual) | 2.5–40 V [I] | No | C688513 48 | Same voltage problem |
| **LM74720-Q1** (ideal diode, back-to-back NFET, OVP, EN) | 3–65 V, −65 V reverse [V: https://www.ti.com/product/LM74720-Q1] | **Yes, barrel** | C5219205 776 | Adjustable OV cut-off, 0.5 µs reverse block, 29 mA boost (fast FET drive). LM74721 C5219199 only 5 in stock |
| **LM74800-Q1 / LM74800M** (back-to-back NFET, EN, OV/UV) | 3–65 V [I, same family] | **Yes** | C3215600 4040, C7216630 6031 | Good second source for the LM74720 role and for the sink switch |
| LM74700-Q1 (single NFET ideal diode, EN) | 3.2–65 V [I] | Yes (OR-ing only) | C2653623 5563, C2941042 1448 | No load disconnect in the forward direction. Use it as the PD-path diode |
| LM5050-1 (OR-ing controller) | 5–75 V [I] | Partial | C473393 18017 | No EN/OVP, no reverse polarity. OK as a plain OR diode |
| TPS2121 (integrated mux) | 2.7–22 V, 4.5 A | **No for VSYS** | C485916 32291 | Too little current and voltage for the main path |
| LM5060 / LM5069 (hot-swap) | 5.5–65 / 9–80 V | Optional | C74456 1460 / C111822 10364 | Use only if inrush/eFuse control is wanted on VSYS |
| TPS2663x (60 V eFuse, integrated) | 4.5–60 V, 6 A [I] | Marginal | C1850278 956 | Too low for 8 A barrel |

### Recommended topology

```
 PD-in USB-C (EPR sink, ≤48 V/5 A)
   TPD4S480 + SMCJ58A ── Q1a/Q1b (TPS26750 sink gate drive) ── Q2 (LM74700 ideal diode) ──┐
                                                                                           │
 Barrel 5.5×2.5 (9–24 V, ≤8 A)                                                             ├── VSYS 9–50 V (external only)
   SMCJ33CA ── Q3a/Q3b back-to-back 80 V (LM74720: reverse −65 V, OVP ≈ 26–27 V, EN) ───────┘    │
                         ▲ EN_BARREL = barrel_ok AND NOT pd_ok (2 small FETs, no MCU)                │
                                                                                                   ├─► LM51770 4-sw buck-boost ─► VOUT_SRC
                                                                                                   │        (5/9/15/20/28 V)         │
                                                                                                   │                       Q5a/Q5b back-to-back 40–60 V
                                                                                                   │                     (laptop PD ctrl source gate)
                                                                                                   │                                  │
                                                                                                   └─► LM5148 buck ─► V5 ◄──┐         ▼
                                                                                                                             │   LAPTOP VBUS
                                                                       Q4a/Q4b back-to-back 60 V (LM74800, EN) ◄────────────┼─────────┘
                                                                       EN_SNK = PDctl_sink_en AND NOT EXT_PRESENT            │
                                                                                     └──────── bus-power path ──────────────┘
                                                                         V5 ─► 3V3 (TPS62933/TPS563201) ─► 1V2 (TPS62A02/TLV62569)
```

- **Priority, enforced in hardware [I].** `pd_ok` comes from a divider and comparator (or the TPS26750 power-good) on
  the PD-in rail after contract. It pulls the LM74720 EN low through an NFET, so the barrel turns off whenever PD-in is
  live. Both paths are ideal diodes, so make-before-break overlap is safe: the higher rail conducts for a moment and
  nothing back-feeds. The logic is powered from each input itself, so no MCU and no always-on rail are needed.
- **`EXT_PRESENT` = VSYS > ~8 V** (comparator or the LM5148 PGOOD).
  - **Sink path (Q4) is allowed only when EXT_PRESENT is low AND the laptop-port PD controller requests sink.**
  - **Source path (Q5) is allowed only when EXT_PRESENT is high AND the PD controller enables source AND the
    buck-boost PGOOD is high.** The source/sink loop (VSYS→buck-boost→VBUS→sink→V5) can then never close.
  - Both are back-to-back pairs, so either one blocks in both directions when off.
- **The bus-power path goes to V5, not to VSYS.** Q4 driven by an LM74800 is both the on/off switch and the reverse
  blocker. While the LM5148 runs (5.1 V), Q4 is held off by EN_SNK. Request **5 V-only sink PDOs** from the laptop, so
  V5 stays within USB-A/LCD limits.
  - Bus-power budget ≈ 15 W in. The deck draws about 4–5 W itself, so the downstream budget is about 8–9 W
    (USB-A limited to 500–900 mA total, downstream C at 5 V/1.5 A or less).
- **Role sequencing on the laptop port.** This belongs to the PD-controller policy, and it needs a dual-role-power
  (DRP) controller with dead-battery support and PR_Swap/FRS (Fast Role Swap) [I].
  - **Attach with no external power:** the deck presents Rd (sink, UFP). Dead-battery mode closes Q4 autonomously.
  - **Attach with external power:** the deck presents Rp. The buck-boost starts at its 5 V default and Q5 closes.
    The deck negotiates SPR/EPR, then does a DR_Swap so it becomes the UFP.
  - **External power arrives while sinking:** V5 is handed to the LM5148 and EN_SNK drops. The PD controller sends
    a **PR_Swap**: the laptop goes to vSafe0V, then the deck sources 5 V, then the contract is raised. If the laptop
    rejects the swap, stay a sink.
  - **External power is lost while sourcing:** VSYS collapses. With FRS (PD 3.x), the laptop takes over 5 V within
    about 150 µs. Size the V5 hold-up caps (several hundred µF) to bridge the gap. Without FRS, the deck resets and
    the USB link drops, re-attaching as a sink. Confirm that the chosen laptop-port PD controller supports FRS and
    that Macs accept PR_Swap from a dock [I].
- **Barrel protection.**
  - LM74720 OV cut-off at about 26.5 V, protecting against a 28–48 V adapter plugged into the barrel.
  - **Bidirectional TVS** with standoff above the OV threshold, so it does not burn if someone plugs in 36–48 V:
    SMCJ33CA, or uni-directional SMCJ33A on the drain side [I].
  - 80 V FETs. Reverse polarity is blocked by the back-to-back pair (−65 V).
- **PD-in protection.** TPD4S480 (already chosen) plus a TVS rated for 48 V EPR: SMCJ58A, C151899 3584 / C409417 2717 [S].

### Path FETs (all [S])

| Use | Part | LCSC | Stock | Key spec |
|---|---|---|---|---|
| Barrel / PD-in / VSYS (80 V) | Infineon BSC026N08NS5 | C5955453 | 5786 | 80 V, 2.6 mΩ, TDSON-8 |
| " | Toshiba TPH2R608NH | C5379811 | 30654 | 75 V, 2.1 mΩ, SOP-Adv 5×6 |
| " | TI CSD19502Q5B | C2864118 | 7579 | 80 V, 3.4 mΩ |
| " | Infineon BSC040N08NS5 | C534333 | 6678 | 80 V, 4 mΩ |
| Bus sink Q4 (≤3 A) | TI CSD18543Q3A | C840100 | 12215 | 60 V, 8.1 mΩ, 3.3×3.3 |
| Source switch Q5 (≤28 V, 5 A) | BSC026N08NS5 / TPH2R608NH | — | — | Low Rds is cheap here. 60 V+ for margin on 28 V |

Conduction loss: barrel at 8.3 A through 2 × 2.6 mΩ ≈ 0.36 W. PD path at 3.6 A (175 W at 48 V) through 3 FETs ≈ 0.1 W [I].

---

## 2. Buck-boost VSYS (9–50 V) → laptop VBUS (5–28 V, 5 A, 140 W)

| Part | VIN | VOUT | V-set method | JLC [S] | Notes |
|---|---|---|---|---|---|
| **LM51770** (HTSSOP-38) | 3.5–78 V, 85 V abs | 3.3–78 V | FB divider + "dynamic output voltage tracking for PWM or analog input" | C43351171 **1007** (Mouser 2131) | Up to 1.8 MHz, average I-limit with IMON, PSM, bidirectional. Drop-in successor to LM5177 [V: https://www.ti.com/product/LM51770] |
| LM5177 (HTSSOP-38) | 3.5–60 V, 85 V abs | 3.3–60 V | Same, analog/PWM tracking | C7425536 151 | ≤600 kHz [V: https://www.ti.com/product/LM5177] |
| LM51772 (VQFN-40) | 0(3.5)–55 V | 1–55 V | **I2C**, 10/20 mV steps; I-limit 0.5–7 A over I2C; "USB C/PD compatible" | C41383743 **1** (Mouser 33) | Ideal feature set, but no stock and 55 V limit [V: https://www.ti.com/product/LM51772] |
| LM5176 (HTSSOP-28) | 4.2–55 V, 60 V abs | 0.8–55 V | FB injection | C442493 **12168** | Cheapest and best stocked. Only 5–10 V margin over a 48 V EPR source [V: https://www.ti.com/product/LM5176] |
| LM5175 | 3.5–42 V [I] | — | FB | C113356 6491 | **Not usable** at 48 V in |
| **BQ25756** (VQFN-36) | 4.2–70 V, 85 V abs | ≤70 V | **I2C**. Reverse (OTG) mode regulates VAC 3.3–65 V, I-limit 0.4–20 A; EPR named | C19272232 **9088** | Bidirectional charger controller, 200–600 kHz [V: https://www.ti.com/product/BQ25756] |
| LT8390 (ADI) | 4–60 V | — | FB | C673802 1766 | ~$12, no advantage |
| TPS55288 | ≤36 V | — | I2C | C2864583 5157 | Integrated, too low VIN/current |

**Can the BQ25756 also do the sink path? Technically yes, but not worth it [I].**
- Wire VAC = laptop VBUS and VBAT = VSYS. Reverse mode then gives an I2C-set PD source, and forward mode could pull
  power from the laptop.
- But the laptop only offers about 5 V/3 A. Boosting that into VSYS and bucking it back to 5 V is wasteful. Forward
  mode is also a battery charger: with no battery, VSYS needs a charge-termination/CV workaround.
- Reverse mode is off at power-up and needs I2C writes to enable (plus watchdog handling). Laptop charging would then
  depend on firmware. Safety would not, because the PD controller's OVP still opens Q5.
- Keep the BQ25756 as a **stocked Plan B to the LM51770** (9k in stock) if I2C control is acceptable.

### Recommended: LM51770, 5 V default, voltage selected by the PD controller in hardware [I]

**Setting the voltage**
- The resistor divider defaults to 5 V (vSafe5V at power-up, with no firmware involved).
- 9/15/20/28 V are selected by **2–3 PD-controller GPIOs** ("voltage select" GPIO events). Each one switches an
  extra FB resistor through a small NFET (2N7002-class). This is the usual TI PD-controller + external-regulator
  scheme. It is MCU-independent and satisfies "power safety must not depend on MCU firmware".
- AVS / fine trim (optional): an RP2350 PWM → RC → resistor injection into FB, with **limited authority** (e.g. ±1 V,
  set by the resistor ratio).
  - Laptops at 140 W use the 28 V fixed PDO, so AVS is not needed for odeck-10.
  - PD transition rules (slew ≤30 mV/µs, ±5%) are handled by soft-start/tracking caps.

**Safety layers [I]**
- The PD controller's VBUS OVP/UVP opens Q5.
- The LM51770 average current limit is set to about 5.5 A on output IMON.
- OVP comparator: a TL431-class part on VOUT_SRC pulls buck-boost EN low above roughly 30 V.

**Efficiency estimate at 140 W out, 250–400 kHz, 2 × 80 V FETs on the input side, 2 × 40–60 V on the output side,
4.7 µH [I]**

| Operating point | Mode | η | Loss |
|---|---|---|---|
| 48 V → 28 V × 5 A | Buck | ~97% | ~4.3 W |
| 20 V (PD) → 28 V | Boost | ~96% | ~5.8 W |
| 24 V barrel → 28 V | Buck-boost / boost | ~96% | ~5.8 W |
| 12 V barrel → 20 V × 2.25 A (45 W, PSU-limited) | Boost | ~95% | ~2.4 W |

Components:
- **Inductor:** Bourns SRP1265A-4R7M (C780205, 600 in stock; 13.5 A Irms / 28 A Isat / 8.4 mΩ) [S].
  Premium alternative: Coilcraft XAL1010-472 (C19271849, 157 in stock, 24 A, 5.2 mΩ, $13).
  Peak input current in boost from 20 V at 140 W is about 8 A.
- **Input-side FETs:** BSC070N10NS5 (C534364, 14639 in stock, 100 V / 7 mΩ, low Qg) or BSC040N08NS5.
- **Output-side FETs:** CSD18543Q3A or BSC040N08NS5.
- **Sense resistors:** 2–3 mΩ, 2512.
- **Caps:** 100 V X7R 1210 plus a 63 V polymer/electrolytic on the input; 50 V X7R plus polymer on the output.

---

## 3. Housekeeping rails

Load estimate:
- USB-A 3 × 0.9 A (1.5 A BC1.2 CDP on one port) ≈ 3.2 A
- Downstream C 5 V/3 A
- LCD backlight + RP2350 + 3V3/1V2 loads ≈ 1.5 A (at 5 V)
- **Total V5 ≈ 7–8 A (≈ 40 W) worst case.**

| Rail | Recommended | LCSC / stock [S] | Notes |
|---|---|---|---|
| **V5, 8 A from VSYS 9–50 V** | **TI LM5148** 80 V sync buck controller, VQFN-24, 2.2 MHz capable | C7470701 **57474**, $1.16 | 400 kHz, MWSA1004S-3R3 (C408483 501; 11 A / 16 A) + 2 × BSC070N10NS5. η ≈ 93% from 48 V → ≈ 3 W loss [I]. Alternatives: LM5146 (100 V, C3188679 3908), LM5145 (75 V, C485912 2210), dual LM5143-Q1 (65 V, C1849541 452) if V5 is split into ports and system |
| Always-on / aux (optional) | LMR38020 80 V 2 A | C5149193 11594 | Only if a standby rail independent of V5 is wanted |
| USB-A port switches | TPS2553 (adjustable I-limit) | C55266 58742 | Or SY6280AAC C55136 121k (cheap). Per-port FAULT → RP2350 |
| Downstream C 5 V/3 A switch | TPS25946 eFuse or TPS2557 (5 A adj.) | C3662780 1753 / C130056 1942 | Or the downstream PD controller's integrated 5 V switch, if it has one |
| 3V3, ~2–3 A, from V5 | TPS62933 (30 V, 3 A) or TPS563201 (17 V, 3 A) | C3200405 34272 / C116592 114631 | Feeds hub, RTL8156 (internal regulator), GL3224, RP2350, LCD |
| 1V2 / 1V1 (hub core, etc.) | TPS62A02 (2 A) or TLV62569 (2 A) | C5350187 31993 / C141836 242955 | Check per chip: USB72xx core rail, GL3224/RTL8156 internal regulators |
| RP2350 core | Internal SMPS | — | Per RP2350 datasheet |

In bus-powered mode V5 comes straight from Q4, so every rail derived from V5 works unchanged.

---

## 4. Barrel jack (5.5 × 2.5 mm, ≥8 A)

| Part | LCSC | Stock [S] | Rating (JLC/LCSC listing) | Notes |
|---|---|---|---|---|
| **Same Sky (CUI) PJ-063BH** | C3095900 | 240 | 2.5 mm pin, **8 A, 24 V**, THT | Recommended. Mouser 1580, TME 300, Arrow 1246 [findchips] |
| Same Sky PJ-063AH | C22434582 | 491 | 2.0 mm pin, 8 A | 2.0 mm pin, so the wrong size |
| XKB DC-042C-W-2.5 | C480371 | 1340 | 2.5 mm, 8 A, 24 V, right angle | Cheap stocked alternative. Check the datasheet for the pin current rating |
| XKB DC-005R-8A-2.5 | C7433305 | 322 | 8 A, 30 V, right angle | "8A" variant of DC-005 |
| HCTL HC-DC-007B-2.5-G1 | C19270564 | 305 | 2.5 mm, 8 A, 24 V | — |
| Switchcraft RAPC722X | C3095256 | 2 | 5 A | Not enough current |

Notes:
- **2.1 mm compatibility:** a 2.1 mm plug **cannot** go onto a 2.5 mm pin (its bore is too small). A 2.5 mm plug on a
  2.1 mm jack fits loosely and makes poor contact. So one jack cannot serve both; stay with 2.5 mm, which is common on
  high-power laptop bricks, and say so on the silkscreen [I].
- 8 A × 24 V = 192 W. At the 200 W target the jack runs at its limit, so derate the barrel to about 7.5 A in the MCU
  budget policy [I].
- A 24 V contact voltage rating is typical for these jacks. The LM74720 OVP keeps anything above about 27 V off the
  board.

---

## 5. Thermal budget (bare PCB) [I]

| Source | Worst-case loss |
|---|---|
| Buck-boost at 140 W | 4.5–6 W |
| Input path + source switch + sense resistors | 0.5–1 W |
| V5 buck at 40 W | ~3 W |
| 3V3/1V2 bucks | ~0.5 W |
| Hub + TUSB1046 + RTL8156 + GL3224 + RP2350/LCD | ~3.5–4 W |
| **Total** | **~12–14 W** |

**What this means for a 100 × 60 mm board**
- The board has about 120 cm² of surface across both faces. Natural convection plus radiation gives
  h ≈ 12–15 W/m²K, so θ ≈ 6 K/W for the board as a whole.
- **14 W → about 80 K rise; 10 W → about 60 K.** That is too hot for a desk object, with hot spots higher still.

**Mitigations**
- Spread the power stage over a large inner-plane copper area (2 oz outer layers if JLC offers it on 6/8 layers).
- A bottom aluminium plate on standoffs with a gap pad would roughly double the effective area.
- Grow the board: 120 × 80 mm gives θ ≈ 4 K/W.
- **Thermal derating policy:** an NTC near the buck-boost read by the RP2350, with the laptop contract renegotiated
  from 140 W down to 100/60 W when hot. As a hardware backstop, an NTC on the LM51770 EN/ILIM or a PD-controller
  thermal input.
- Sustained 140 W plus all ports at full load is rare. Design for about 8 W continuous with derating above that.

---

## 6. JLC assembly questions

**Prices** [V: https://jlcpcb.com/help/article/pcb-assembly-price, https://jlcpcb.com/help/article/pcb-assembly-faqs]

| Item | Price |
|---|---|
| Standard PCBA setup | $25.56 single-sided / $51.12 double-sided |
| Stencil | $8.21 / $16.42 |
| SMT | $0.0016/joint |
| **THT ("wave soldering" parts, actually soldered by hand)** | **$3.58 hand-soldering labour per order + $0.0164/joint**, +1 day |

- Estimate for barrel (3) + RJ45 (~14) + 3 × USB-A Gen2 (~13 each) + LCD tail (~12) + a hybrid USB-C ≈ 80–90 joints,
  which is **about $1.4/board plus $3.58/order [I]**.
- Ask for leads to be trimmed flush, to meet the "no sharp parts on the bottom" goal [I].

**LCD panel**
- The JLC part page for **HS20HS072RX (C5329582, 2208 in stock)** lists "**Assembly Type: Wave Soldering**" and
  "**PCBA Type: Standard Only**" [V: https://jlcpcb.com/partdetail/HS-HS20HS072RX/C5329582]. JLC therefore treats it
  as an operator-soldered part and will solder the FPC tail.
- **Double-sided foam tape:**
  - Not a listed service. The JLC parts category "Double-sided tape" is empty
    [V: https://jlcpcb.com/parts/2nd/Office_Supplies/Double-sided_tape_3230], and "foam tape" returns no stocked part [S].
  - The FAQ and capabilities pages list wire soldering, programming, stacked parts and flex fixtures, but no adhesive
    or mechanical assembly [V: https://jlcpcb.com/capabilities/pcb-assembly-capabilities].
  - → **Ask JLC support** whether they will apply customer-consigned die-cut foam tape (3M 4914-class, 1.1 mm) as a
    special request [I].
  - Plan B: the panel is soldered and the user applies the tape (ship a die-cut pad).
  - Plan C: a locating feature, such as two printed/PCB standoffs or a solder-tab bracket, so the hand-soldered panel
    is positioned without tape.
  - Give JLC an assembly drawing showing the FPC bend direction and the panel outline on silk.

---

## 7. Connectors in JLC stock

**2.5G RJ45 magjack with LEDs (THT)**

| Part | LCSC | Stock [S] | Notes |
|---|---|---|---|
| **USAKRO DGUK211Q340CD2A4D2 (2.5G)** | C19725134 | 111 | Datasheet: "TAB-UP 1X1 2.5G", LEDs, IL −1.0 dB max 1–125 MHz [V: LCSC datasheet] |
| USAKRO DGUK511Q340AB2A8D2 (2.5G) | C19725141 | 47 | 2.5G, LEDs, shielded |
| USAKRO DGUK111Q340AB2A1D2 (2.5G) | C19725125 | 8 | — |
| YDS 51F-1210GY2D2NL | C179768 | 745 | Name suggests 10G, unverified (datasheet fetch blocked) |
| HanRun HR911130A/C | C54408 10841 / C50933 3751 | — | **1G-rated only.** Avoid for 2.5GBASE-T |

The stock is thin, so pre-buy the 2.5G parts into the JLC parts library, or consign a Pulse/Bel 2.5G magjack from
Mouser.

**USB-A 10G (USB 3.1/3.2 Gen2) receptacles**

| Part | LCSC | Stock [S] | Notes |
|---|---|---|---|
| **Amphenol GSB4111312HR** | C5429382 | 3846 | GSB4 = Amphenol's "USB 3.1 Gen 2" Type-A family. GSB41113xxHR is right angle, 10 Gb/s [V: search of Amphenol GSB4X datasheet io_usb_3_1_gen2_gsb4x.pdf; PDF itself 403]. Pin current 1.8 A class [I] |
| Amphenol GSB412137CHR | C464567 | 4222 | GSB4 family, listed "USB 3.1" (orientation to check) |
| Amphenol GSB311131HR | C473057 | 15198 | **5 Gbps only** [V: LCSC datasheet "up to 5 Gbps"]. Avoid |
| Molex 48406-0003 | C565298 | 1162 | USB 3.0 (5G) |

**USB-C receptacles, 5 A / 48 V (EPR) + 10G**

| Part | LCSC | Stock [S] | Notes |
|---|---|---|---|
| **JAE DX07S024XJ1R1100** | C134113 | 1626 | 24P, **5 A, 48 V**, USB 3.x 10G, USB-IF certified, hybrid THT legs [V: https://www.heilind.com/jaedx07s024xj1r1100.html; JAE DX07 PIM https://www.tti.com/content/dam/ttiinc/manufacturers/jae/doc/jae-dx07-series-usb-type-c-connectors-datasheet-specifications.pdf]. **Laptop port + PD-in** |
| JAE DX07S024JA1R1300 | C2840478 | 5266 | 24P, 5 A, 48 V, mid-mount ("laminated board") per listing. Confirm 10G in the JAE PIM |
| JAE DX07S024WJ1R350 / WJ3R400 | C5246837 167 / C5159529 2235 | — | 24P, 5 A, 48 V (WJ3R400 is vertical) |
| **Amphenol 12401610E4#2A** | C5119948 | 7161 | 24P, **USB 3.2 Gen2 10G, 5 A, but 20 V** [V: https://www.newark.com/amphenol-icc-commercial-products/12401610e4-2a/usb-conn-3-1-type-c-rcpt-r-a-smt/dp/59AC8815]. Fine for the downstream C (5 V), **not** for 28/48 V ports |
| GCT USB4085/USB4105/USB4110/USB4135, Molex 2171750001 | — | — | USB 2.0 / 6-pin only. Not suitable |

**SD (full-size) and microSD, push-push**

| Part | LCSC | Stock [S] | Height | Notes |
|---|---|---|---|---|
| **Hanbo SD-111** | C410353 | 5209 | 2.9 mm | Full-size, push-push |
| Hirose DM1AA-SF-PEJ(82) | C506790 | 585 | 2.9 mm | Full-size, push-push, locating pins (premium) |
| SHOU HAN SD-CZ 11P H2.8 PUSH | C53223914 | 170 | 2.8 mm | Full-size, push-push |
| **Hirose DM3AT-SF-PEJM5** | C114218 | 18849 | 1.68 mm | microSD, push-push (listing field "No" seems wrong; DM3AT is push-push) [I] |
| SHOU HAN MICRO SD4.0 9P H1.4 PUSH | C53223918 | 993 | 1.4 mm | Lowest profile, push-push |
| Minlenda MLD-TF PUSH-H18 | C52750848 | 21276 | 1.8 mm | Cheap push-push |
| Amphenol 114-00841-68 | C3195424 | 2731 | 1.55 mm | microSD, listed push-pull |

No UHS-II full-size socket in JLC stock. That matches the "UHS-I minimum" goal.

---

## 8. Risks and open items

1. **Thermal** (§5). This is the biggest risk for "bare-PCB, 140 W" at 100 × 60 mm.
2. **Laptop-port PD controller features.** It must support DRP, dead-battery sink, PR_Swap and ideally FRS, and drive
   two back-to-back gate pairs (Q4/Q5) or accept external gate drivers. This depends on open question 1 in
   odeck-10.md.
3. **Stock depth.** LM51770 (1007), LM74720 (776), 2.5G magjack (111), PJ-063BH (240). Pre-order into the JLC library.
   Fallbacks: BQ25756 (9088), LM74800 (10k), DC-042C-W-2.5 (1340).
4. **LM51770 DTRK/tracking pin details, and GPIO-switched FB transient behaviour (overshoot when stepping
   28 V → 5 V)** need datasheet review and simulation. Add an active VBUS discharge (bleeder FET) on VOUT_SRC for
   fast down-transitions [I].
5. **48 V creepage/rating everywhere on VSYS.** Use ≥100 V caps, or 80 V with derating, and 80 V FETs. The TVS
   clamp must stay below the FET V(BR).
6. **Foam tape** not confirmed (§6). Ask JLC support before layout freezes the area under the panel.

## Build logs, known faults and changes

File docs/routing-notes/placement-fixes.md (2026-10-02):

# Placement fixes for routing (2026-10-03)

These changes answer the placement requests in `hs_usbc.md`, `hs_hub.md` and `power.md`. They live in the layout
scripts (`hardware/odeck-10/layout/*.py`) and have been applied to `odeck-10.kicad_pcb`.

**Board check after `tools/apply_layout.py`:**
- 0 courtyard overlaps.
- No OUTSIDE REGION or MOVED NON-OWNED warnings.

**DRC (`--severity-error`):** apart from unconnected items, there are 163 `[clearance]` errors.
- All 163 are pad-to-pad pairs inside a single IC footprint (U304, U303, U206, U109, ...).
- They come from the HV/PWR_HC netclass rules in the uncommitted `.kicad_pro`. The board as it was before these
  moves shows the same errors.
- No new violations.

Coordinates are footprint origins in mm. "rot" is the KiCad orientation. T = top, B = bottom.

## Changes your scripts must follow

| Script | What changed |
|---|---|
| `c_hs_usbc` | U501 and U504 moved; C611/C612 swapped (the P5 TX polarity detour can go, use `pleft=True`); TP1206 moved out of the lanes |
| `d_hs_hub` | C603–C608 rotated; C609/C610 moved 2 mm east; C835/C836 rotated; R908 moved; L1001 group nudged |
| `e_hs_eth_sd` | R908 moved, so the CLK detour must be shortened |
| `b_power` | C220 now on the bottom; C114/R122 moved off R137.2; R312.2 top side cleared; TP1202 moved; U206 unchanged |

The routers check pad nets, so the stubs they stopped short should now connect once they re-run.

## hubrails (`hubrails.py`)

| Ref | Old | New | Why |
|---|---|---|---|
| C611 (P5 TXP) | 172.35, 88.2 r90 T | **173.6, 88.2** r90 T | P/N order now matches hub pins 83 (P, x 173.0) and 84 (N, x 172.6). Pad 1 is still south (y 88.68) |
| C612 (P5 TXN) | 173.6, 88.2 r90 T | **172.35, 88.2** r90 T | swapped with C611 |
| C603 / C604 (P1 TX) | 160.55 / 161.8, 101.0 r90 | same xy, **r270** | pad 1 (HUB_P1_TX*_IC) now faces north, at y 100.52 |
| C605 / C606 (P2 TX) | 162.3 / 163.55, 105.4 r90 | same xy, **r270** | pad 1 now north, at y 104.92 |
| C607 / C608 (P3 TX) | 166.8 / 168.05, 106.55 r90 | same xy, **r270** | pad 1 now north, at y 106.07 |
| C609 (P4 TXP) | 175.4, 105.5 r0 T | **177.4, 105.5** r0 T | pad 1 (HUB_P4_TXP_IC) at 176.92, 105.5 |
| C610 (P4 TXN) | 175.4, 106.75 r0 T | **177.4, 106.75** r0 T | pad 1 at 176.92, 106.75. This frees the pocket under pins 43–48 (+3V3 / PF3–PF7) for escape vias |
| C613 (+3V3, B) | 169.0, 90.6 | **166.8, 90.6** | swapped with C626 |
| C626 (+1V15, B) | 166.8, 90.6 | **169.0, 90.6** | swapped with C613 |
| D602 | 158.15, 81.5 r0 T | **158.9, 81.4** r0 T | pads: +3V3 at 157.85, HUB_VBUS_SNS at 159.95 |
| C641 | 157.3, 83.25 r0 T | **156.6, 81.4 r90** T | pad 1 (+3V3) at 156.6, 81.88 |
| U603 | 158.15, 86.1 r90 T | **158.15, 84.55** r90 T | pins 1–3 at y 85.69; pins 4/5 at y 83.41 |
| R626 | 158.75, 89.3 r0 T | **159.75, 88.6 r270** T | pad 1 (VBUS_SNS) at 159.75, 87.78; pad 2 (GND) at 159.75, 89.42 |

**Hub pin 99 (+3V3, 166.6, 92.16).** The pad behind its toe is now C613 pad 1 (+3V3, 166.32, 90.60). The pin 99
via can land on or next to that cap pad. Pin 93 (+1V15) now has C626 pad 1 (+1V15, 168.52, 90.60) behind it,
not a +3V3 pad.

**R312.2 (+5V, B, 157.2, 87.36).** The VBUS-detect group has moved toward y 80–86.6 and x ≥ 159. The top side
over x 155.3–158.9, y 86.7–88.4 now has no pads, so the whole R312 pad 2 is free for L4 vias. The U301 pads and the
U303 pads (bottom, y 89.64) still bound the area.

## right (`right.py`)

| Ref | Old | New | Why |
|---|---|---|---|
| C835 (ETH TXP) | 191.4, 61.15 r0 | same xy, **r180** | pad 1 (ETH_TXP_IC) now east, at 191.88, 61.15, toward U801 pin 43 |
| C836 (ETH TXN) | 191.4, 62.4 r0 | same xy, **r180** | pad 1 (ETH_TXN_IC) at 191.88, 62.40, toward pin 44 |
| L1001 | 226.4, 71.35 | **226.4, 71.2** | the whole Pico 2 regulator group moved 0.15 mm north, with its geometry unchanged |
| C1002 | 223.9, 71.4 | **223.9, 71.25** | same group |
| C1001 | 226.4, 69.4 | **226.4, 69.25** | same group |
| C1003 | 228.95, 71.45 | **228.95, 71.3** | same group |

**RP2350 USB pins 66/67 (toes at y 73.01).** A 0.45/0.2 via with 0.15 clearance now fits anywhere in the band
**y 72.40–72.60** between the L1001 / C1002 pads and the pin toes. The band was 0.05 mm wide before.
- Suggested vias: USB_DP_IC at **(224.85, 72.55)** and USB_DM_IC at **(226.10, 72.55)**.
- Each via lands on the IC-side pad 1 of R1007 / R1008 (bottom, y 72.76). On the bottom the stub is then just the
  via-in-pad.

## usbc (`usbc.py`)

| Ref | Old | New | Notes |
|---|---|---|---|
| U501 (TPD4S480, B) | 150.7, 63.05 | **150.7, 65.05** | Pins 1–5 (SBU1, SBU2, VBIAS, CC1, CC2) at y 63.65, x 149.9–151.5. Pins 11/12 (LAPTOP_CC2/CC1) at 151.5 / 151.1, y 66.45. Pins 14/15 (UP_SBU2/1) at 150.3 / 149.9, y 66.45. Pin 20 (VBUS_LAPTOP) at 149.3, 64.25 |
| R512 R513 R510 R511 R508 R509 | grid y 66.85 / 68.1 / 69.35 | grid **y 67.65 / 68.9 / 70.15** | x unchanged (151.75 / 153.9) |
| U504 (TPD6S300, B) | 171.0, 63.4 | **174.2, 63.4** | Pins 1–5 (DS_C_SBU1 … DS_C_CC2) at y 62.0, x 173.4–175.0. Pins 19/20 (HUB_DSC_DN/DP) at 172.8, y 63.0 / 62.6. Pins 11/12 (DS_CC2/CC1) at 175.0 / 174.6, y 64.8. Pins 14/15 (DS_SBU2/1) at 173.8 / 173.4, y 64.8. Pin 9 (FLT) at 175.6, 63.8. Pin 10 (+3V3) at 175.6, 64.2 |
| C537 (VBIAS, B) | 174.0, 63.4 r90 | **177.08, 62.72 r270** | pad 1 (DS_TPD_VBIAS) at 177.08, 61.95 |
| C538 (+3V3, B) | 175.55, 63.0 | **176.85, 65.3** r90 | pad 1 (+3V3) at 176.85, 65.78 |
| R541 (FLT pull-up, B) | 176.8, 63.0 | **177.95, 65.3** r90 | pad 1 (FLT) at 177.95, 65.81 |
| R531 / R532 (DS_EQ0) | 169.95 / 172.1, 66.15 r0 | **169.5 / 170.6, 66.55 r90** | the right-edge straps are now two vertical columns, all west of x 171.11 |
| R529 / R530 (DS_EQ1) | 169.95 / 172.1, 67.4 r0 | **169.5 / 170.6, 68.6 r90** | |
| R523 / R524 (DS_CAD_SNK) | 169.95 / 172.1, 68.65 r0 | **169.5 / 170.6, 70.65 r90** | |
| R410 / R411 / R412 (MUX_DS CTL0 / CTL1 / FLIP) | row at y 71.2 | **173.7, 66.6 / 67.85 / 69.1** r0 | moved under the TX1/RX1 lane copper, where no through via fits anyway |
| R522 (DS_HPD) | 169.95, 69.9 | **173.7, 70.35** r0 | same place as R410–R412 |

**New through-via room** (checked against the current `c_hs_usbc` copper):
- **Laptop side.** The D502/D503 gap above U501 is now free on every layer at **x 149.6–150.8, y 60.6–62.8**. That is
  room for 4–6 staggered 0.45 mm vias for A8 SBU1, A7/A6 D−/D+ and A5 CC1. The B row is THT, so CC2/SBU2/D± can go
  straight down on L6.
  - LAPTOP_CC1/2 now leave U501 at y 66.45, 2 mm lower than before.
- **Downstream side.** The column under the D507/D506 gap, **x 171.3–172.2, y 61.2–69.2**, is now free on every
  layer (it was blocked only by U504 and the strap grid). That is about 12 via positions at 0.6 mm pitch.
  - Suggested use: J502 CC1/CC2/SBU1/SBU2/D+/D− vias at the top (y 61.7–65.0). U504's DP/DN pins (172.8) face the
    column. CC/SBU reach pins 1–5 along y ≈ 61.4 on the bottom.
  - The lower part (y 66–69) is for DS_SBU1/2 (U504 pins 14/15 → R542/R543 → U503 pins 26/27) and for
    HUB_DSC_DP/DN.
- **Bottom corridor.** The bottom strip **x 168.1–168.9** (west of the vertical straps, east of C525) runs from
  y 61.2 down to y 72. It also reaches the free via area **x 168.8–171, y 72–74.4**.
- **DS_CC vias.** For DS_CC1/2 → PMG1, the area **x 164.4–167.8, y 59.8–61.2** (west of J502, above R533/R534) was
  already free.
- U503 decaps C525–C529 are unchanged. C537/C538/R541 are within about 1.5–3 mm of their U504 pins; VBIAS takes the
  longest path.

**TP1206** (`zz_integration.py`): 150.7, 67.55 → **143.7, 64.84** T. It now sits between C501 and TP403, left of D503
and next to the J501 VBUS / D501 side. It is out of the lane fan-in and blocks nothing the lanes use.

## power (`power.py`)

| Ref | Old | New | Notes |
|---|---|---|---|
| C220 (HB2 bootstrap) | 113.9, 80.45 r90 **T** | **115.5, 85.45 r90 B** | pad 1 (BB_HB2) at 115.50, 86.22, under pin 26; pad 2 (BB_SW2) at 115.50, 84.67 |
| C224 (BB_COMP) | 115.45, 85.2 r90 B | **118.6, 84.6 r0** B | under the package above the EP, toward pin 18; pad 1 at 118.12, 84.60 |
| C213 | 115.15, 83.2 B | **115.15, 83.1** B | 0.1 mm nudge for C220 |
| C217 | 114.9, 88.7 B | **114.9, 88.8** B | 0.1 mm nudge for C220 |
| C114 (PD_DVDT) | 113.95, 77.05 r90 **T** | **110.0, 81.5 r0 B** | pad 1 (PD_DVDT) at 109.22, 81.5; pad 2 (GND) at 110.78, 81.5 |
| R122 (PD_OV) | 112.45, 76.45 r90 **T** | **110.3, 80.0 r180 B** | pad 1 (PD_OV) at 110.81, 80.0, toward R121.2; pad 2 (GND) at 109.79, 80.0 |
| TP1202 (`zz_integration.py`) | 106.3, 80.6 B (under Q204) | **108.1, 84.45 B** | still under L201, but clear of Q204's courtyard (y ≤ 82.39), so the Q204 EP can take thermal vias |

**U201.** C220 no longer sits above pins 20–23, and the whole toe column north of the pins (x 113.1–115.1, y 78–82)
is free on top. The R202 Kelvin pair can leave pins 22/23 northward in the normal way, and the vias under the
package are no longer needed.
- HB2/SW2 can drop through 0.4 mm vias at the inner ends of pins 26 and 25, at about (116.05, 86.25) and
  (116.05, 85.6). These lie between the pin ends (x 115.9) and the EP (x ≥ 116.6). The HB2 via overlaps C220 pad 1.
- C121 (+3V3, at the toes of pins 23–26) is unchanged.

**R137.2 (VIN).** The R122/C114 pads no longer sit over R137 pad 2 (x 112.0–115.5, y 75.7–77.2). The whole pad, plus
the strip down to y 77.6, is now free on top for VIN vias. Before, only a single column at x 115.0 was free.

C114, R122 and TP1202 now sit on the bottom inside the `P_BB_SW2` area, where KO_BB_SW2 forbids vias on L3/L4.
- Take their GND pads out on L6 to a via outside that area. For C114/R122, go north into the GND via box at
  y < 79.3. For TP1202, go south of y 85.7.
- The PD_DVDT and PD_OV traces also leave on L6.

**Not changed (small nudges did not help):**
- **U206 +5V sink vias.** The spot is boxed in by C211's GND pad (top, to x 131.4), R246 (top) and C239 (bottom,
  SNK_DVDT at pin 7). There is no free spot nearby for R246 or C239 without crowding U206's other pins. This needs a
  real rework of the sink cluster.
- **J502 A9 VBUS_DS and R415.1 +5V vias.** These are routing-level fixes, as already suggested in `hs_usbc.md`. Tie
  A9–B4 / A4–B9 between the J502 rows, and put the +5V vias inside or north of R415 pad 1 (y 78.3–79.4).

## zz_integration (`zz_integration.py`)

A target can now be an absolute point as well as a footprint:
- `("@", (x, y), side)` searches for the nearest free spot around (x, y).
- `("=", (x, y), side)` places the part exactly at (x, y).

**R908** (µSD CLK series R): 129.1, 107.25 B → **119.4, 114.9 B (r0)**.
- Pad 1 (CR_USD_CLK) is at 118.89, 114.90 and pad 2 (CR_USD_CLK_S) at 119.91, 114.90.
- It sits just west of the U901 escape via row (y 114.3, CLK via at x 123.2), so the 11 mm CLK detour goes away.
- It is placed with `=` because the free-spot search treats the J901 socket outline as blocking the whole area.

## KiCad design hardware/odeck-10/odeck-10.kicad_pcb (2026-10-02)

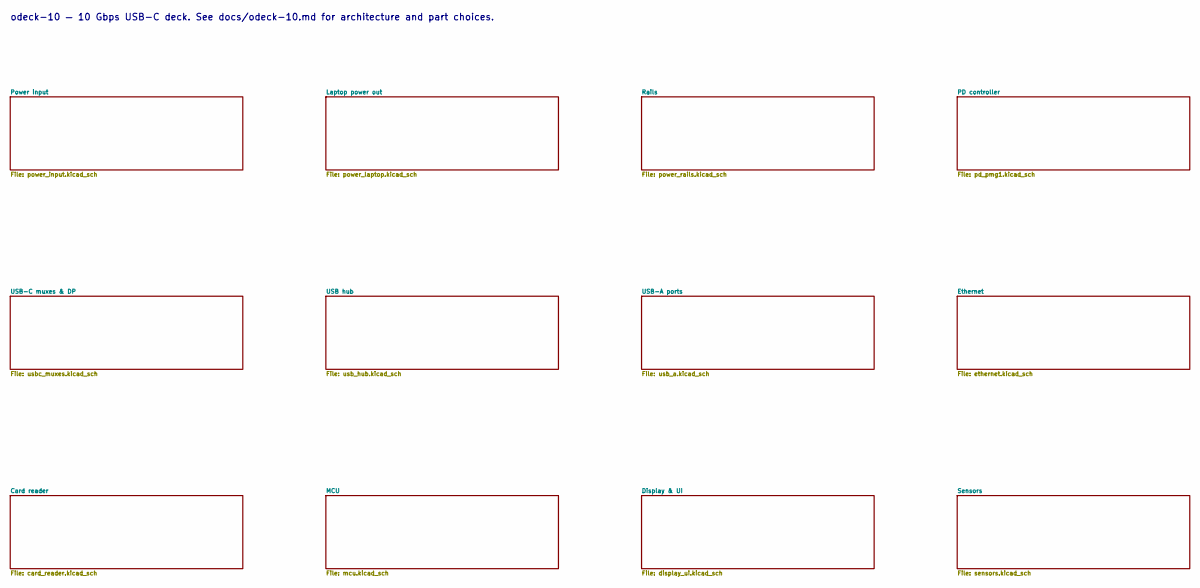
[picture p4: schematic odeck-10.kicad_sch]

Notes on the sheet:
odeck-10 — 10 Gbps USB-C deck. See docs/odeck-10.md for architecture and part choices.

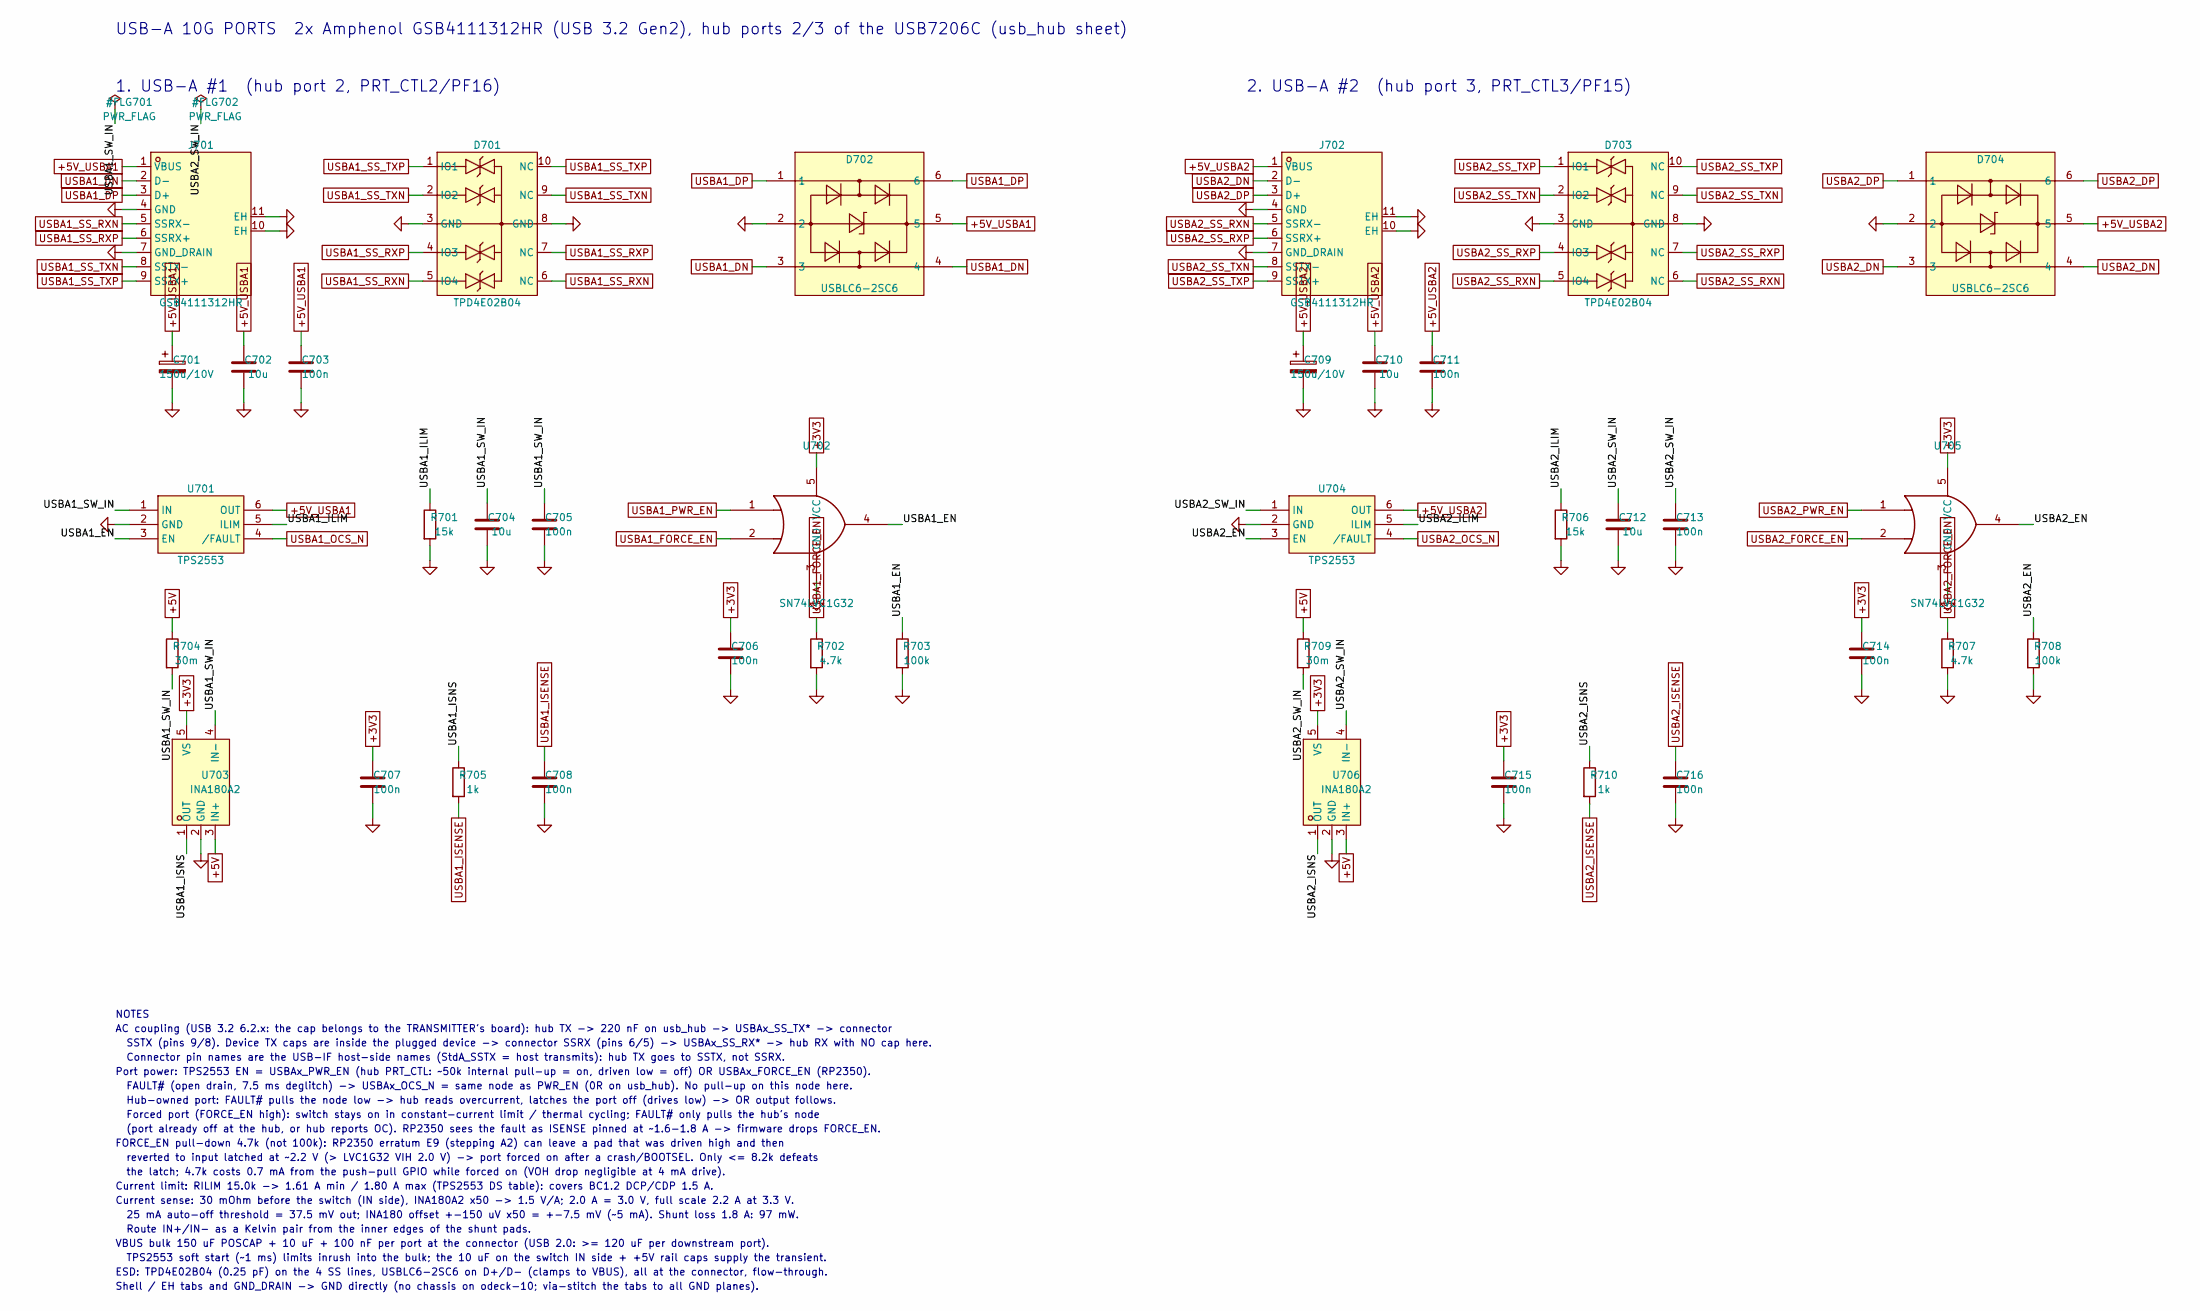
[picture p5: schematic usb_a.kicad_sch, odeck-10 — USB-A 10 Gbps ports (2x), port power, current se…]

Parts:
C701, C709: 150u/10V; CP_EIA-7343-31_Kemet-D; LCSC C347559
C702, C704, C710, C712: 10u; C_0805_2012Metric; LCSC C15850
C703, C705, C706, C707, C708, C711, C713, C714, C715, C716: 100n; C_0402_1005Metric; LCSC C1525
D701, D703: TPD4E02B04; USON-10_L2.5-W1.0-P0.50-BL; MPN TPD4E02B04DQAR; LCSC C106794
D702, D704: USBLC6-2SC6; SOT-23-6_L2.9-W1.6-P0.95-LS2.8-BL; MPN USBLC6-2SC6; LCSC C7519
J701, J702: GSB4111312HR; USB-A_Amphenol_GSB4111312HR; MPN GSB4111312HR; LCSC C5429382
R701, R706: 15k; R_0402_1005Metric; LCSC C25756
R702, R707: 4.7k; R_0402_1005Metric; LCSC C25900
R703, R708: 100k; R_0402_1005Metric; LCSC C25741
R704, R709: 30m; R_0805_2012Metric; LCSC C858599
R705, R710: 1k; R_0402_1005Metric; LCSC C11702
U701, U704: TPS2553; SOT-23-6_L2.9-W1.6-P0.95-LS2.8-BR; MPN TPS2553DBVR; LCSC C55266
U702, U705: SN74LVC1G32; SOT-23-5; LCSC C10096
U703, U706: INA180A2; SOT-23-5_L3.0-W1.7-P0.95-LS2.8-BL; MPN INA180A2IDBVR; LCSC C192764

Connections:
+3V3: C706.1, C707.1, C714.1, C715.1, U702.5 (VCC), U703.5 (VS), U705.5 (VCC), U706.5 (VS); also elsewhere on the board
+5V: R704.1, R709.1, U703.3 (IN+), U706.3 (IN+); also elsewhere on the board
+5V_USBA1: C701.1, C702.1, C703.1, D702.5, J701.1 (VBUS), U701.6 (OUT)
+5V_USBA2: C709.1, C710.1, C711.1, D704.5, J702.1 (VBUS), U704.6 (OUT)
/USB-A ports/USBA1_EN: R703.1, U701.3 (EN), U702.4
/USB-A ports/USBA1_ILIM: R701.1, U701.5 (ILIM)
/USB-A ports/USBA1_ISNS: R705.1, U703.1 (OUT)
/USB-A ports/USBA1_SW_IN: C704.1, C705.1, R704.2, U701.1 (IN), U703.4 (IN-)
/USB-A ports/USBA2_EN: R708.1, U704.3 (EN), U705.4
/USB-A ports/USBA2_ILIM: R706.1, U704.5 (ILIM)
/USB-A ports/USBA2_ISNS: R710.1, U706.1 (OUT)
/USB-A ports/USBA2_SW_IN: C712.1, C713.1, R709.2, U704.1 (IN), U706.4 (IN-)
GND: C701.2, C702.2, C703.2, C704.2, C705.2, C706.2, C707.2, C708.2, C709.2, C710.2, C711.2, C712.2, C713.2, C714.2, C715.2, C716.2, D701.3 (GND), D701.8 (GND), D702.2, D703.3 (GND), D703.8 (GND), D704.2, J701.4 (GND), J701.7 (GND_DRAIN), J701.10 (EH), J701.11 (EH), J702.4 (GND), J702.7 (GND_DRAIN), J702.10 (EH), J702.11 (EH), R701.2, R702.2, R703.2, R706.2, R707.2, R708.2, U701.2 (GND), U702.3 (GND), U703.2 (GND), U704.2 (GND), U705.3 (GND), U706.2 (GND); also elsewhere on the board
USBA1_DN: D702.3, D702.4, J701.2 (D-); also elsewhere on the board
USBA1_DP: D702.1, D702.6, J701.3 (D+); also elsewhere on the board
USBA1_FORCE_EN: R702.1, U702.2; also elsewhere on the board
USBA1_ISENSE: C708.1, R705.2; also elsewhere on the board
USBA1_OCS_N: U701.4 (/FAULT); also elsewhere on the board
USBA1_PWR_EN: U702.1; also elsewhere on the board
USBA1_SS_RXN: D701.5 (IO4), D701.6 (NC), J701.5 (SSRX-); also elsewhere on the board
USBA1_SS_RXP: D701.4 (IO3), D701.7 (NC), J701.6 (SSRX+); also elsewhere on the board
USBA1_SS_TXN: D701.2 (IO2), D701.9 (NC), J701.8 (SSTX-); also elsewhere on the board
USBA1_SS_TXP: D701.1 (IO1), D701.10 (NC), J701.9 (SSTX+); also elsewhere on the board
USBA2_DN: D704.3, D704.4, J702.2 (D-); also elsewhere on the board
USBA2_DP: D704.1, D704.6, J702.3 (D+); also elsewhere on the board
USBA2_FORCE_EN: R707.1, U705.2; also elsewhere on the board
USBA2_ISENSE: C716.1, R710.2; also elsewhere on the board
USBA2_OCS_N: U704.4 (/FAULT); also elsewhere on the board
USBA2_PWR_EN: U705.1; also elsewhere on the board
USBA2_SS_RXN: D703.5 (IO4), D703.6 (NC), J702.5 (SSRX-); also elsewhere on the board
USBA2_SS_RXP: D703.4 (IO3), D703.7 (NC), J702.6 (SSRX+); also elsewhere on the board
USBA2_SS_TXN: D703.2 (IO2), D703.9 (NC), J702.8 (SSTX-); also elsewhere on the board
USBA2_SS_TXP: D703.1 (IO1), D703.10 (NC), J702.9 (SSTX+); also elsewhere on the board

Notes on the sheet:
USB-A 10G PORTS 2x Amphenol GSB4111312HR (USB 3.2 Gen2), hub ports 2/3 of the USB7206C (usb_hub sheet)
1. USB-A #1 (hub port 2, PRT_CTL2/PF16)
2. USB-A #2 (hub port 3, PRT_CTL3/PF15)
NOTES
AC coupling (USB 3.2 6.2.x: the cap belongs to the TRANSMITTER's board): hub TX -> 220 nF on usb_hub -> USBAx_SS_TX* -> connector
SSTX (pins 9/8). Device TX caps are inside the plugged device -> connector SSRX (pins 6/5) -> USBAx_SS_RX* -> hub RX with NO cap here.
Connector pin names are the USB-IF host-side names (StdA_SSTX = host transmits): hub TX goes to SSTX, not SSRX.
Port power: TPS2553 EN = USBAx_PWR_EN (hub PRT_CTL: ~50k internal pull-up = on, driven low = off) OR USBAx_FORCE_EN (RP2350).
FAULT# (open drain, 7.5 ms deglitch) -> USBAx_OCS_N = same node as PWR_EN (0R on usb_hub). No pull-up on this node here.
Hub-owned port: FAULT# pulls the node low -> hub reads overcurrent, latches the port off (drives low) -> OR output follows.
Forced port (FORCE_EN high): switch stays on in constant-current limit / thermal cycling; FAULT# only pulls the hub's node
(port already off at the hub, or hub reports OC). RP2350 sees the fault as ISENSE pinned at ~1.6-1.8 A -> firmware drops FORCE_EN.
FORCE_EN pull-down 4.7k (not 100k): RP2350 erratum E9 (stepping A2) can leave a pad that was driven high and then
reverted to input latched at ~2.2 V (> LVC1G32 VIH 2.0 V) -> port forced on after a crash/BOOTSEL. Only <= 8.2k defeats
the latch; 4.7k costs 0.7 mA from the push-pull GPIO while forced on (VOH drop negligible at 4 mA drive).
Current limit: RILIM 15.0k -> 1.61 A min / 1.80 A max (TPS2553 DS table): covers BC1.2 DCP/CDP 1.5 A.
Current sense: 30 mOhm before the switch (IN side), INA180A2 x50 -> 1.5 V/A; 2.0 A = 3.0 V, full scale 2.2 A at 3.3 V.
25 mA auto-off threshold = 37.5 mV out; INA180 offset +-150 uV x50 = +-7.5 mV (~5 mA). Shunt loss 1.8 A: 97 mW.
Route IN+/IN- as a Kelvin pair from the inner edges of the shunt pads.
VBUS bulk 150 uF POSCAP + 10 uF + 100 nF per port at the connector (USB 2.0: >= 120 uF per downstream port).
TPS2553 soft start (~1 ms) limits inrush into the bulk; the 10 uF on the switch IN side + +5V rail caps supply the transient.
ESD: TPD4E02B04 (0.25 pF) on the 4 SS lines, USBLC6-2SC6 on D+/D- (clamps to VBUS), all at the connector, flow-through.
Shell / EH tabs and GND_DRAIN -> GND directly (no chassis on odeck-10; via-stitch the tabs to all GND planes).

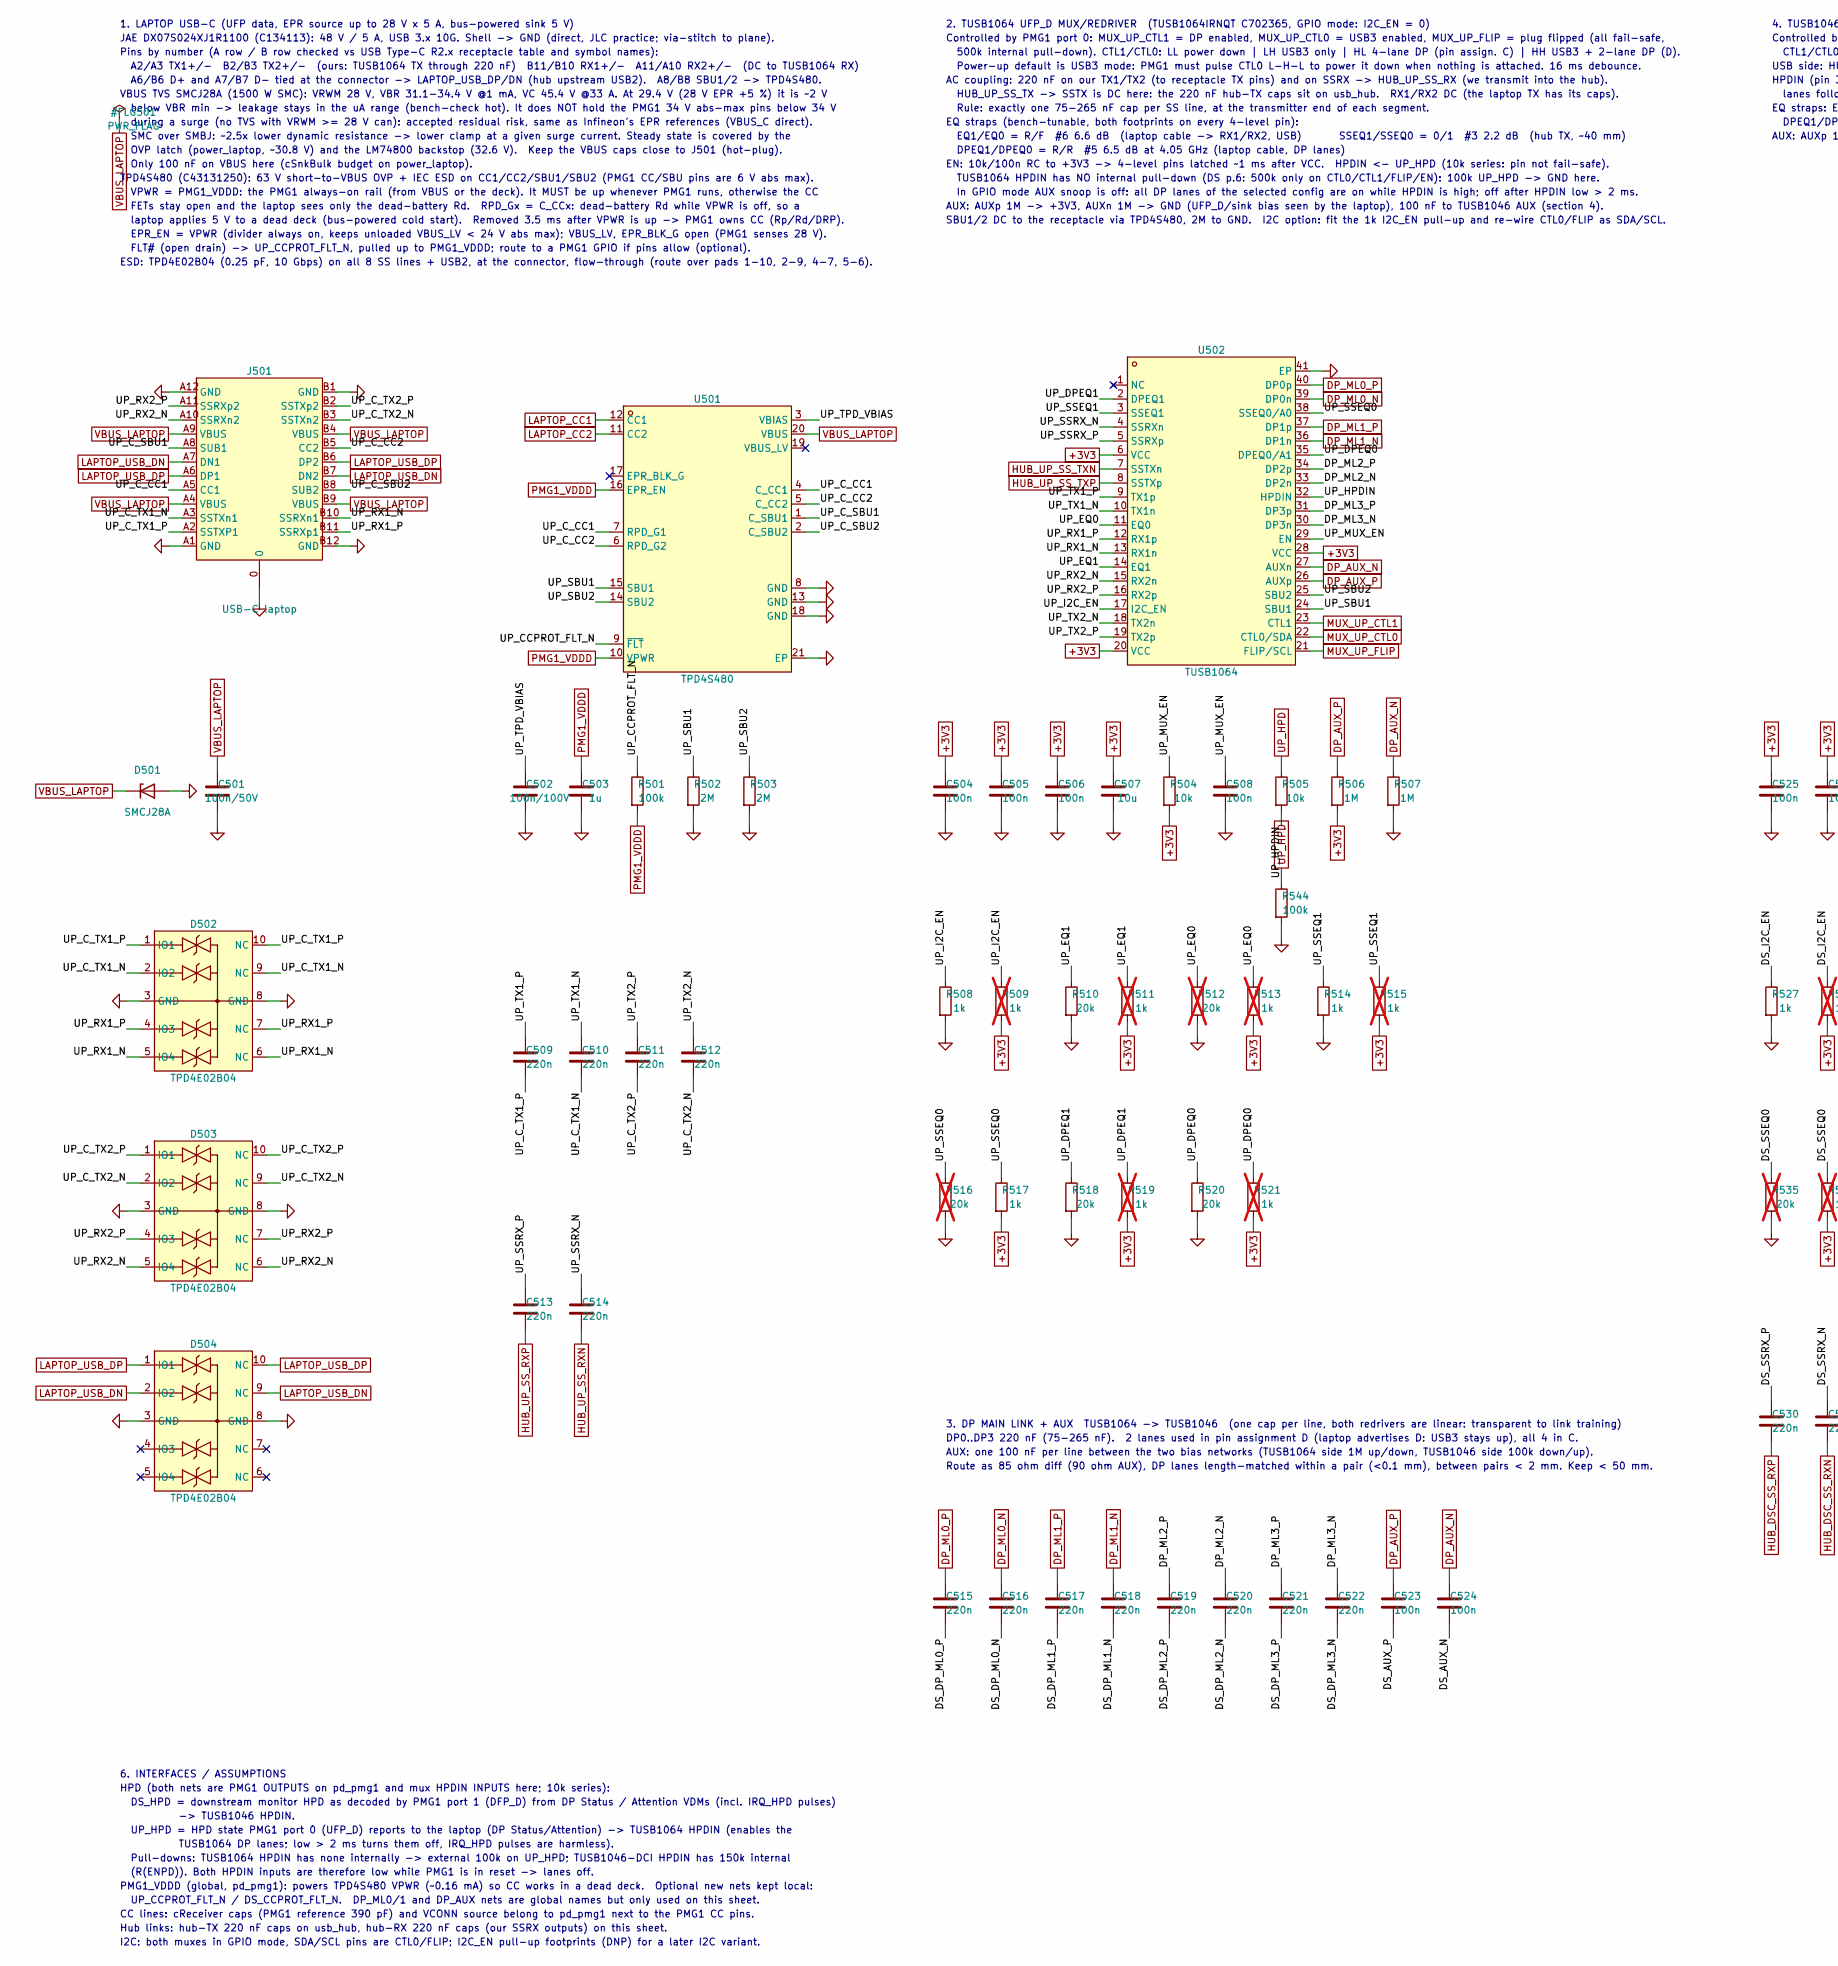
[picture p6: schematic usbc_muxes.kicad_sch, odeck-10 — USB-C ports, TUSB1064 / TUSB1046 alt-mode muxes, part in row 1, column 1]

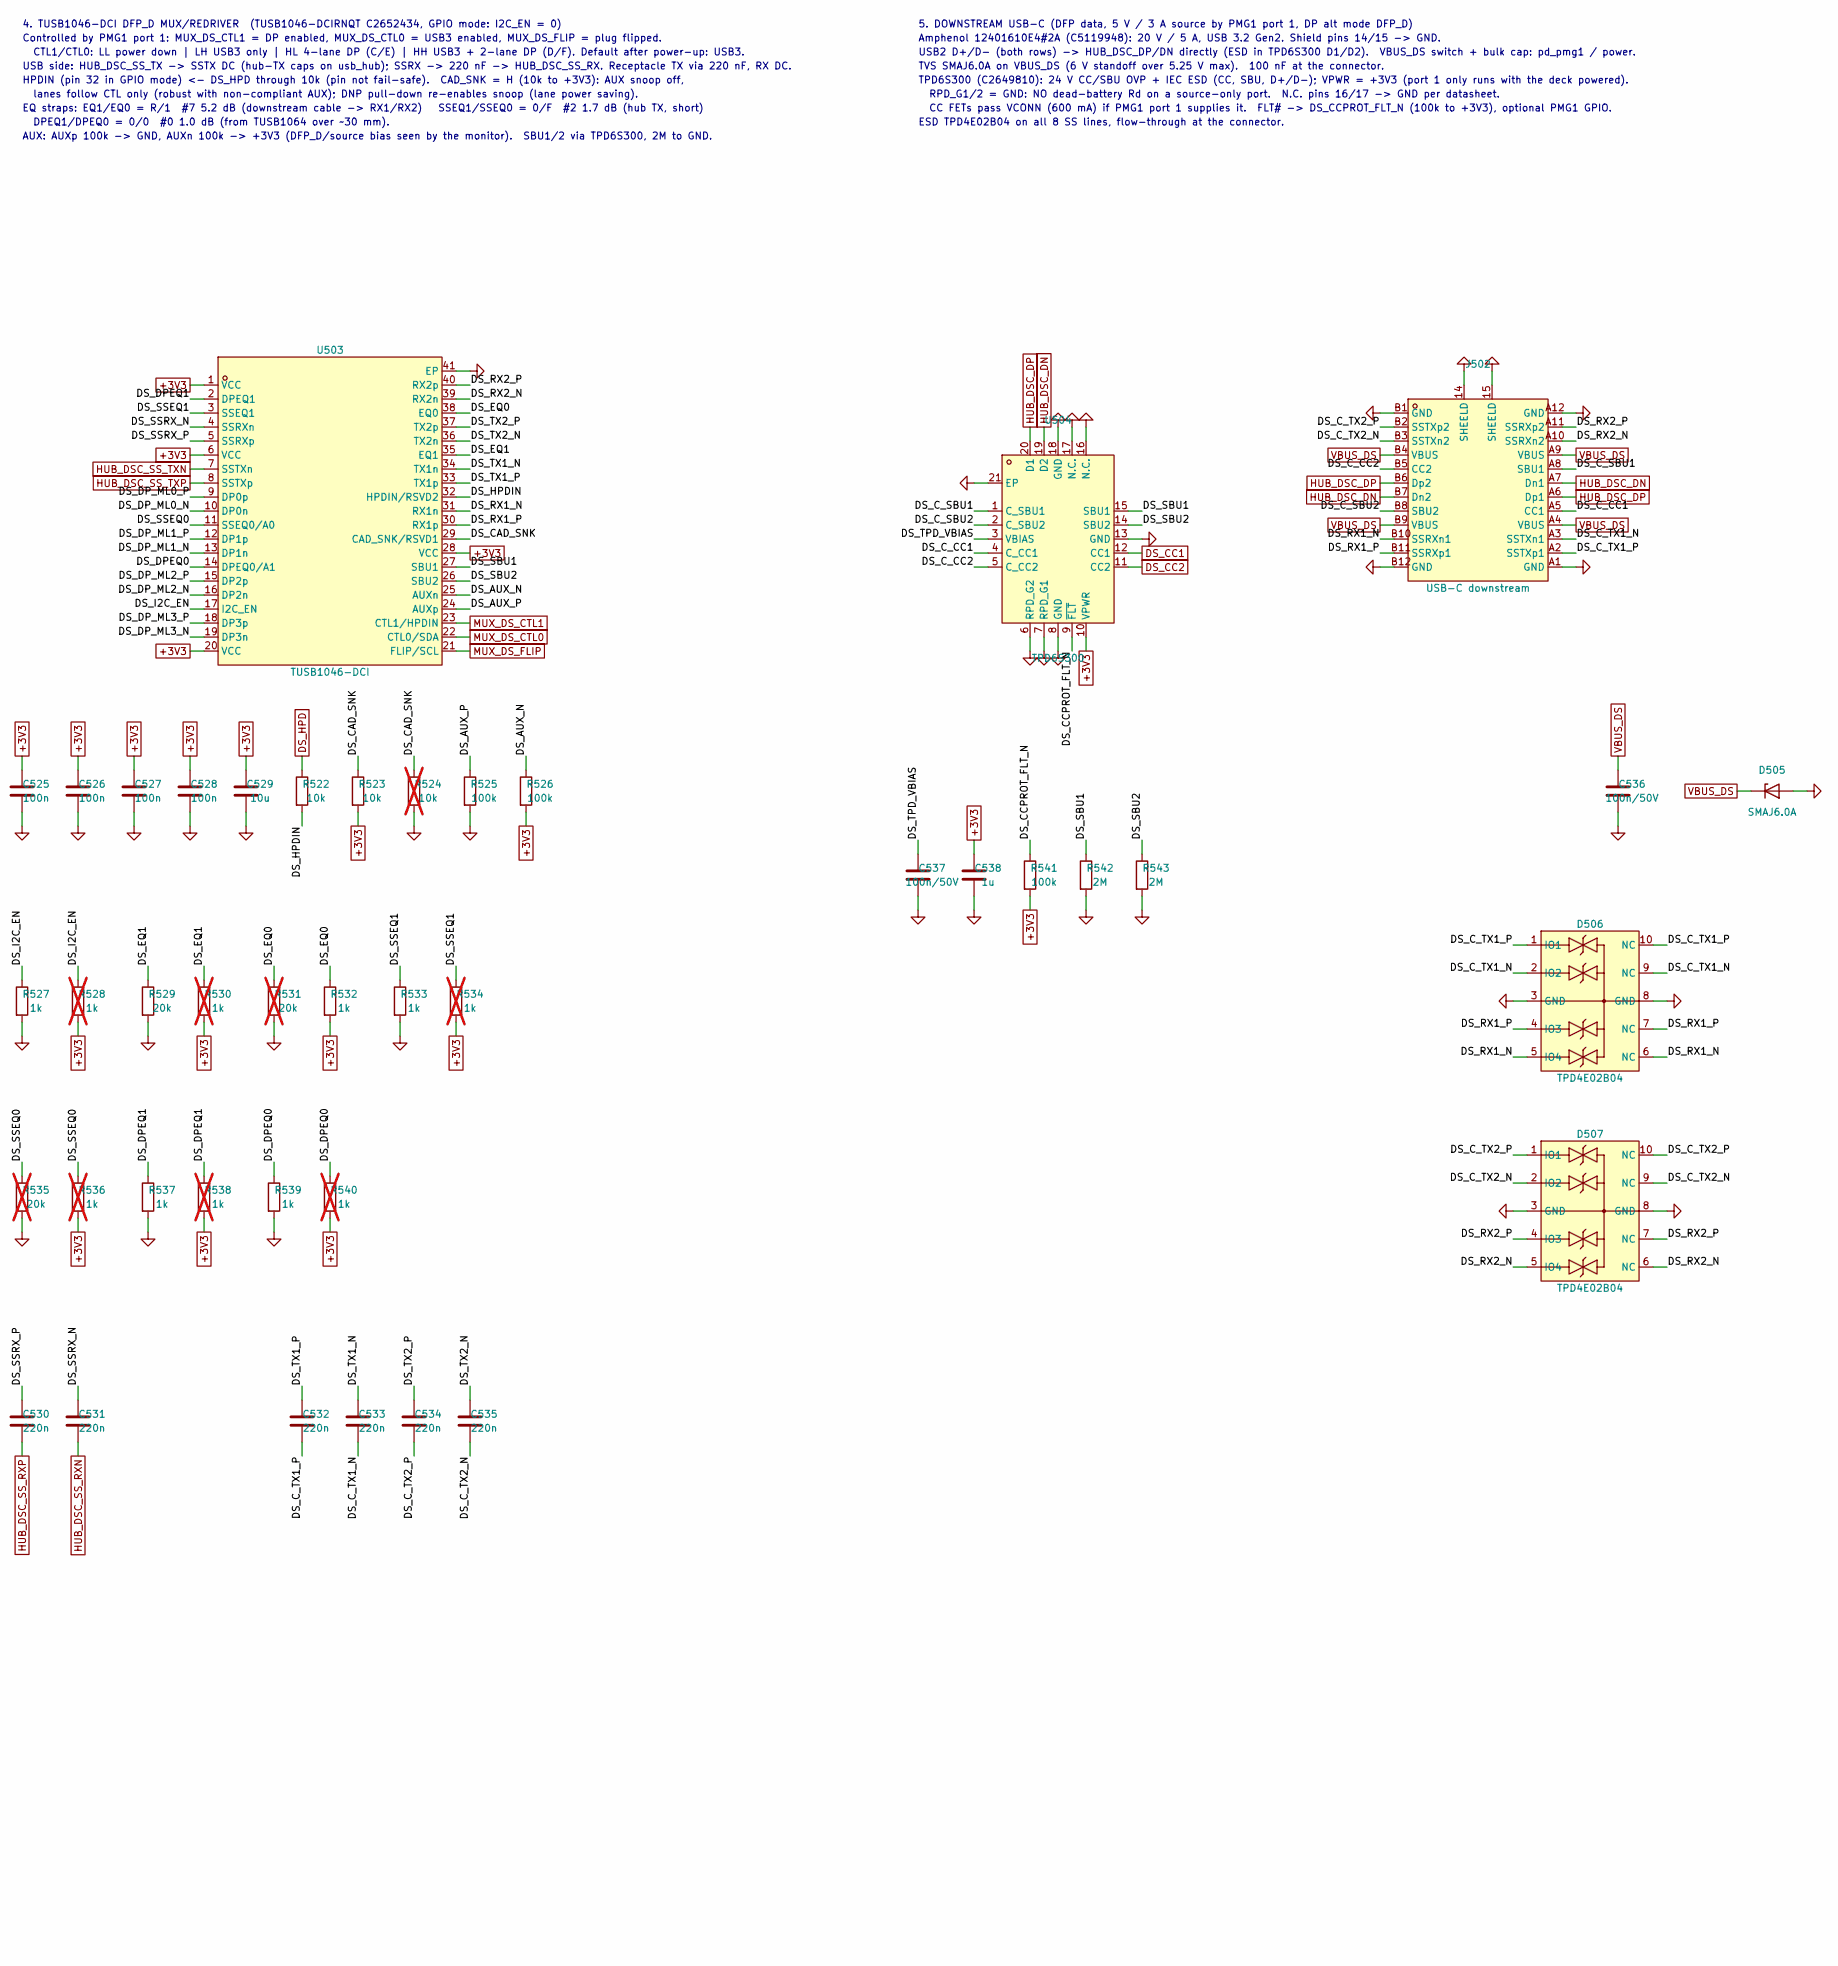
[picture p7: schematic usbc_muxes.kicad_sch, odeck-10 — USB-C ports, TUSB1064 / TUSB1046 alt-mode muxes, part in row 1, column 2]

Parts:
C501, C536, C537: 100n/50V; C_0603_1608Metric; LCSC C14663
C502: 100n/100V; C_0805_2012Metric; LCSC C28233
C503, C538: 1u; C_0402_1005Metric; LCSC C52923
C504, C505, C506, C508, C523, C524, C525, C526, C527, C528: 100n; C_0402_1005Metric; LCSC C1525
C507, C529: 10u; C_0603_1608Metric; LCSC C19702
C509, C510, C511, C512, C513, C514, C515, C516, C517, C518, C519, C520, C521, C522, C530, C531, C532, C533, C534, C535: 220n; C_0402_1005Metric; LCSC C16772
D501: SMCJ28A; D_SMC; LCSC C224047
D502, D503, D504, D506, D507: TPD4E02B04; USON-10_L2.5-W1.0-P0.50-BL; MPN TPD4E02B04DQAR; LCSC C106794
D505: SMAJ6.0A; D_SMA; LCSC C364284
J501: USB-C laptop; USB-C-TH_DX07S024XJ1R1100-1; MPN DX07S024XJ1R1100; LCSC C134113
J502: USB-C downstream; USB-C-SMD_TYPE-C-24P; MPN 12401610E4#2A; LCSC C5119948
R501, R525, R526, R541, R544: 100k; R_0402_1005Metric; LCSC C25741
R502, R503, R542, R543: 2M; R_0603_1608Metric; LCSC C22976
R504, R505, R522, R523: 10k; R_0402_1005Metric; LCSC C25744
R506, R507: 1M; R_0402_1005Metric; LCSC C26083
R508, R514, R517, R527, R532, R533, R537, R539: 1k; R_0402_1005Metric; LCSC C11702
R509, R511, R513, R515, R519, R521, R528, R530, R534, R536, R538, R540: 1k; R_0402_1005Metric; LCSC C11702; not fitted
R510, R518, R520, R529: 20k; R_0402_1005Metric; LCSC C25765
R512, R516, R531, R535: 20k; R_0402_1005Metric; LCSC C25765; not fitted
R524: 10k; R_0402_1005Metric; LCSC C25744; not fitted
U501: TPD4S480; WQFN-20_L3.0-W3.0-P0.40-BL-EP1.7; MPN TPD4S480RUKR; LCSC C43131250
U502: TUSB1064; WQFN-40_L6.0-W4.0-P0.40-TL-EP; MPN TUSB1064IRNQT; LCSC C702365
U503: TUSB1046-DCI; WQFN-40_L6.0-W4.0-P0.40-TL-EP; MPN TUSB1046-DCIRNQT; LCSC C2652434
U504: TPD6S300; WQFN-20_L3.0-W3.0-P0.40-BL-EP1.7; MPN TPD6S300RUKR; LCSC C2649810

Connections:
+3V3: C504.1, C505.1, C506.1, C507.1, C525.1, C526.1, C527.1, C528.1, C529.1, C538.1, R504.2, R506.2, R509.2, R511.2, R513.2, R515.2, R517.2, R519.2, R521.2, R523.2, R526.2, R528.2, R530.2, R532.2, R534.2, R536.2, R538.2, R540.2, R541.2, U502.6 (VCC), U502.20 (VCC), U502.28 (VCC), U503.1 (VCC), U503.6 (VCC), U503.20 (VCC), U503.28 (VCC), U504.10 (VPWR); also elsewhere on the board
/USB-C muxes & DP/DP_ML2_N: C520.1, U502.33 (DP2n)
/USB-C muxes & DP/DP_ML2_P: C519.1, U502.34 (DP2p)
/USB-C muxes & DP/DP_ML3_N: C522.1, U502.30 (DP3n)
/USB-C muxes & DP/DP_ML3_P: C521.1, U502.31 (DP3p)
/USB-C muxes & DP/DS_AUX_N: C524.2, R526.1, U503.25 (AUXn)
/USB-C muxes & DP/DS_AUX_P: C523.2, R525.1, U503.24 (AUXp)
/USB-C muxes & DP/DS_CAD_SNK: R523.1, R524.1, U503.29 (CAD_SNK/RSVD1)
/USB-C muxes & DP/DS_CCPROT_FLT_N: R541.1, U504.9 (~FLT)
/USB-C muxes & DP/DS_C_CC1: J502.A5 (CC1), U504.4 (C_CC1)
/USB-C muxes & DP/DS_C_CC2: J502.B5 (CC2), U504.5 (C_CC2)
/USB-C muxes & DP/DS_C_SBU1: J502.A8 (SBU1), U504.1 (C_SBU1)
/USB-C muxes & DP/DS_C_SBU2: J502.B8 (SBU2), U504.2 (C_SBU2)
/USB-C muxes & DP/DS_C_TX1_N: C533.2, D506.2 (IO2), D506.9 (NC), J502.A3 (SSTXn1)
/USB-C muxes & DP/DS_C_TX1_P: C532.2, D506.1 (IO1), D506.10 (NC), J502.A2 (SSTXp1)
/USB-C muxes & DP/DS_C_TX2_N: C535.2, D507.2 (IO2), D507.9 (NC), J502.B3 (SSTXn2)
/USB-C muxes & DP/DS_C_TX2_P: C534.2, D507.1 (IO1), D507.10 (NC), J502.B2 (SSTXp2)
/USB-C muxes & DP/DS_DPEQ0: R539.1, R540.1, U503.14 (DPEQ0/A1)
/USB-C muxes & DP/DS_DPEQ1: R537.1, R538.1, U503.2 (DPEQ1)
/USB-C muxes & DP/DS_DP_ML0_N: C516.2, U503.10 (DP0n)
/USB-C muxes & DP/DS_DP_ML0_P: C515.2, U503.9 (DP0p)
/USB-C muxes & DP/DS_DP_ML1_N: C518.2, U503.13 (DP1n)
/USB-C muxes & DP/DS_DP_ML1_P: C517.2, U503.12 (DP1p)
/USB-C muxes & DP/DS_DP_ML2_N: C520.2, U503.16 (DP2n)
/USB-C muxes & DP/DS_DP_ML2_P: C519.2, U503.15 (DP2p)
/USB-C muxes & DP/DS_DP_ML3_N: C522.2, U503.19 (DP3n)
/USB-C muxes & DP/DS_DP_ML3_P: C521.2, U503.18 (DP3p)
/USB-C muxes & DP/DS_EQ0: R531.1, R532.1, U503.38 (EQ0)
/USB-C muxes & DP/DS_EQ1: R529.1, R530.1, U503.35 (EQ1)
/USB-C muxes & DP/DS_HPDIN: R522.2, U503.32 (HPDIN/RSVD2)
/USB-C muxes & DP/DS_I2C_EN: R527.1, R528.1, U503.17 (I2C_EN)
/USB-C muxes & DP/DS_RX1_N: D506.5 (IO4), D506.6 (NC), J502.B10 (SSRXn1), U503.31 (RX1n)
/USB-C muxes & DP/DS_RX1_P: D506.4 (IO3), D506.7 (NC), J502.B11 (SSRXp1), U503.30 (RX1p)
/USB-C muxes & DP/DS_RX2_N: D507.5 (IO4), D507.6 (NC), J502.A10 (SSRXn2), U503.39 (RX2n)
/USB-C muxes & DP/DS_RX2_P: D507.4 (IO3), D507.7 (NC), J502.A11 (SSRXp2), U503.40 (RX2p)
/USB-C muxes & DP/DS_SBU1: R542.1, U503.27 (SBU1), U504.15 (SBU1)
/USB-C muxes & DP/DS_SBU2: R543.1, U503.26 (SBU2), U504.14 (SBU2)
/USB-C muxes & DP/DS_SSEQ0: R535.1, R536.1, U503.11 (SSEQ0/A0)
/USB-C muxes & DP/DS_SSEQ1: R533.1, R534.1, U503.3 (SSEQ1)
/USB-C muxes & DP/DS_SSRX_N: C531.1, U503.4 (SSRXn)
/USB-C muxes & DP/DS_SSRX_P: C530.1, U503.5 (SSRXp)
/USB-C muxes & DP/DS_TPD_VBIAS: C537.1, U504.3 (VBIAS)
/USB-C muxes & DP/DS_TX1_N: C533.1, U503.34 (TX1n)
/USB-C muxes & DP/DS_TX1_P: C532.1, U503.33 (TX1p)
/USB-C muxes & DP/DS_TX2_N: C535.1, U503.36 (TX2n)
/USB-C muxes & DP/DS_TX2_P: C534.1, U503.37 (TX2p)
/USB-C muxes & DP/UP_CCPROT_FLT_N: R501.1, U501.9 (~FLT)
/USB-C muxes & DP/UP_C_CC1: J501.A5 (CC1), U501.4 (C_CC1), U501.7 (RPD_G1)
/USB-C muxes & DP/UP_C_CC2: J501.B5 (CC2), U501.5 (C_CC2), U501.6 (RPD_G2)
/USB-C muxes & DP/UP_C_SBU1: J501.A8 (SUB1), U501.1 (C_SBU1)
/USB-C muxes & DP/UP_C_SBU2: J501.B8 (SUB2), U501.2 (C_SBU2)
/USB-C muxes & DP/UP_C_TX1_N: C510.2, D502.2 (IO2), D502.9 (NC), J501.A3 (SSTXn1)
/USB-C muxes & DP/UP_C_TX1_P: C509.2, D502.1 (IO1), D502.10 (NC), J501.A2 (SSTXP1)
/USB-C muxes & DP/UP_C_TX2_N: C512.2, D503.2 (IO2), D503.9 (NC), J501.B3 (SSTXn2)
/USB-C muxes & DP/UP_C_TX2_P: C511.2, D503.1 (IO1), D503.10 (NC), J501.B2 (SSTXp2)
/USB-C muxes & DP/UP_DPEQ0: R520.1, R521.1, U502.35 (DPEQ0/A1)
/USB-C muxes & DP/UP_DPEQ1: R518.1, R519.1, U502.2 (DPEQ1)
/USB-C muxes & DP/UP_EQ0: R512.1, R513.1, U502.11 (EQ0)
/USB-C muxes & DP/UP_EQ1: R510.1, R511.1, U502.14 (EQ1)
/USB-C muxes & DP/UP_HPDIN: R505.2, U502.32 (HPDIN)
/USB-C muxes & DP/UP_I2C_EN: R508.1, R509.1, U502.17 (I2C_EN)
/USB-C muxes & DP/UP_MUX_EN: C508.1, R504.1, U502.29 (EN)
/USB-C muxes & DP/UP_RX1_N: D502.5 (IO4), D502.6 (NC), J501.B10 (SSRXn1), U502.13 (RX1n)
/USB-C muxes & DP/UP_RX1_P: D502.4 (IO3), D502.7 (NC), J501.B11 (SSRXp1), U502.12 (RX1p)
/USB-C muxes & DP/UP_RX2_N: D503.5 (IO4), D503.6 (NC), J501.A10 (SSRXn2), U502.15 (RX2n)
/USB-C muxes & DP/UP_RX2_P: D503.4 (IO3), D503.7 (NC), J501.A11 (SSRXp2), U502.16 (RX2p)
/USB-C muxes & DP/UP_SBU1: R502.1, U501.15 (SBU1), U502.24 (SBU1)
/USB-C muxes & DP/UP_SBU2: R503.1, U501.14 (SBU2), U502.25 (SBU2)
/USB-C muxes & DP/UP_SSEQ0: R516.1, R517.1, U502.38 (SSEQ0/A0)
/USB-C muxes & DP/UP_SSEQ1: R514.1, R515.1, U502.3 (SSEQ1)
/USB-C muxes & DP/UP_SSRX_N: C514.1, U502.4 (SSRXn)
/USB-C muxes & DP/UP_SSRX_P: C513.1, U502.5 (SSRXp)
/USB-C muxes & DP/UP_TPD_VBIAS: C502.1, U501.3 (VBIAS)
/USB-C muxes & DP/UP_TX1_N: C510.1, U502.10 (TX1n)
/USB-C muxes & DP/UP_TX1_P: C509.1, U502.9 (TX1p)
/USB-C muxes & DP/UP_TX2_N: C512.1, U502.18 (TX2n)
/USB-C muxes & DP/UP_TX2_P: C511.1, U502.19 (TX2p)
DP_AUX_N: C524.1, R507.1, U502.27 (AUXn)
DP_AUX_P: C523.1, R506.1, U502.26 (AUXp)
DP_ML0_N: C516.1, U502.39 (DP0n)
DP_ML0_P: C515.1, U502.40 (DP0p)
DP_ML1_N: C518.1, U502.36 (DP1n)
DP_ML1_P: C517.1, U502.37 (DP1p)
DS_CC1: U504.12 (CC1); also elsewhere on the board
DS_CC2: U504.11 (CC2); also elsewhere on the board
DS_HPD: R522.1; also elsewhere on the board
GND: C501.2, C502.2, C503.2, C504.2, C505.2, C506.2, C507.2, C508.2, C525.2, C526.2, C527.2, C528.2, C529.2, C536.2, C537.2, C538.2, D501.2 (A), D502.3 (GND), D502.8 (GND), D503.3 (GND), D503.8 (GND), D504.3 (GND), D504.8 (GND), D505.2 (A), D506.3 (GND), D506.8 (GND), D507.3 (GND), D507.8 (GND), J501.0, J501.A1 (GND), J501.A12 (GND), J501.B1 (GND), J501.B12 (GND), J502.14 (SHEELD), J502.15 (SHEELD), J502.A1 (GND), J502.A12 (GND), J502.B1 (GND), J502.B12 (GND), R502.2, R503.2, R507.2, R508.2, R510.2, R512.2, R514.2, R516.2, R518.2, R520.2, R524.2, R525.2, R527.2, R529.2, R531.2, R533.2, R535.2, R537.2, R539.2, R542.2, R543.2, R544.2, U501.8 (GND), U501.13 (GND), U501.18 (GND), U501.21 (EP), U502.41 (EP), U503.41 (EP), U504.6 (RPD_G2), U504.7 (RPD_G1), U504.8 (GND), U504.13 (GND), U504.16 (N.C.), U504.17 (N.C.), U504.18 (GND), U504.21 (EP); also elsewhere on the board
HUB_DSC_DN: J502.A7 (Dn1), J502.B7 (Dn2), U504.19 (D2); also elsewhere on the board
HUB_DSC_DP: J502.A6 (Dp1), J502.B6 (Dp2), U504.20 (D1); also elsewhere on the board
HUB_DSC_SS_RXN: C531.2; also elsewhere on the board
HUB_DSC_SS_RXP: C530.2; also elsewhere on the board
HUB_DSC_SS_TXN: U503.7 (SSTXn); also elsewhere on the board
HUB_DSC_SS_TXP: U503.8 (SSTXp); also elsewhere on the board
HUB_UP_SS_RXN: C514.2; also elsewhere on the board
HUB_UP_SS_RXP: C513.2; also elsewhere on the board
HUB_UP_SS_TXN: U502.7 (SSTXn); also elsewhere on the board
HUB_UP_SS_TXP: U502.8 (SSTXp); also elsewhere on the board
LAPTOP_CC1: U501.12 (CC1); also elsewhere on the board
LAPTOP_CC2: U501.11 (CC2); also elsewhere on the board
LAPTOP_USB_DN: D504.2 (IO2), D504.9 (NC), J501.A7 (DN1), J501.B7 (DN2); also elsewhere on the board
LAPTOP_USB_DP: D504.1 (IO1), D504.10 (NC), J501.A6 (DP1), J501.B6 (DP2); also elsewhere on the board
MUX_DS_CTL0: U503.22 (CTL0/SDA); also elsewhere on the board
MUX_DS_CTL1: U503.23 (CTL1/HPDIN); also elsewhere on the board
MUX_DS_FLIP: U503.21 (FLIP/SCL); also elsewhere on the board
MUX_UP_CTL0: U502.22 (CTL0/SDA); also elsewhere on the board
MUX_UP_CTL1: U502.23 (CTL1); also elsewhere on the board
MUX_UP_FLIP: U502.21 (FLIP/SCL); also elsewhere on the board
PMG1_VDDD: C503.1, R501.2, U501.10 (VPWR), U501.16 (EPR_EN); also elsewhere on the board
UP_HPD: R505.1, R544.1; also elsewhere on the board
VBUS_DS: C536.1, D505.1 (K), J502.A4 (VBUS), J502.A9 (VBUS), J502.B4 (VBUS), J502.B9 (VBUS); also elsewhere on the board
VBUS_LAPTOP: C501.1, D501.1 (K), J501.A4 (VBUS), J501.A9 (VBUS), J501.B4 (VBUS), J501.B9 (VBUS), U501.20 (VBUS); also elsewhere on the board

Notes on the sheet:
1. LAPTOP USB-C (UFP data, EPR source up to 28 V x 5 A, bus-powered sink 5 V)
JAE DX07S024XJ1R1100 (C134113): 48 V / 5 A, USB 3.x 10G. Shell -> GND (direct, JLC practice; via-stitch to plane).
Pins by number (A row / B row checked vs USB Type-C R2.x receptacle table and symbol names):
A2/A3 TX1+/- B2/B3 TX2+/- (ours: TUSB1064 TX through 220 nF) B11/B10 RX1+/- A11/A10 RX2+/- (DC to TUSB1064 RX)
A6/B6 D+ and A7/B7 D- tied at the connector -> LAPTOP_USB_DP/DN (hub upstream USB2). A8/B8 SBU1/2 -> TPD4S480.
VBUS TVS SMCJ28A (1500 W SMC): VRWM 28 V, VBR 31.1-34.4 V @1 mA, VC 45.4 V @33 A. At 29.4 V (28 V EPR +5 %) it is ~2 V
below VBR min -> leakage stays in the uA range (bench-check hot). It does NOT hold the PMG1 34 V abs-max pins below 34 V
during a surge (no TVS with VRWM >= 28 V can): accepted residual risk, same as Infineon's EPR references (VBUS_C direct).
SMC over SMBJ: ~2.5x lower dynamic resistance -> lower clamp at a given surge current. Steady state is covered by the
OVP latch (power_laptop, ~30.8 V) and the LM74800 backstop (32.6 V). Keep the VBUS caps close to J501 (hot-plug).
Only 100 nF on VBUS here (cSnkBulk budget on power_laptop).
TPD4S480 (C43131250): 63 V short-to-VBUS OVP + IEC ESD on CC1/CC2/SBU1/SBU2 (PMG1 CC/SBU pins are 6 V abs max).
VPWR = PMG1_VDDD: the PMG1 always-on rail (from VBUS or the deck). It MUST be up whenever PMG1 runs, otherwise the CC
FETs stay open and the laptop sees only the dead-battery Rd. RPD_Gx = C_CCx: dead-battery Rd while VPWR is off, so a
laptop applies 5 V to a dead deck (bus-powered cold start). Removed 3.5 ms after VPWR is up -> PMG1 owns CC (Rp/Rd/DRP).
EPR_EN = VPWR (divider always on, keeps unloaded VBUS_LV < 24 V abs max); VBUS_LV, EPR_BLK_G open (PMG1 senses 28 V).
FLT# (open drain) -> UP_CCPROT_FLT_N, pulled up to PMG1_VDDD; route to a PMG1 GPIO if pins allow (optional).
ESD: TPD4E02B04 (0.25 pF, 10 Gbps) on all 8 SS lines + USB2, at the connector, flow-through (route over pads 1-10, 2-9, 4-7, 5-6).
2. TUSB1064 UFP_D MUX/REDRIVER (TUSB1064IRNQT C702365, GPIO mode: I2C_EN = 0)
Controlled by PMG1 port 0: MUX_UP_CTL1 = DP enabled, MUX_UP_CTL0 = USB3 enabled, MUX_UP_FLIP = plug flipped (all fail-safe,
500k internal pull-down). CTL1/CTL0: LL power down | LH USB3 only | HL 4-lane DP (pin assign. C) | HH USB3 + 2-lane DP (D).
Power-up default is USB3 mode: PMG1 must pulse CTL0 L-H-L to power it down when nothing is attached. 16 ms debounce.
AC coupling: 220 nF on our TX1/TX2 (to receptacle TX pins) and on SSRX -> HUB_UP_SS_RX (we transmit into the hub).
HUB_UP_SS_TX -> SSTX is DC here: the 220 nF hub-TX caps sit on usb_hub. RX1/RX2 DC (the laptop TX has its caps).
Rule: exactly one 75-265 nF cap per SS line, at the transmitter end of each segment.
EQ straps (bench-tunable, both footprints on every 4-level pin):
EQ1/EQ0 = R/F #6 6.6 dB (laptop cable -> RX1/RX2, USB) SSEQ1/SSEQ0 = 0/1 #3 2.2 dB (hub TX, ~40 mm)
DPEQ1/DPEQ0 = R/R #5 6.5 dB at 4.05 GHz (laptop cable, DP lanes)
EN: 10k/100n RC to +3V3 -> 4-level pins latched ~1 ms after VCC. HPDIN <- UP_HPD (10k series: pin not fail-safe).
TUSB1064 HPDIN has NO internal pull-down (DS p.6: 500k only on CTL0/CTL1/FLIP/EN): 100k UP_HPD -> GND here.
In GPIO mode AUX snoop is off: all DP lanes of the selected config are on while HPDIN is high; off after HPDIN low > 2 ms.
AUX: AUXp 1M -> +3V3, AUXn 1M -> GND (UFP_D/sink bias seen by the laptop), 100 nF to TUSB1046 AUX (section 4).
SBU1/2 DC to the receptacle via TPD4S480, 2M to GND. I2C option: fit the 1k I2C_EN pull-up and re-wire CTL0/FLIP as SDA/SCL.
3. DP MAIN LINK + AUX TUSB1064 -> TUSB1046 (one cap per line, both redrivers are linear: transparent to link training)
DP0..DP3 220 nF (75-265 nF). 2 lanes used in pin assignment D (laptop advertises D: USB3 stays up), all 4 in C.
AUX: one 100 nF per line between the two bias networks (TUSB1064 side 1M up/down, TUSB1046 side 100k down/up).
Route as 85 ohm diff (90 ohm AUX), DP lanes length-matched within a pair (<0.1 mm), between pairs < 2 mm. Keep < 50 mm.
4. TUSB1046-DCI DFP_D MUX/REDRIVER (TUSB1046-DCIRNQT C2652434, GPIO mode: I2C_EN = 0)
Controlled by PMG1 port 1: MUX_DS_CTL1 = DP enabled, MUX_DS_CTL0 = USB3 enabled, MUX_DS_FLIP = plug flipped.
CTL1/CTL0: LL power down | LH USB3 only | HL 4-lane DP (C/E) | HH USB3 + 2-lane DP (D/F). Default after power-up: USB3.

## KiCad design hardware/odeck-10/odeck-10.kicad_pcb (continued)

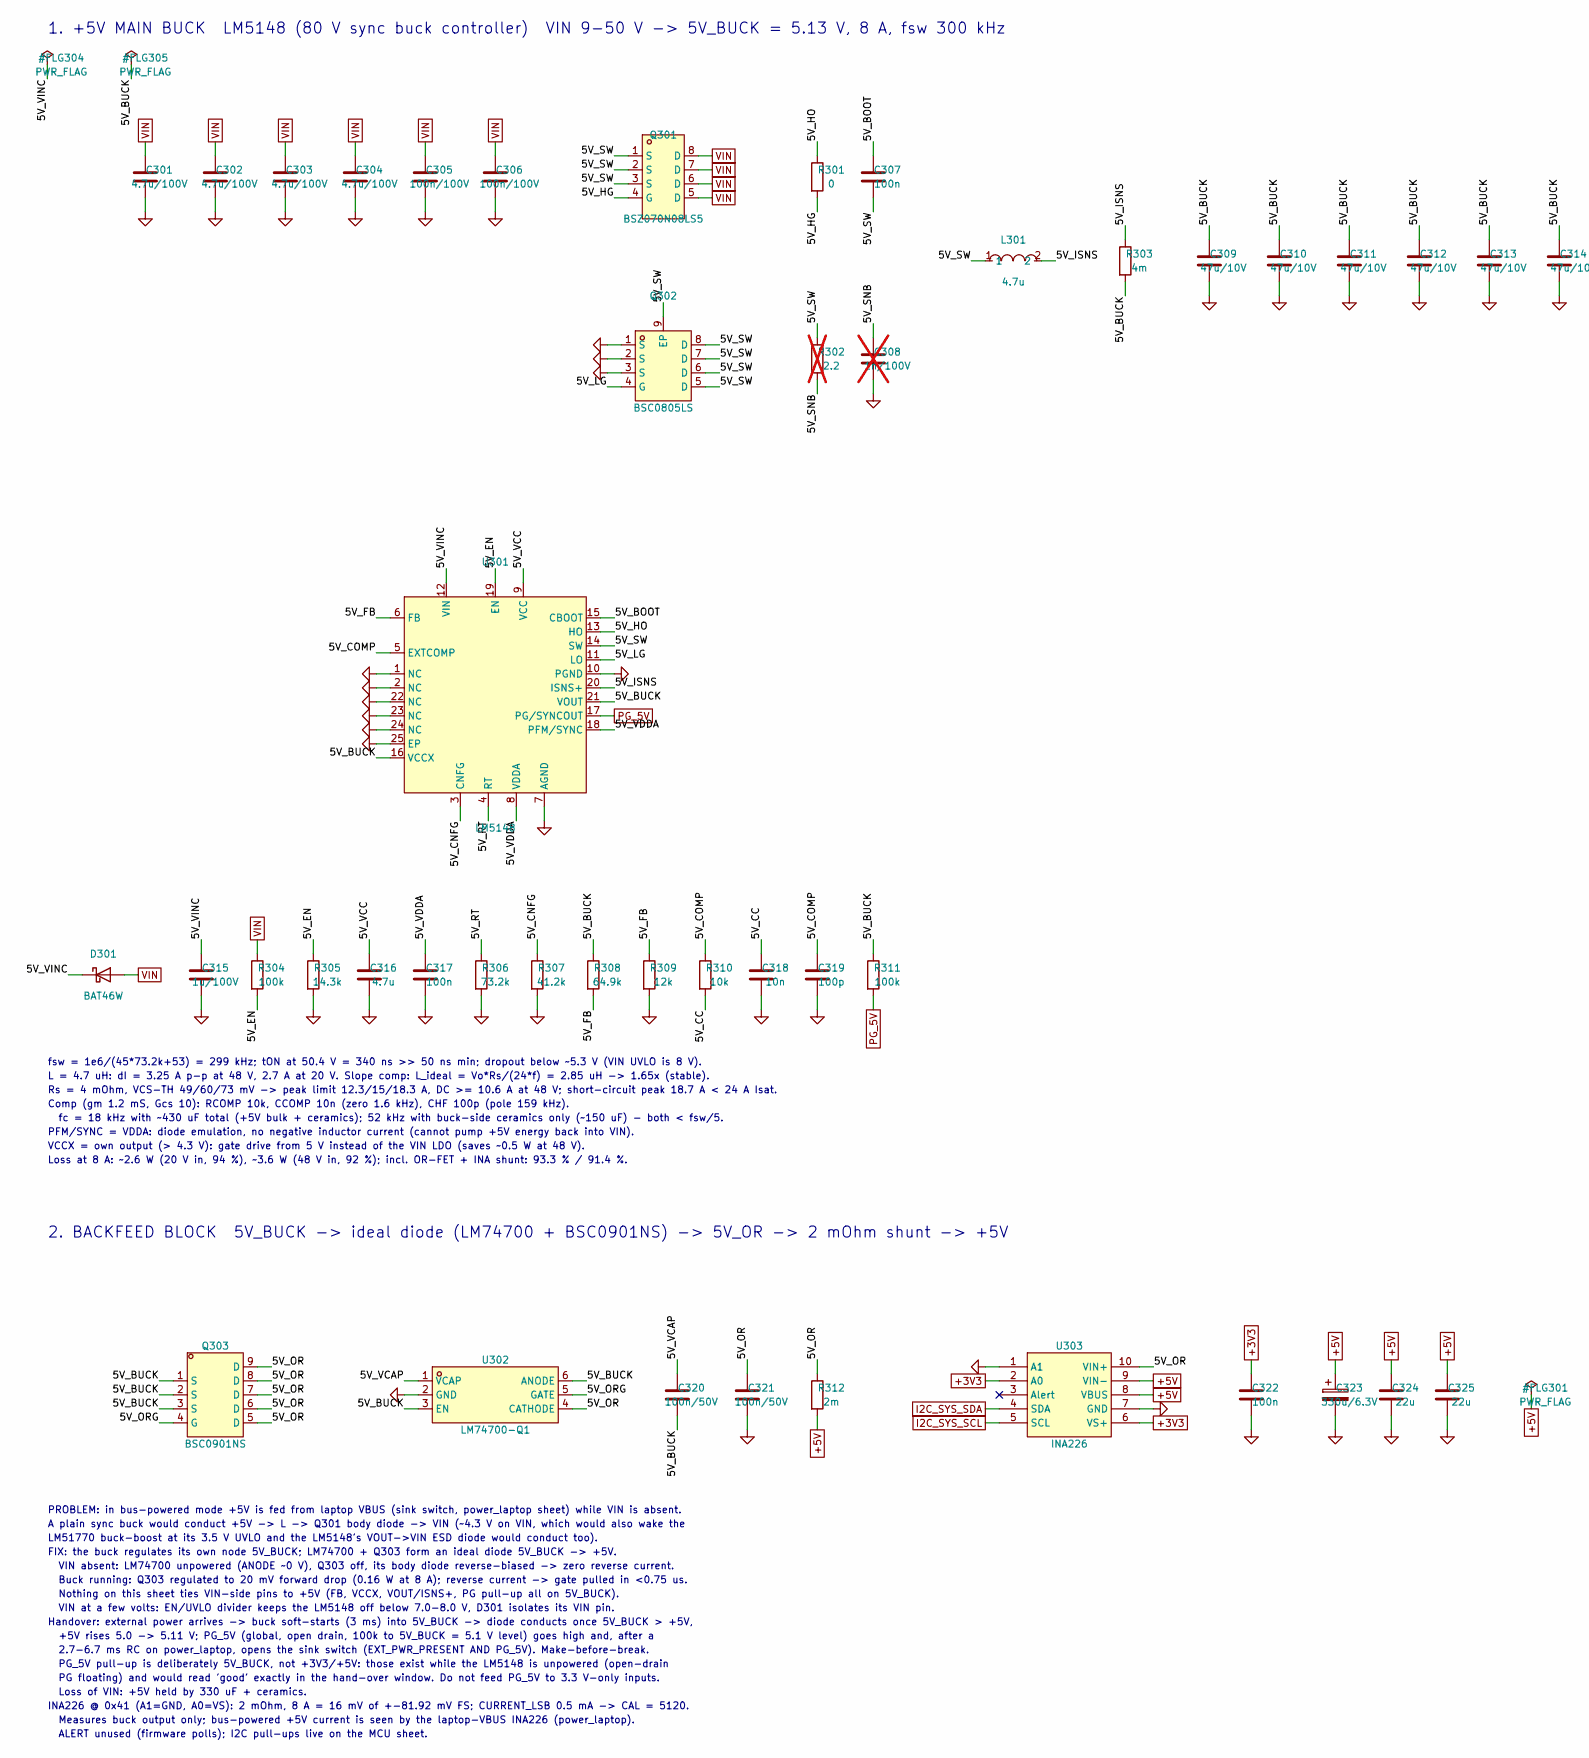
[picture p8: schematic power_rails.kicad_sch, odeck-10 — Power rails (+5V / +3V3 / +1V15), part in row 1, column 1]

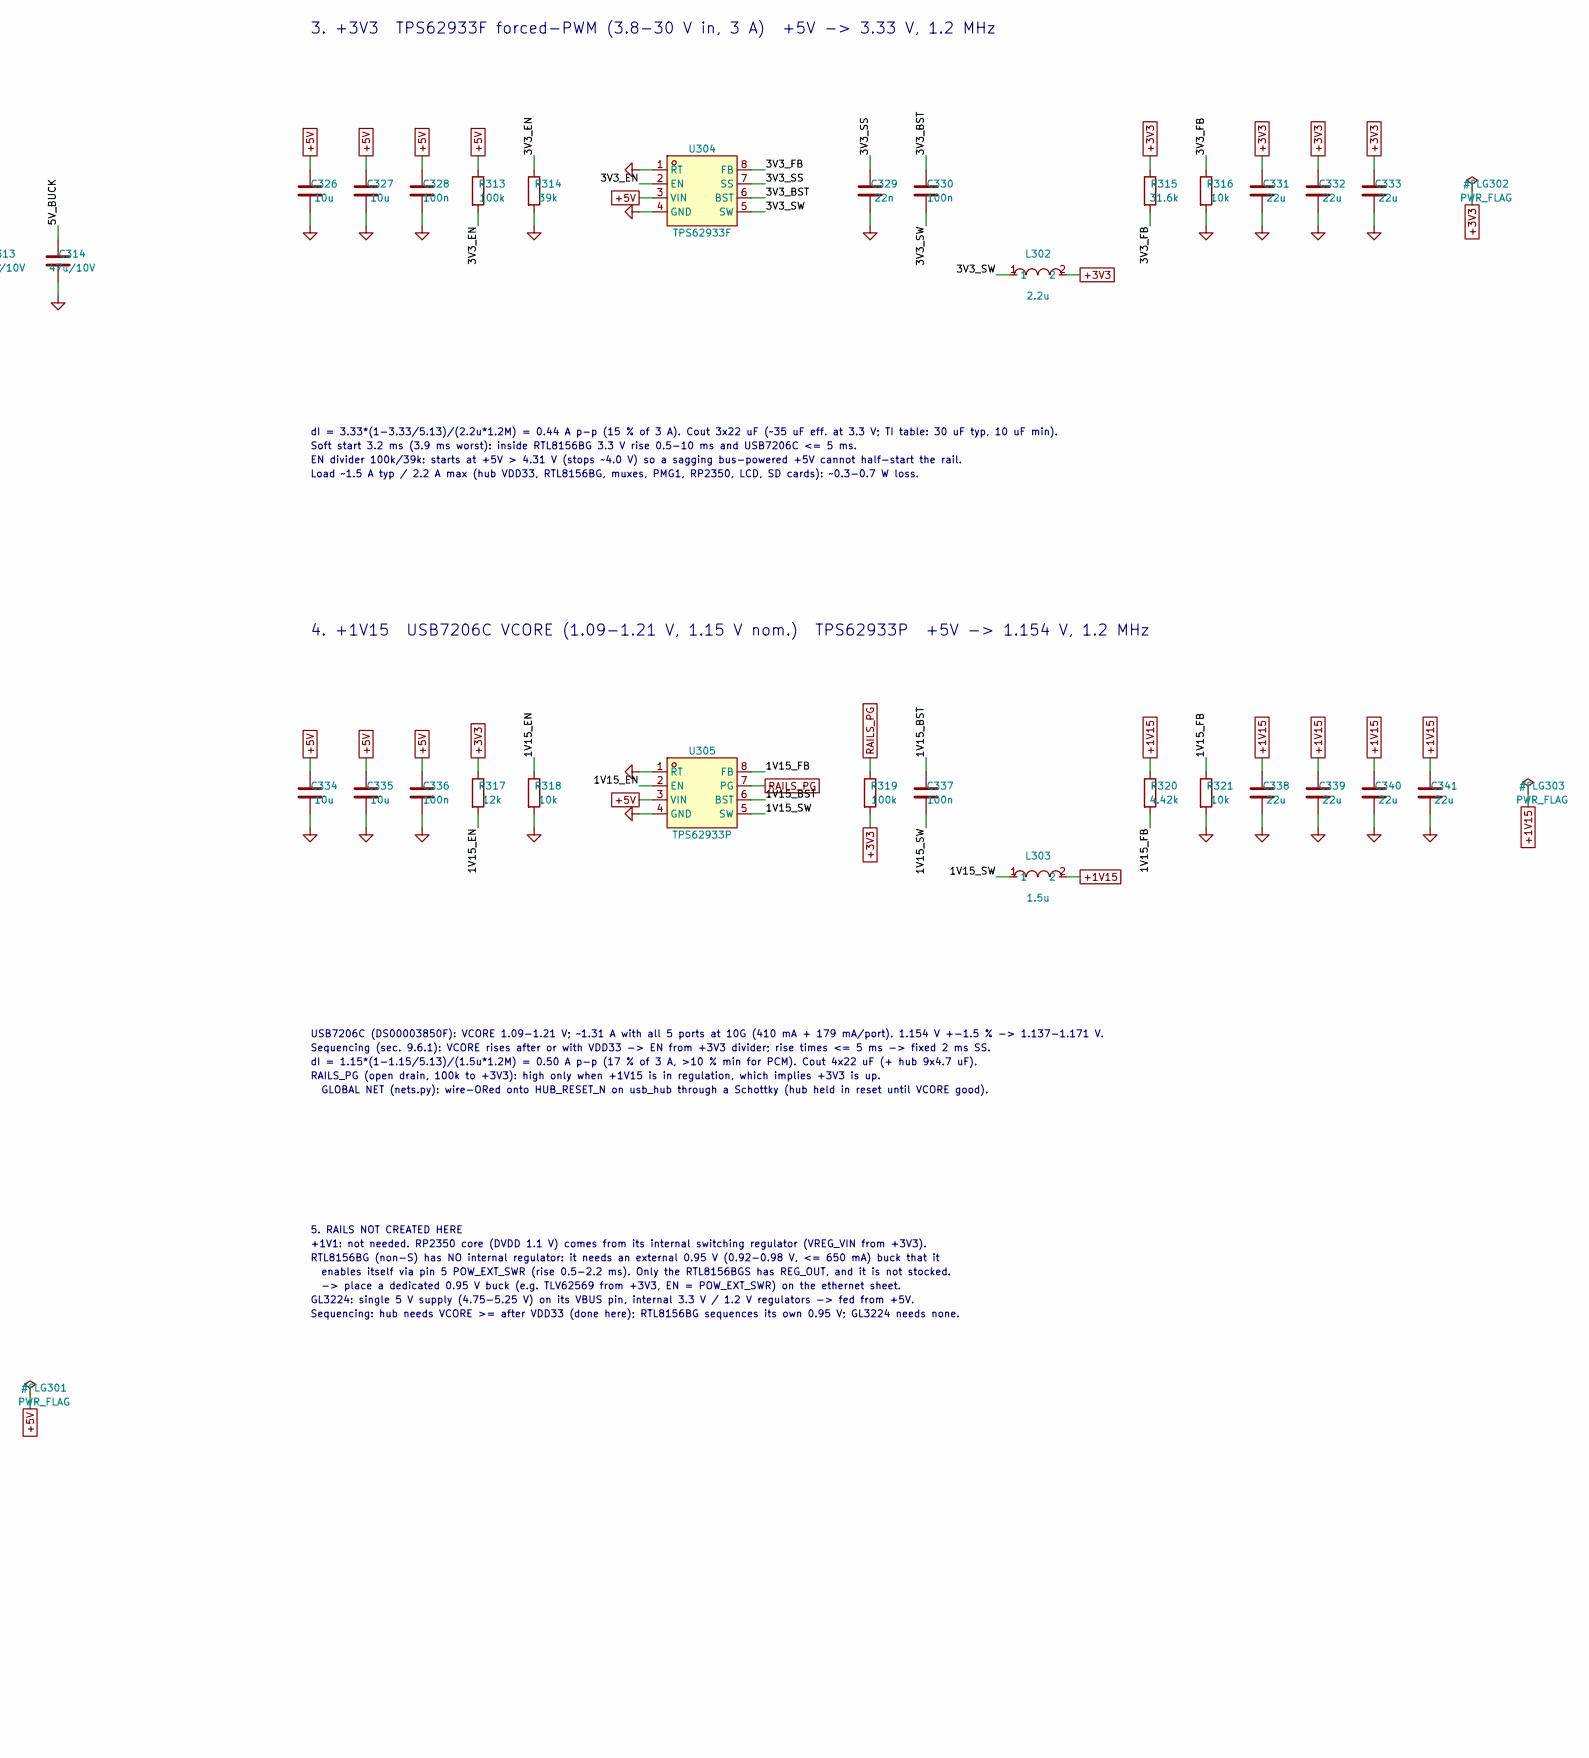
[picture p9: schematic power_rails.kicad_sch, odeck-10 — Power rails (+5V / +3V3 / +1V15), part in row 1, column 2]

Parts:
C301, C302, C303, C304: 4.7u/100V; C_1210_3225Metric; LCSC C697607
C305, C306: 100n/100V; C_0805_2012Metric; LCSC C28233
C307, C317, C322, C328, C330, C336, C337: 100n; C_0402_1005Metric; LCSC C1525
C308: 1n/100V; C_0603_1608Metric; LCSC C106247; not fitted
C309, C310, C311, C312, C313, C314: 47u/10V; C_1210_3225Metric; LCSC C84494
C315: 1u/100V; C_0805_2012Metric; LCSC C126585
C316: 4.7u; C_0603_1608Metric; LCSC C19666
C318: 10n; C_0402_1005Metric; LCSC C15195
C319: 100p; C_0402_1005Metric; LCSC C1546
C320, C321: 100n/50V; C_0603_1608Metric; LCSC C14663
C323: 330u/6.3V; CP_Elec_6.3x5.9; LCSC C54321566
C324, C325, C331, C332, C333: 22u; C_0805_2012Metric; LCSC C45783
C326, C327, C334, C335: 10u; C_0805_2012Metric; LCSC C15850
C329: 22n; C_0402_1005Metric; LCSC C1532
C338, C339, C340, C341: 22u; C_0603_1608Metric; LCSC C59461
D301: BAT46W; D_SOD-123; LCSC C83152
L301: 4.7u; IND-SMD_L13.45-W12.6; MPN MWSA1206S-4R7MT; LCSC C408521
L302: 2.2u; IND-SMD_L5.4-W5.2; MPN MWSA0503S-2R2MT; LCSC C408408
L303: 1.5u; IND-SMD_L5.4-W5.2; MPN MWSA0503S-1R5MT; LCSC C408407
Q301: BSZ070N08LS5; PG-TSDSON-8_L3.3-W3.3-P0.65-BL-1; MPN BSZ070N08LS5; LCSC C534678
Q302: BSC0805LS; PG-TDSON-8_L5.2-W5.9-P1.27-LS6.2-BL-EP; MPN BSC0805LS; LCSC C534374
Q303: BSC0901NS; DFN-8_L5.9-W5.2-P1.27-LS6.2-BL; MPN BSC0901NS; LCSC C152424
R301: 0; R_0402_1005Metric; LCSC C17168
R302: 2.2; R_0805_2012Metric; LCSC C17521; not fitted
R303: 4m; R_2512_6332Metric; LCSC C459681
R304: 100k; R_0805_2012Metric; LCSC C149504
R305: 14.3k; R_0402_1005Metric; LCSC C25855
R306: 73.2k; R_0402_1005Metric; LCSC C26986
R307: 41.2k; R_0402_1005Metric; LCSC C100420
R308: 64.9k; R_0402_1005Metric; LCSC C26984
R309, R317: 12k; R_0402_1005Metric; LCSC C25752
R310, R316, R318, R321: 10k; R_0402_1005Metric; LCSC C25744
R311, R313, R319: 100k; R_0402_1005Metric; LCSC C25741
R312: 2m; R_2512_6332Metric; LCSC C459679
R314: 39k; R_0603_1608Metric; LCSC C23153
R315: 31.6k; R_0402_1005Metric; LCSC C11463
R320: 4.42k; R_0402_1005Metric; LCSC C52269
U301: LM5148; VQFN-24_L5.5-W3.5-P0.50-BL-EP-2; MPN LM5148RGYR; LCSC C7470701
U302: LM74700-Q1; SOT-23-6_L2.9-W1.6-P0.95-LS2.8-TL; MPN LM74700QDBVTQ1; LCSC C2653623
U303: INA226; MSOP-10_L3.0-W3.0-P0.50-LS5.0-BL; MPN INA226AIDGSR; LCSC C49851
U304: TPS62933F; SOT-583-8_L2.1-W1.2-P0.50-LS1.6-BR; MPN TPS62933FDRLR; LCSC C5219272
U305: TPS62933P; SOT-583-8_L2.1-W1.2-P0.50-LS1.6-BL; MPN TPS62933PDRLR; LCSC C5219254

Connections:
+1V15: C338.1, C339.1, C340.1, C341.1, L303.2, R320.1; also elsewhere on the board
+3V3: C322.1, C331.1, C332.1, C333.1, L302.2, R315.1, R317.1, R319.2, U303.2 (A0), U303.6 (VS+); also elsewhere on the board
+5V: C323.1, C324.1, C325.1, C326.1, C327.1, C328.1, C334.1, C335.1, C336.1, R312.2, R313.1, U303.8 (VBUS), U303.9 (VIN-), U304.3 (VIN), U305.3 (VIN); also elsewhere on the board
/Rails/1V15_BST: C337.1, U305.6 (BST)
/Rails/1V15_EN: R317.2, R318.1, U305.2 (EN)
/Rails/1V15_FB: R320.2, R321.1, U305.8 (FB)
/Rails/1V15_SW: C337.2, L303.1, U305.5 (SW)
/Rails/3V3_BST: C330.1, U304.6 (BST)
/Rails/3V3_EN: R313.2, R314.1, U304.2 (EN)
/Rails/3V3_FB: R315.2, R316.1, U304.8 (FB)
/Rails/3V3_SS: C329.1, U304.7 (SS)
/Rails/3V3_SW: C330.2, L302.1, U304.5 (SW)
/Rails/5V_BOOT: C307.1, U301.15 (CBOOT)
/Rails/5V_BUCK: C309.1, C310.1, C311.1, C312.1, C313.1, C314.1, C320.2, Q303.1 (S), Q303.2 (S), Q303.3 (S), R303.2, R308.1, R311.1, U301.16 (VCCX), U301.21 (VOUT), U302.3 (EN), U302.6 (ANODE)
/Rails/5V_CC: C318.1, R310.2
/Rails/5V_CNFG: R307.1, U301.3 (CNFG)
/Rails/5V_COMP: C319.1, R310.1, U301.5 (EXTCOMP)
/Rails/5V_EN: R304.2, R305.1, U301.19 (EN)
/Rails/5V_FB: R308.2, R309.1, U301.6 (FB)
/Rails/5V_HG: Q301.4 (G), R301.2
/Rails/5V_HO: R301.1, U301.13 (HO)
/Rails/5V_ISNS: L301.2, R303.1, U301.20 (ISNS+)
/Rails/5V_LG: Q302.4 (G), U301.11 (LO)
/Rails/5V_OR: C321.1, Q303.5 (D), Q303.6 (D), Q303.7 (D), Q303.8 (D), Q303.9 (D), R312.1, U302.4 (CATHODE), U303.10 (VIN+)
/Rails/5V_ORG: Q303.4 (G), U302.5 (GATE)
/Rails/5V_RT: R306.1, U301.4 (RT)
/Rails/5V_SNB: C308.1, R302.2
/Rails/5V_SW: C307.2, L301.1, Q301.1 (S), Q301.2 (S), Q301.3 (S), Q302.5 (D), Q302.6 (D), Q302.7 (D), Q302.8 (D), Q302.9 (EP), R302.1, U301.14 (SW)
/Rails/5V_VCAP: C320.1, U302.1 (VCAP)
/Rails/5V_VCC: C316.1, U301.9 (VCC)
/Rails/5V_VDDA: C317.1, U301.8 (VDDA), U301.18 (PFM/SYNC)
/Rails/5V_VINC: C315.1, D301.1 (K), U301.12 (VIN)
GND: C301.2, C302.2, C303.2, C304.2, C305.2, C306.2, C308.2, C309.2, C310.2, C311.2, C312.2, C313.2, C314.2, C315.2, C316.2, C317.2, C318.2, C319.2, C321.2, C322.2, C323.2, C324.2, C325.2, C326.2, C327.2, C328.2, C329.2, C331.2, C332.2, C333.2, C334.2, C335.2, C336.2, C338.2, C339.2, C340.2, C341.2, Q302.1 (S), Q302.2 (S), Q302.3 (S), R305.2, R306.2, R307.2, R309.2, R314.2, R316.2, R318.2, R321.2, U301.1 (NC), U301.2 (NC), U301.7 (AGND), U301.10 (PGND), U301.22 (NC), U301.23 (NC), U301.24 (NC), U301.25 (EP), U302.2 (GND), U303.1 (A1), U303.7 (GND), U304.1 (RT), U304.4 (GND), U305.1 (RT), U305.4 (GND); also elsewhere on the board
I2C_SYS_SCL: U303.5 (SCL); also elsewhere on the board
I2C_SYS_SDA: U303.4 (SDA); also elsewhere on the board
PG_5V: R311.2, U301.17 (PG/SYNCOUT); also elsewhere on the board
RAILS_PG: R319.1, U305.7 (PG); also elsewhere on the board
VIN: C301.1, C302.1, C303.1, C304.1, C305.1, C306.1, D301.2 (A), Q301.5 (D), Q301.6 (D), Q301.7 (D), Q301.8 (D), R304.1; also elsewhere on the board

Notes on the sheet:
1. +5V MAIN BUCK LM5148 (80 V sync buck controller) VIN 9-50 V -> 5V_BUCK = 5.13 V, 8 A, fsw 300 kHz
fsw = 1e6/(45*73.2k+53) = 299 kHz; tON at 50.4 V = 340 ns >> 50 ns min; dropout below ~5.3 V (VIN UVLO is 8 V).
L = 4.7 uH: dI = 3.25 A p-p at 48 V, 2.7 A at 20 V. Slope comp: L_ideal = Vo*Rs/(24*f) = 2.85 uH -> 1.65x (stable).
Rs = 4 mOhm, VCS-TH 49/60/73 mV -> peak limit 12.3/15/18.3 A, DC >= 10.6 A at 48 V; short-circuit peak 18.7 A < 24 A Isat.
Comp (gm 1.2 mS, Gcs 10): RCOMP 10k, CCOMP 10n (zero 1.6 kHz), CHF 100p (pole 159 kHz).
fc = 18 kHz with ~430 uF total (+5V bulk + ceramics); 52 kHz with buck-side ceramics only (~150 uF) - both < fsw/5.
PFM/SYNC = VDDA: diode emulation, no negative inductor current (cannot pump +5V energy back into VIN).
VCCX = own output (> 4.3 V): gate drive from 5 V instead of the VIN LDO (saves ~0.5 W at 48 V).
Loss at 8 A: ~2.6 W (20 V in, 94 %), ~3.6 W (48 V in, 92 %); incl. OR-FET + INA shunt: 93.3 % / 91.4 %.
2. BACKFEED BLOCK 5V_BUCK -> ideal diode (LM74700 + BSC0901NS) -> 5V_OR -> 2 mOhm shunt -> +5V
PROBLEM: in bus-powered mode +5V is fed from laptop VBUS (sink switch, power_laptop sheet) while VIN is absent.
A plain sync buck would conduct +5V -> L -> Q301 body diode -> VIN (~4.3 V on VIN, which would also wake the
LM51770 buck-boost at its 3.5 V UVLO and the LM5148's VOUT->VIN ESD diode would conduct too).
FIX: the buck regulates its own node 5V_BUCK; LM74700 + Q303 form an ideal diode 5V_BUCK -> +5V.
VIN absent: LM74700 unpowered (ANODE ~0 V), Q303 off, its body diode reverse-biased -> zero reverse current.
Buck running: Q303 regulated to 20 mV forward drop (0.16 W at 8 A); reverse current -> gate pulled in <0.75 us.
Nothing on this sheet ties VIN-side pins to +5V (FB, VCCX, VOUT/ISNS+, PG pull-up all on 5V_BUCK).
VIN at a few volts: EN/UVLO divider keeps the LM5148 off below 7.0-8.0 V, D301 isolates its VIN pin.
Handover: external power arrives -> buck soft-starts (3 ms) into 5V_BUCK -> diode conducts once 5V_BUCK > +5V,
+5V rises 5.0 -> 5.11 V; PG_5V (global, open drain, 100k to 5V_BUCK = 5.1 V level) goes high and, after a
2.7-6.7 ms RC on power_laptop, opens the sink switch (EXT_PWR_PRESENT AND PG_5V). Make-before-break.
PG_5V pull-up is deliberately 5V_BUCK, not +3V3/+5V: those exist while the LM5148 is unpowered (open-drain
PG floating) and would read 'good' exactly in the hand-over window. Do not feed PG_5V to 3.3 V-only inputs.
Loss of VIN: +5V held by 330 uF + ceramics.
INA226 @ 0x41 (A1=GND, A0=VS): 2 mOhm, 8 A = 16 mV of +-81.92 mV FS; CURRENT_LSB 0.5 mA -> CAL = 5120.
Measures buck output only; bus-powered +5V current is seen by the laptop-VBUS INA226 (power_laptop).
ALERT unused (firmware polls); I2C pull-ups live on the MCU sheet.
3. +3V3 TPS62933F forced-PWM (3.8-30 V in, 3 A) +5V -> 3.33 V, 1.2 MHz
dI = 3.33*(1-3.33/5.13)/(2.2u*1.2M) = 0.44 A p-p (15 % of 3 A). Cout 3x22 uF (~35 uF eff. at 3.3 V; TI table: 30 uF typ, 10 uF min).
Soft start 3.2 ms (3.9 ms worst): inside RTL8156BG 3.3 V rise 0.5-10 ms and USB7206C <= 5 ms.
EN divider 100k/39k: starts at +5V > 4.31 V (stops ~4.0 V) so a sagging bus-powered +5V cannot half-start the rail.
Load ~1.5 A typ / 2.2 A max (hub VDD33, RTL8156BG, muxes, PMG1, RP2350, LCD, SD cards): ~0.3-0.7 W loss.
4. +1V15 USB7206C VCORE (1.09-1.21 V, 1.15 V nom.) TPS62933P +5V -> 1.154 V, 1.2 MHz
USB7206C (DS00003850F): VCORE 1.09-1.21 V; ~1.31 A with all 5 ports at 10G (410 mA + 179 mA/port). 1.154 V +-1.5 % -> 1.137-1.171 V.
Sequencing (sec. 9.6.1): VCORE rises after or with VDD33 -> EN from +3V3 divider; rise times <= 5 ms -> fixed 2 ms SS.
dI = 1.15*(1-1.15/5.13)/(1.5u*1.2M) = 0.50 A p-p (17 % of 3 A, >10 % min for PCM). Cout 4x22 uF (+ hub 9x4.7 uF).
RAILS_PG (open drain, 100k to +3V3): high only when +1V15 is in regulation, which implies +3V3 is up.
GLOBAL NET (nets.py): wire-ORed onto HUB_RESET_N on usb_hub through a Schottky (hub held in reset until VCORE good).
5. RAILS NOT CREATED HERE
+1V1: not needed. RP2350 core (DVDD 1.1 V) comes from its internal switching regulator (VREG_VIN from +3V3).

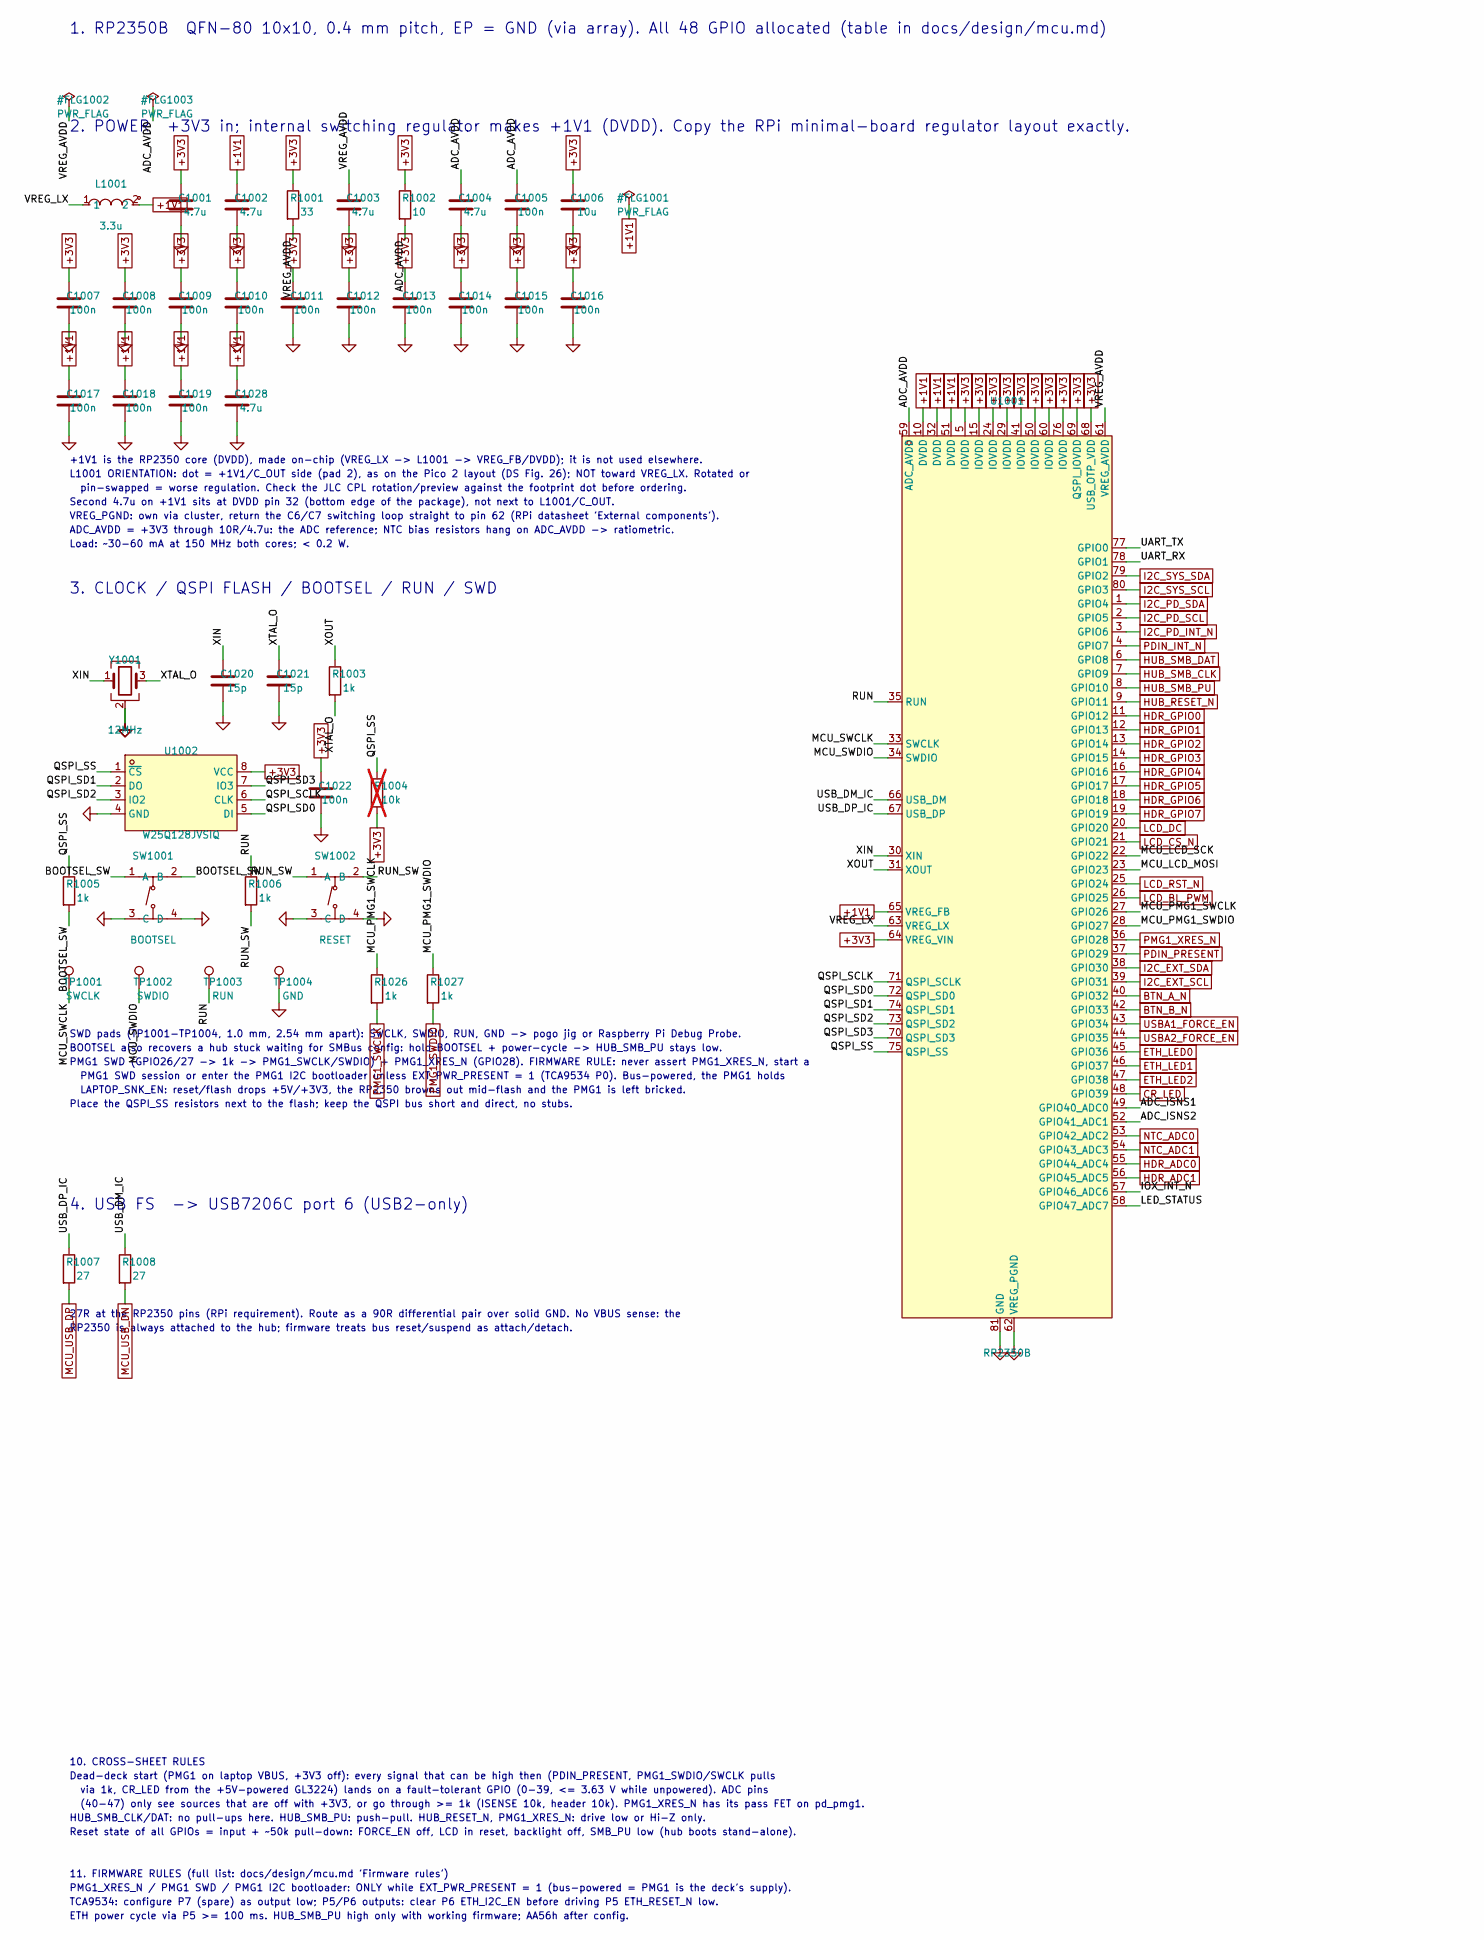
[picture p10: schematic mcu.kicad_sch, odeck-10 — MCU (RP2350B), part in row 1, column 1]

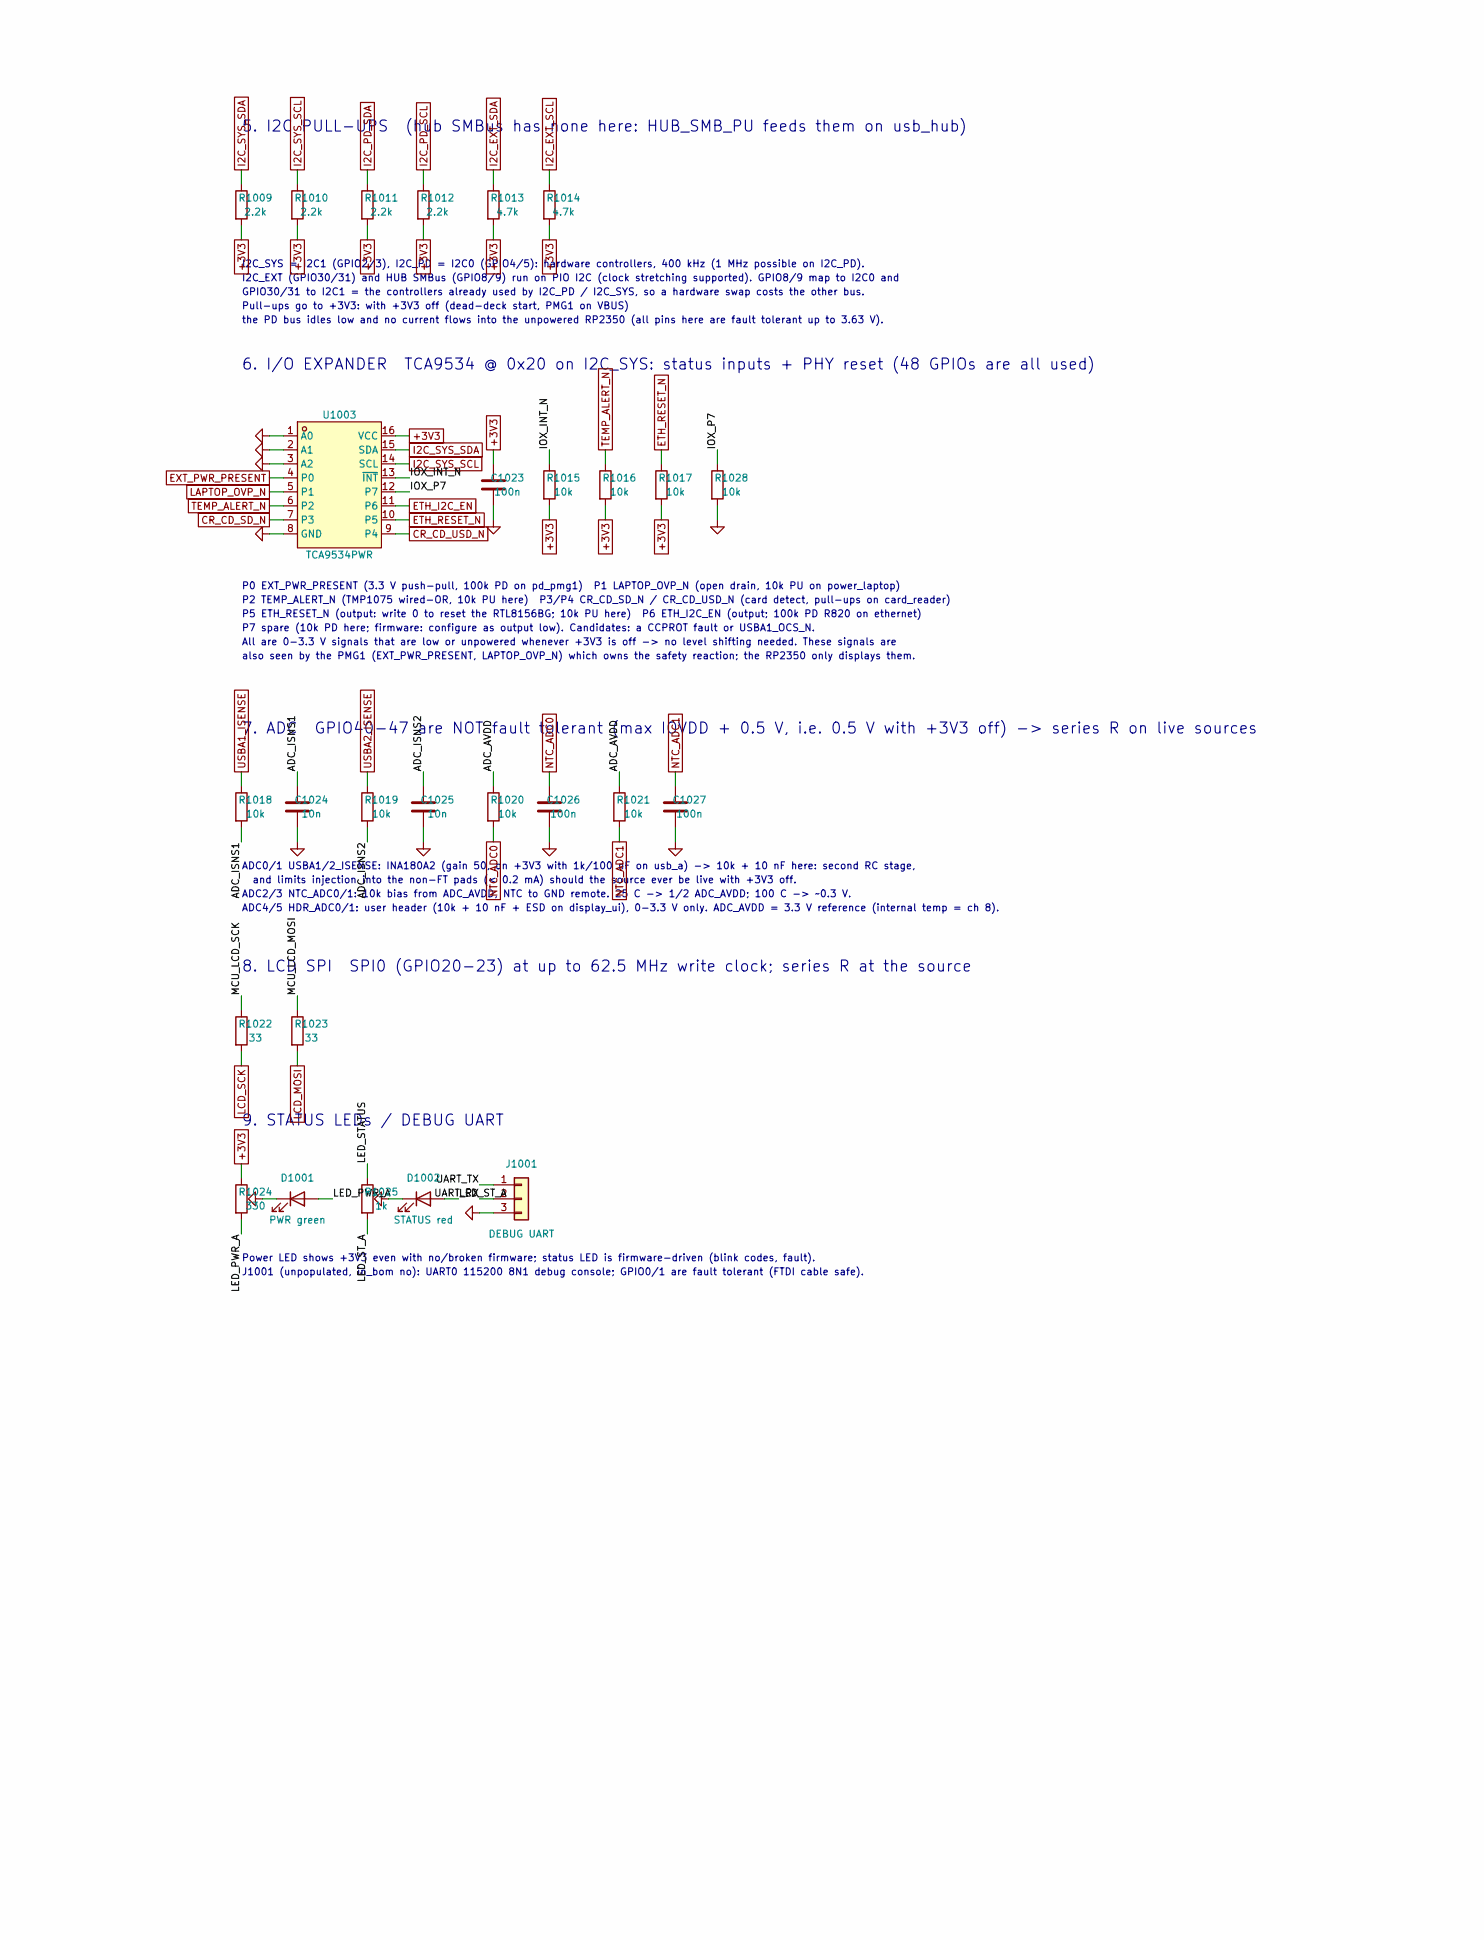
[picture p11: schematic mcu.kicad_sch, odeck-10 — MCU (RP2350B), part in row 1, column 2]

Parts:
C1001, C1002, C1003, C1004, C1028: 4.7u; C_0402_1005Metric; LCSC C23733
C1005, C1007, C1008, C1009, C1010, C1011, C1012, C1013, C1014, C1015, C1016, C1017, C1018, C1019, C1022, C1023, C1026, C1027: 100n; C_0402_1005Metric; LCSC C1525
C1006: 10u; C_0603_1608Metric; LCSC C19702
C1020, C1021: 15p; C_0402_1005Metric; LCSC C1548
C1024, C1025: 10n; C_0402_1005Metric; LCSC C15195
D1001: PWR green; LED_0805_2012Metric; LCSC C2297
D1002: STATUS red; LED_0603_1608Metric; LCSC C2286
J1001: DEBUG UART; PinHeader_1x03_P2.54mm_Vertical
L1001: 3.3u; IND-SMD_L2.0-W1.6_AOTA-B201610S3R3-101-T; MPN AOTA-B201610S3R3-101-T; LCSC C42411119
R1001, R1022, R1023: 33; R_0402_1005Metric; LCSC C25105
R1002: 10; R_0402_1005Metric; LCSC C25077
R1003, R1005, R1006, R1025, R1026, R1027: 1k; R_0402_1005Metric; LCSC C11702
R1004: 10k; R_0402_1005Metric; LCSC C25744; not fitted
R1007, R1008: 27; R_0402_1005Metric; LCSC C25100
R1009, R1010, R1011, R1012: 2.2k; R_0402_1005Metric; LCSC C25879
R1013, R1014: 4.7k; R_0402_1005Metric; LCSC C25900
R1015, R1016, R1017, R1018, R1019, R1020, R1021, R1028: 10k; R_0402_1005Metric; LCSC C25744
R1024: 330; R_0402_1005Metric; LCSC C25104
SW1001: BOOTSEL; SW-SMD_4P-L5.1-W5.1-P3.70-LS6.5-TL_H1.5; MPN TS-1187A-B-A-B; LCSC C318884
SW1002: RESET; SW-SMD_4P-L5.1-W5.1-P3.70-LS6.5-TL_H1.5; MPN TS-1187A-B-A-B; LCSC C318884
TP1001: SWCLK; TestPoint_Pad_D1.0mm
TP1002: SWDIO; TestPoint_Pad_D1.0mm
TP1003: RUN; TestPoint_Pad_D1.0mm
TP1004: GND; TestPoint_Pad_D1.0mm
U1001: RP2350B; QFN-80_L10.0-W10.0-P0.40-TL-EP3.4; MPN RP2350B; LCSC C42415655
U1002: W25Q128JVSIQ; SOIC-8_L5.3-W5.3-P1.27-LS8.0-BL; MPN W25Q128JVSIQ; LCSC C97521
U1003: TCA9534PWR; TSSOP-16_L5.0-W4.4-P0.65-LS6.4-BL; MPN TCA9534PWR; LCSC C783615
Y1001: 12MHz; Crystal_SMD_3225-4Pin_3.2x2.5mm; LCSC C20625731

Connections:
+1V1: C1002.1, C1017.1, C1018.1, C1019.1, C1028.1, L1001.2, U1001.10 (DVDD), U1001.32 (DVDD), U1001.51 (DVDD), U1001.65 (VREG_FB)
+3V3: C1001.1, C1006.1, C1007.1, C1008.1, C1009.1, C1010.1, C1011.1, C1012.1, C1013.1, C1014.1, C1015.1, C1016.1, C1022.1, C1023.1, R1001.1, R1002.1, R1004.2, R1009.2, R1010.2, R1011.2, R1012.2, R1013.2, R1014.2, R1015.2, R1016.2, R1017.2, R1024.1, U1001.5 (IOVDD), U1001.15 (IOVDD), U1001.24 (IOVDD), U1001.29 (IOVDD), U1001.41 (IOVDD), U1001.50 (IOVDD), U1001.60 (IOVDD), U1001.64 (VREG_VIN), U1001.68 (USB_OTP_VDD), U1001.69 (QSPI_IOVDD), U1001.76 (IOVDD), U1002.8 (VCC), U1003.16 (VCC); also elsewhere on the board
/MCU/ADC_AVDD: C1004.1, C1005.1, R1002.2, R1020.1, R1021.1, U1001.59 (ADC_AVDD)
/MCU/ADC_ISNS1: C1024.1, R1018.2, U1001.49 (GPIO40_ADC0)
/MCU/ADC_ISNS2: C1025.1, R1019.2, U1001.52 (GPIO41_ADC1)
/MCU/BOOTSEL_SW: R1005.2, SW1001.1 (A), SW1001.2 (B)
/MCU/IOX_INT_N: R1015.1, U1001.57 (GPIO46_ADC6), U1003.13 (~INT)
/MCU/IOX_P7: R1028.1, U1003.12 (P7)
/MCU/LED_PWR_A: D1001.2 (A), R1024.2
/MCU/LED_STATUS: R1025.1, U1001.58 (GPIO47_ADC7)
/MCU/LED_ST_A: D1002.2 (A), R1025.2
/MCU/MCU_LCD_MOSI: R1023.1, U1001.23 (GPIO23)
/MCU/MCU_LCD_SCK: R1022.1, U1001.22 (GPIO22)
/MCU/MCU_PMG1_SWCLK: R1026.1, U1001.27 (GPIO26)
/MCU/MCU_PMG1_SWDIO: R1027.1, U1001.28 (GPIO27)
/MCU/MCU_SWCLK: TP1001.1, U1001.33 (SWCLK)
/MCU/MCU_SWDIO: TP1002.1, U1001.34 (SWDIO)
/MCU/QSPI_SCLK: U1001.71 (QSPI_SCLK), U1002.6 (CLK)
/MCU/QSPI_SD0: U1001.72 (QSPI_SD0), U1002.5 (DI)
/MCU/QSPI_SD1: U1001.74 (QSPI_SD1), U1002.2 (DO)
/MCU/QSPI_SD2: U1001.73 (QSPI_SD2), U1002.3 (IO2)
/MCU/QSPI_SD3: U1001.70 (QSPI_SD3), U1002.7 (IO3)
/MCU/QSPI_SS: R1004.1, R1005.1, U1001.75 (QSPI_SS), U1002.1 (~CS)
/MCU/RUN: R1006.1, TP1003.1, U1001.35 (RUN)
/MCU/RUN_SW: R1006.2, SW1002.1 (A), SW1002.2 (B)
/MCU/UART_RX: J1001.2, U1001.78 (GPIO1)
/MCU/UART_TX: J1001.1, U1001.77 (GPIO0)
/MCU/USB_DM_IC: R1008.1, U1001.66 (USB_DM)
/MCU/USB_DP_IC: R1007.1, U1001.67 (USB_DP)
/MCU/VREG_AVDD: C1003.1, R1001.2, U1001.61 (VREG_AVDD)
/MCU/VREG_LX: L1001.1, U1001.63 (VREG_LX)
/MCU/XIN: C1020.1, U1001.30 (XIN), Y1001.1
/MCU/XOUT: R1003.1, U1001.31 (XOUT)
/MCU/XTAL_O: C1021.1, R1003.2, Y1001.3
BTN_A_N: U1001.40 (GPIO32); also elsewhere on the board
BTN_B_N: U1001.42 (GPIO33); also elsewhere on the board
CR_CD_SD_N: U1003.7 (P3); also elsewhere on the board
CR_CD_USD_N: U1003.9 (P4); also elsewhere on the board
CR_LED: U1001.48 (GPIO39); also elsewhere on the board
ETH_I2C_EN: U1003.11 (P6); also elsewhere on the board
ETH_LED0: U1001.45 (GPIO36); also elsewhere on the board
ETH_LED1: U1001.46 (GPIO37); also elsewhere on the board
ETH_LED2: U1001.47 (GPIO38); also elsewhere on the board
ETH_RESET_N: R1017.1, U1003.10 (P5); also elsewhere on the board
EXT_PWR_PRESENT: U1003.4 (P0); also elsewhere on the board
GND: C1001.2, C1002.2, C1003.2, C1004.2, C1005.2, C1006.2, C1007.2, C1008.2, C1009.2, C1010.2, C1011.2, C1012.2, C1013.2, C1014.2, C1015.2, C1016.2, C1017.2, C1018.2, C1019.2, C1020.2, C1021.2, C1022.2, C1023.2, C1024.2, C1025.2, C1026.2, C1027.2, C1028.2, D1001.1 (K), D1002.1 (K), J1001.3, R1028.2, SW1001.3 (C), SW1001.4 (D), SW1002.3 (C), SW1002.4 (D), TP1004.1, U1001.62 (VREG_PGND), U1001.81 (GND), U1002.4 (GND), U1003.1 (A0), U1003.2 (A1), U1003.3 (A2), U1003.8 (GND), Y1001.2 (G), Y1001.4 (G); also elsewhere on the board
HDR_ADC0: U1001.55 (GPIO44_ADC4); also elsewhere on the board
HDR_ADC1: U1001.56 (GPIO45_ADC5); also elsewhere on the board
HDR_GPIO0: U1001.11 (GPIO12); also elsewhere on the board
HDR_GPIO1: U1001.12 (GPIO13); also elsewhere on the board
HDR_GPIO2: U1001.13 (GPIO14); also elsewhere on the board
HDR_GPIO3: U1001.14 (GPIO15); also elsewhere on the board
HDR_GPIO4: U1001.16 (GPIO16); also elsewhere on the board
HDR_GPIO5: U1001.17 (GPIO17); also elsewhere on the board
HDR_GPIO6: U1001.18 (GPIO18); also elsewhere on the board
HDR_GPIO7: U1001.19 (GPIO19); also elsewhere on the board
HUB_RESET_N: U1001.9 (GPIO11); also elsewhere on the board
HUB_SMB_CLK: U1001.7 (GPIO9); also elsewhere on the board
HUB_SMB_DAT: U1001.6 (GPIO8); also elsewhere on the board
HUB_SMB_PU: U1001.8 (GPIO10); also elsewhere on the board
I2C_EXT_SCL: R1014.1, U1001.39 (GPIO31); also elsewhere on the board
I2C_EXT_SDA: R1013.1, U1001.38 (GPIO30); also elsewhere on the board
I2C_PD_INT_N: U1001.3 (GPIO6); also elsewhere on the board
I2C_PD_SCL: R1012.1, U1001.2 (GPIO5); also elsewhere on the board
I2C_PD_SDA: R1011.1, U1001.1 (GPIO4); also elsewhere on the board
I2C_SYS_SCL: R1010.1, U1001.80 (GPIO3), U1003.14 (SCL); also elsewhere on the board
I2C_SYS_SDA: R1009.1, U1001.79 (GPIO2), U1003.15 (SDA); also elsewhere on the board
LAPTOP_OVP_N: U1003.5 (P1); also elsewhere on the board
LCD_BL_PWM: U1001.26 (GPIO25); also elsewhere on the board
LCD_CS_N: U1001.21 (GPIO21); also elsewhere on the board
LCD_DC: U1001.20 (GPIO20); also elsewhere on the board
LCD_MOSI: R1023.2; also elsewhere on the board
LCD_RST_N: U1001.25 (GPIO24); also elsewhere on the board
LCD_SCK: R1022.2; also elsewhere on the board
MCU_USB_DN: R1008.2; also elsewhere on the board
MCU_USB_DP: R1007.2; also elsewhere on the board
NTC_ADC0: C1026.1, R1020.2, U1001.53 (GPIO42_ADC2); also elsewhere on the board
NTC_ADC1: C1027.1, R1021.2, U1001.54 (GPIO43_ADC3); also elsewhere on the board
PDIN_INT_N: U1001.4 (GPIO7); also elsewhere on the board
PDIN_PRESENT: U1001.37 (GPIO29); also elsewhere on the board
PMG1_SWCLK: R1026.2; also elsewhere on the board
PMG1_SWDIO: R1027.2; also elsewhere on the board
PMG1_XRES_N: U1001.36 (GPIO28); also elsewhere on the board
TEMP_ALERT_N: R1016.1, U1003.6 (P2); also elsewhere on the board
USBA1_FORCE_EN: U1001.43 (GPIO34); also elsewhere on the board
USBA1_ISENSE: R1018.1; also elsewhere on the board
USBA2_FORCE_EN: U1001.44 (GPIO35); also elsewhere on the board
USBA2_ISENSE: R1019.1; also elsewhere on the board

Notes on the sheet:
1. RP2350B QFN-80 10x10, 0.4 mm pitch, EP = GND (via array). All 48 GPIO allocated (table in docs/design/mcu.md)
2. POWER +3V3 in; internal switching regulator makes +1V1 (DVDD). Copy the RPi minimal-board regulator layout exactly.
+1V1 is the RP2350 core (DVDD), made on-chip (VREG_LX -> L1001 -> VREG_FB/DVDD); it is not used elsewhere.
L1001 ORIENTATION: dot = +1V1/C_OUT side (pad 2), as on the Pico 2 layout (DS Fig. 26); NOT toward VREG_LX. Rotated or
pin-swapped = worse regulation. Check the JLC CPL rotation/preview against the footprint dot before ordering.
Second 4.7u on +1V1 sits at DVDD pin 32 (bottom edge of the package), not next to L1001/C_OUT.
VREG_PGND: own via cluster, return the C6/C7 switching loop straight to pin 62 (RPi datasheet 'External components').
ADC_AVDD = +3V3 through 10R/4.7u: the ADC reference; NTC bias resistors hang on ADC_AVDD -> ratiometric.
Load: ~30-60 mA at 150 MHz both cores; < 0.2 W.
3. CLOCK / QSPI FLASH / BOOTSEL / RUN / SWD
SWD pads (TP1001-TP1004, 1.0 mm, 2.54 mm apart): SWCLK, SWDIO, RUN, GND -> pogo jig or Raspberry Pi Debug Probe.
BOOTSEL also recovers a hub stuck waiting for SMBus config: hold BOOTSEL + power-cycle -> HUB_SMB_PU stays low.
PMG1 SWD (GPIO26/27 -> 1k -> PMG1_SWCLK/SWDIO) + PMG1_XRES_N (GPIO28). FIRMWARE RULE: never assert PMG1_XRES_N, start a
PMG1 SWD session or enter the PMG1 I2C bootloader unless EXT_PWR_PRESENT = 1 (TCA9534 P0). Bus-powered, the PMG1 holds
LAPTOP_SNK_EN: reset/flash drops +5V/+3V3, the RP2350 browns out mid-flash and the PMG1 is left bricked.
Place the QSPI_SS resistors next to the flash; keep the QSPI bus short and direct, no stubs.
4. USB FS -> USB7206C port 6 (USB2-only)
27R at the RP2350 pins (RPi requirement). Route as a 90R differential pair over solid GND. No VBUS sense: the
RP2350 is always attached to the hub; firmware treats bus reset/suspend as attach/detach.
5. I2C PULL-UPS (hub SMBus has none here: HUB_SMB_PU feeds them on usb_hub)
I2C_SYS = I2C1 (GPIO2/3), I2C_PD = I2C0 (GPIO4/5): hardware controllers, 400 kHz (1 MHz possible on I2C_PD).
I2C_EXT (GPIO30/31) and HUB SMBus (GPIO8/9) run on PIO I2C (clock stretching supported). GPIO8/9 map to I2C0 and
GPIO30/31 to I2C1 = the controllers already used by I2C_PD / I2C_SYS, so a hardware swap costs the other bus.
Pull-ups go to +3V3: with +3V3 off (dead-deck start, PMG1 on VBUS)
the PD bus idles low and no current flows into the unpowered RP2350 (all pins here are fault tolerant up to 3.63 V).
6. I/O EXPANDER TCA9534 @ 0x20 on I2C_SYS: status inputs + PHY reset (48 GPIOs are all used)
P0 EXT_PWR_PRESENT (3.3 V push-pull, 100k PD on pd_pmg1) P1 LAPTOP_OVP_N (open drain, 10k PU on power_laptop)
P2 TEMP_ALERT_N (TMP1075 wired-OR, 10k PU here) P3/P4 CR_CD_SD_N / CR_CD_USD_N (card detect, pull-ups on card_reader)
P5 ETH_RESET_N (output: write 0 to reset the RTL8156BG; 10k PU here) P6 ETH_I2C_EN (output; 100k PD R820 on ethernet)
P7 spare (10k PD here; firmware: configure as output low). Candidates: a CCPROT fault or USBA1_OCS_N.
All are 0-3.3 V signals that are low or unpowered whenever +3V3 is off -> no level shifting needed. These signals are
also seen by the PMG1 (EXT_PWR_PRESENT, LAPTOP_OVP_N) which owns the safety reaction; the RP2350 only displays them.
7. ADC GPIO40-47 are NOT fault tolerant (max IOVDD + 0.5 V, i.e. 0.5 V with +3V3 off) -> series R on live sources
ADC0/1 USBA1/2_ISENSE: INA180A2 (gain 50, on +3V3 with 1k/100 nF on usb_a) -> 10k + 10 nF here: second RC stage,
and limits injection into the non-FT pads (< 0.2 mA) should the source ever be live with +3V3 off.
ADC2/3 NTC_ADC0/1: 10k bias from ADC_AVDD, NTC to GND remote. 25 C -> 1/2 ADC_AVDD; 100 C -> ~0.3 V.
ADC4/5 HDR_ADC0/1: user header (10k + 10 nF + ESD on display_ui), 0-3.3 V only. ADC_AVDD = 3.3 V reference (internal temp = ch 8).
8. LCD SPI SPI0 (GPIO20-23) at up to 62.5 MHz write clock; series R at the source
9. STATUS LEDs / DEBUG UART
Power LED shows +3V3 even with no/broken firmware; status LED is firmware-driven (blink codes, fault).

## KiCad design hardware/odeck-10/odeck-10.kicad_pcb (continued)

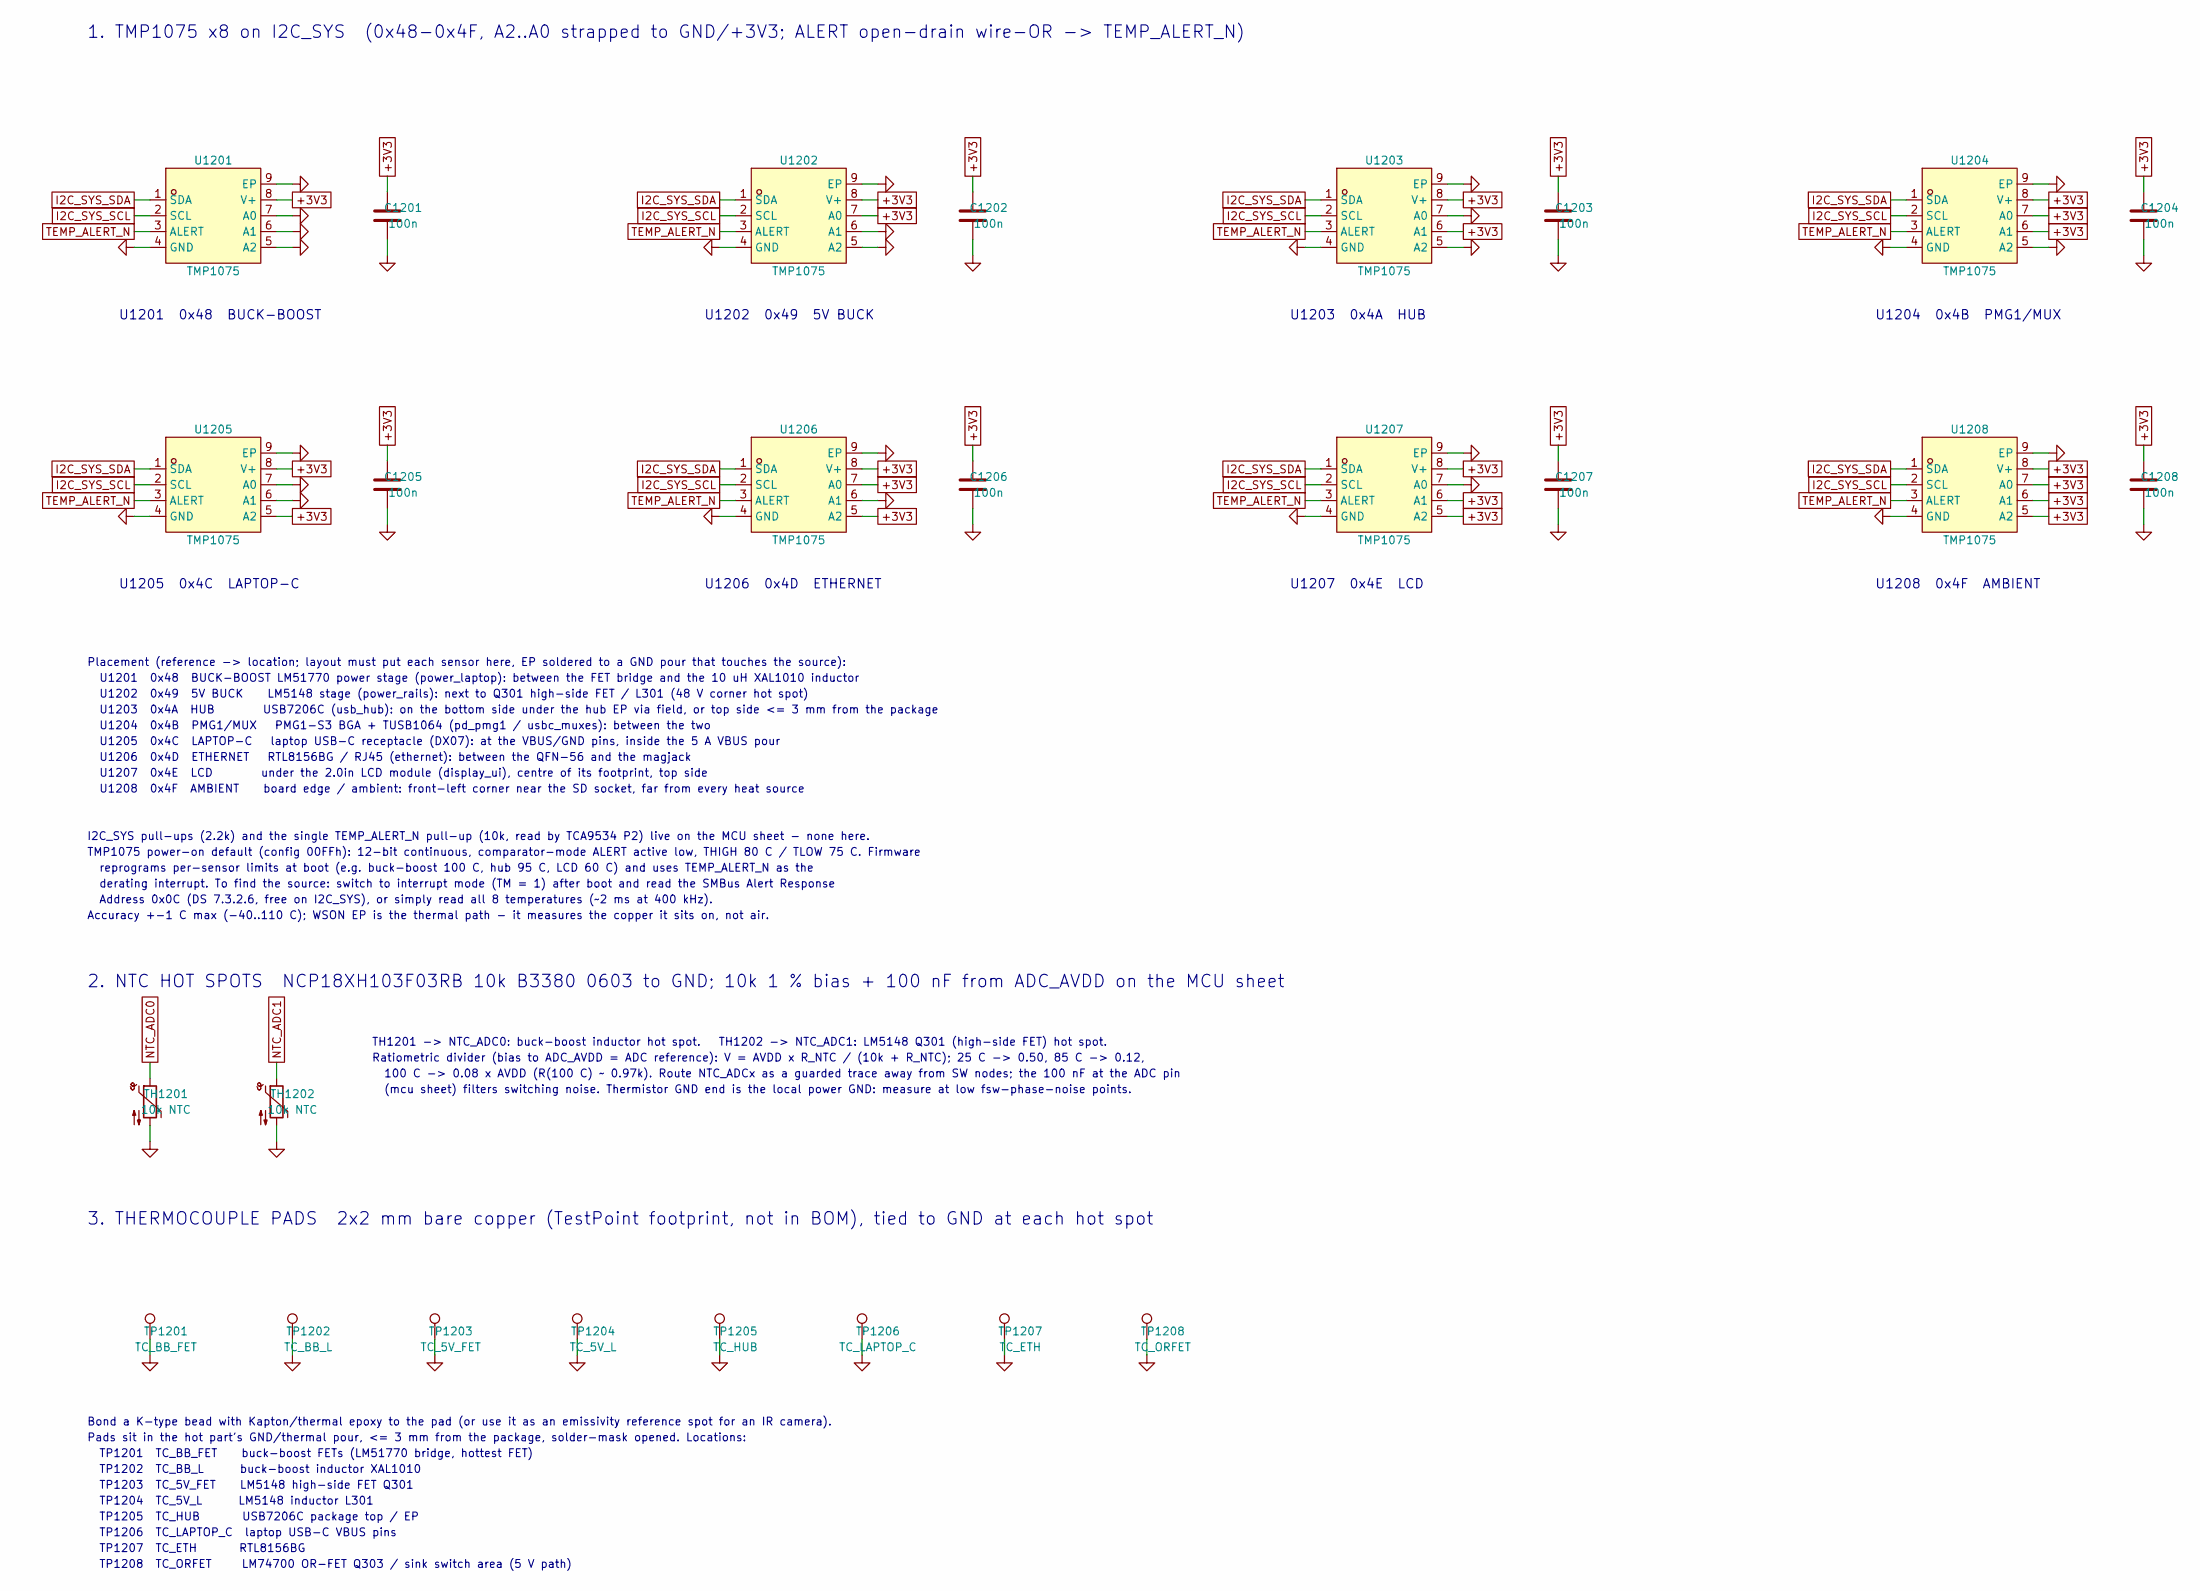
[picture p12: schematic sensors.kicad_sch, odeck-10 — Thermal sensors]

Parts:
C1201, C1202, C1203, C1204, C1205, C1206, C1207, C1208: 100n; C_0402_1005Metric; LCSC C1525
TH1201, TH1202: 10k NTC; R_0603_1608Metric; LCSC C13564
TP1201: TC_BB_FET; TestPoint_Pad_2.0x2.0mm
TP1202: TC_BB_L; TestPoint_Pad_2.0x2.0mm
TP1203: TC_5V_FET; TestPoint_Pad_2.0x2.0mm
TP1204: TC_5V_L; TestPoint_Pad_2.0x2.0mm
TP1205: TC_HUB; TestPoint_Pad_2.0x2.0mm
TP1206: TC_LAPTOP_C; TestPoint_Pad_2.0x2.0mm
TP1207: TC_ETH; TestPoint_Pad_2.0x2.0mm
TP1208: TC_ORFET; TestPoint_Pad_2.0x2.0mm
U1201, U1202, U1203, U1204, U1205, U1206, U1207, U1208: TMP1075; WSON-8_L2.0-W2.0-P0.50-TL-EP; MPN TMP1075DSGR; LCSC C2870250

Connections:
+3V3: C1201.1, C1202.1, C1203.1, C1204.1, C1205.1, C1206.1, C1207.1, C1208.1, U1201.8 (V+), U1202.7 (A0), U1202.8 (V+), U1203.6 (A1), U1203.8 (V+), U1204.6 (A1), U1204.7 (A0), U1204.8 (V+), U1205.5 (A2), U1205.8 (V+), U1206.5 (A2), U1206.7 (A0), U1206.8 (V+), U1207.5 (A2), U1207.6 (A1), U1207.8 (V+), U1208.5 (A2), U1208.6 (A1), U1208.7 (A0), U1208.8 (V+); also elsewhere on the board
GND: C1201.2, C1202.2, C1203.2, C1204.2, C1205.2, C1206.2, C1207.2, C1208.2, TH1201.2, TH1202.2, TP1201.1, TP1202.1, TP1203.1, TP1204.1, TP1205.1, TP1206.1, TP1207.1, TP1208.1, U1201.4 (GND), U1201.5 (A2), U1201.6 (A1), U1201.7 (A0), U1201.9 (EP), U1202.4 (GND), U1202.5 (A2), U1202.6 (A1), U1202.9 (EP), U1203.4 (GND), U1203.5 (A2), U1203.7 (A0), U1203.9 (EP), U1204.4 (GND), U1204.5 (A2), U1204.9 (EP), U1205.4 (GND), U1205.6 (A1), U1205.7 (A0), U1205.9 (EP), U1206.4 (GND), U1206.6 (A1), U1206.9 (EP), U1207.4 (GND), U1207.7 (A0), U1207.9 (EP), U1208.4 (GND), U1208.9 (EP); also elsewhere on the board
I2C_SYS_SCL: U1201.2 (SCL), U1202.2 (SCL), U1203.2 (SCL), U1204.2 (SCL), U1205.2 (SCL), U1206.2 (SCL), U1207.2 (SCL), U1208.2 (SCL); also elsewhere on the board
I2C_SYS_SDA: U1201.1 (SDA), U1202.1 (SDA), U1203.1 (SDA), U1204.1 (SDA), U1205.1 (SDA), U1206.1 (SDA), U1207.1 (SDA), U1208.1 (SDA); also elsewhere on the board
NTC_ADC0: TH1201.1; also elsewhere on the board
NTC_ADC1: TH1202.1; also elsewhere on the board
TEMP_ALERT_N: U1201.3 (ALERT), U1202.3 (ALERT), U1203.3 (ALERT), U1204.3 (ALERT), U1205.3 (ALERT), U1206.3 (ALERT), U1207.3 (ALERT), U1208.3 (ALERT); also elsewhere on the board

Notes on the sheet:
1. TMP1075 x8 on I2C_SYS (0x48-0x4F, A2..A0 strapped to GND/+3V3; ALERT open-drain wire-OR -> TEMP_ALERT_N)
U1201 0x48 BUCK-BOOST
U1202 0x49 5V BUCK
U1203 0x4A HUB
U1204 0x4B PMG1/MUX
U1205 0x4C LAPTOP-C
U1206 0x4D ETHERNET
U1207 0x4E LCD
U1208 0x4F AMBIENT
Placement (reference -> location; layout must put each sensor here, EP soldered to a GND pour that touches the source):
U1201 0x48 BUCK-BOOST LM51770 power stage (power_laptop): between the FET bridge and the 10 uH XAL1010 inductor
U1202 0x49 5V BUCK LM5148 stage (power_rails): next to Q301 high-side FET / L301 (48 V corner hot spot)
U1203 0x4A HUB USB7206C (usb_hub): on the bottom side under the hub EP via field, or top side <= 3 mm from the package
U1204 0x4B PMG1/MUX PMG1-S3 BGA + TUSB1064 (pd_pmg1 / usbc_muxes): between the two
U1205 0x4C LAPTOP-C laptop USB-C receptacle (DX07): at the VBUS/GND pins, inside the 5 A VBUS pour
U1206 0x4D ETHERNET RTL8156BG / RJ45 (ethernet): between the QFN-56 and the magjack
U1207 0x4E LCD under the 2.0in LCD module (display_ui), centre of its footprint, top side
U1208 0x4F AMBIENT board edge / ambient: front-left corner near the SD socket, far from every heat source
I2C_SYS pull-ups (2.2k) and the single TEMP_ALERT_N pull-up (10k, read by TCA9534 P2) live on the MCU sheet - none here.
TMP1075 power-on default (config 00FFh): 12-bit continuous, comparator-mode ALERT active low, THIGH 80 C / TLOW 75 C. Firmware
reprograms per-sensor limits at boot (e.g. buck-boost 100 C, hub 95 C, LCD 60 C) and uses TEMP_ALERT_N as the
derating interrupt. To find the source: switch to interrupt mode (TM = 1) after boot and read the SMBus Alert Response
Address 0x0C (DS 7.3.2.6, free on I2C_SYS), or simply read all 8 temperatures (~2 ms at 400 kHz).
Accuracy +-1 C max (-40..110 C); WSON EP is the thermal path - it measures the copper it sits on, not air.
2. NTC HOT SPOTS NCP18XH103F03RB 10k B3380 0603 to GND; 10k 1 % bias + 100 nF from ADC_AVDD on the MCU sheet
TH1201 -> NTC_ADC0: buck-boost inductor hot spot. TH1202 -> NTC_ADC1: LM5148 Q301 (high-side FET) hot spot.
Ratiometric divider (bias to ADC_AVDD = ADC reference): V = AVDD x R_NTC / (10k + R_NTC); 25 C -> 0.50, 85 C -> 0.12,
100 C -> 0.08 x AVDD (R(100 C) ~ 0.97k). Route NTC_ADCx as a guarded trace away from SW nodes; the 100 nF at the ADC pin
(mcu sheet) filters switching noise. Thermistor GND end is the local power GND: measure at low fsw-phase-noise points.
3. THERMOCOUPLE PADS 2x2 mm bare copper (TestPoint footprint, not in BOM), tied to GND at each hot spot
Bond a K-type bead with Kapton/thermal epoxy to the pad (or use it as an emissivity reference spot for an IR camera).
Pads sit in the hot part's GND/thermal pour, <= 3 mm from the package, solder-mask opened. Locations:
TP1201 TC_BB_FET buck-boost FETs (LM51770 bridge, hottest FET)
TP1202 TC_BB_L buck-boost inductor XAL1010
TP1203 TC_5V_FET LM5148 high-side FET Q301
TP1204 TC_5V_L LM5148 inductor L301
TP1205 TC_HUB USB7206C package top / EP
TP1206 TC_LAPTOP_C laptop USB-C VBUS pins
TP1207 TC_ETH RTL8156BG
TP1208 TC_ORFET LM74700 OR-FET Q303 / sink switch area (5 V path)

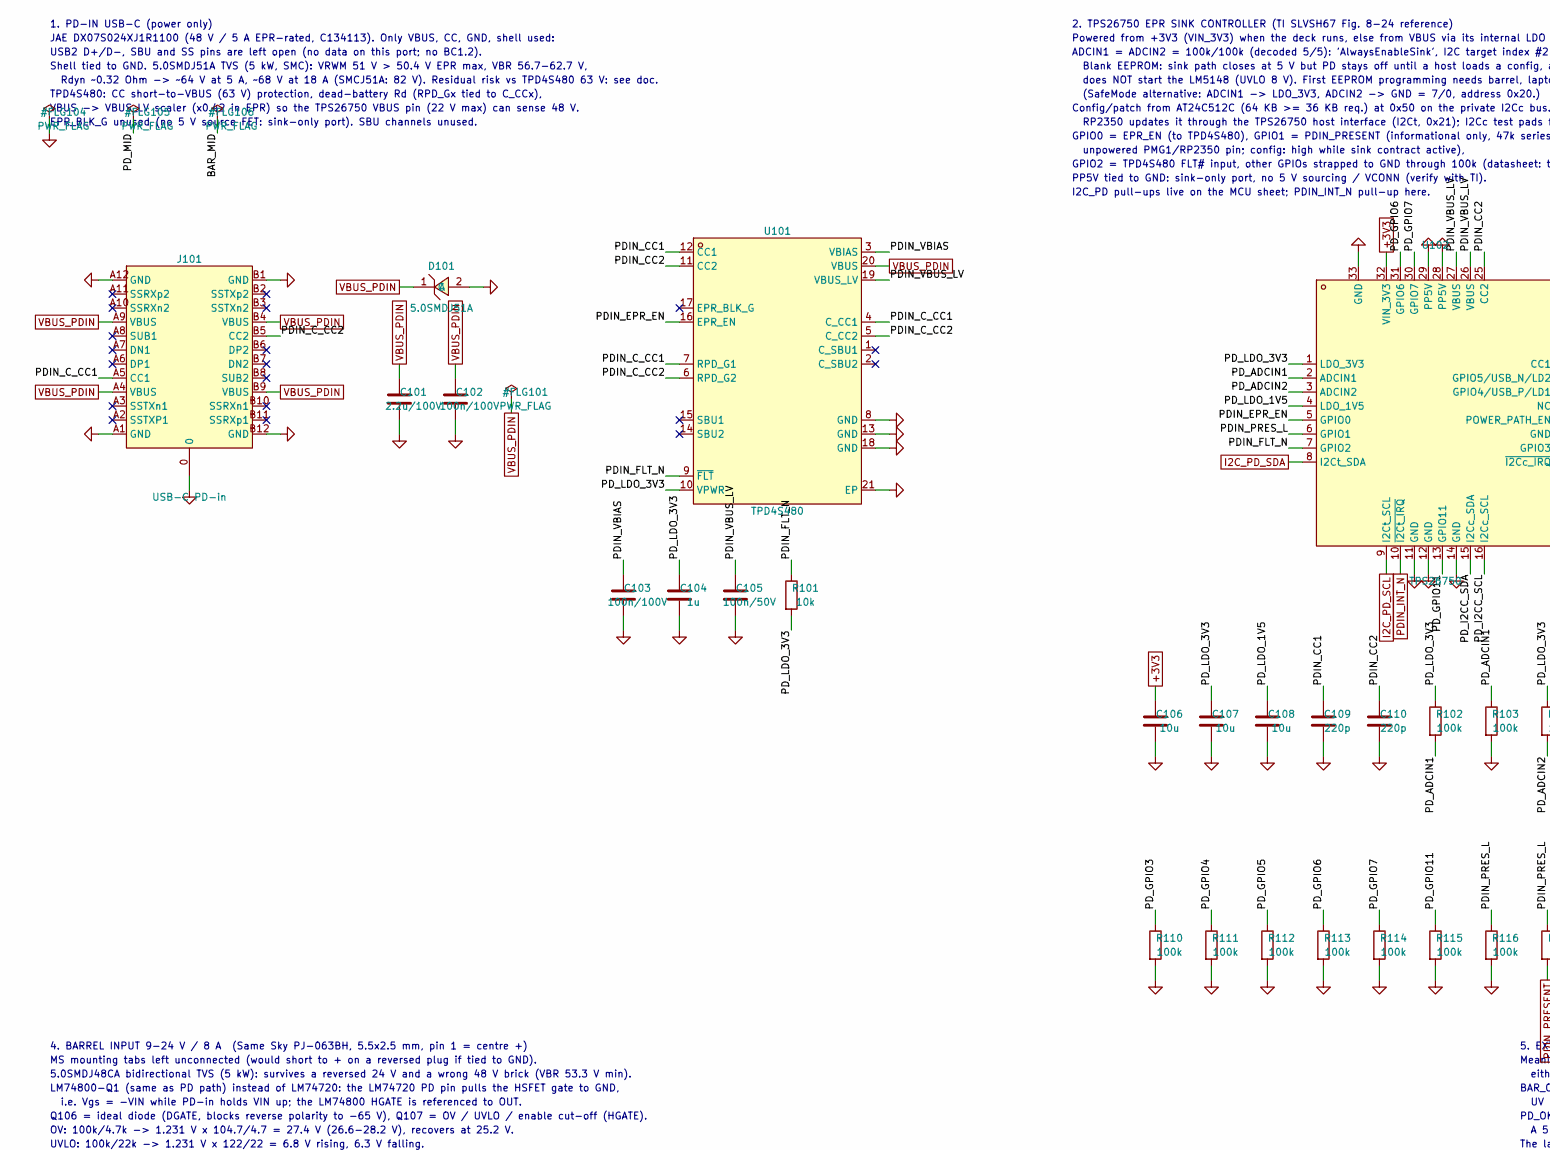
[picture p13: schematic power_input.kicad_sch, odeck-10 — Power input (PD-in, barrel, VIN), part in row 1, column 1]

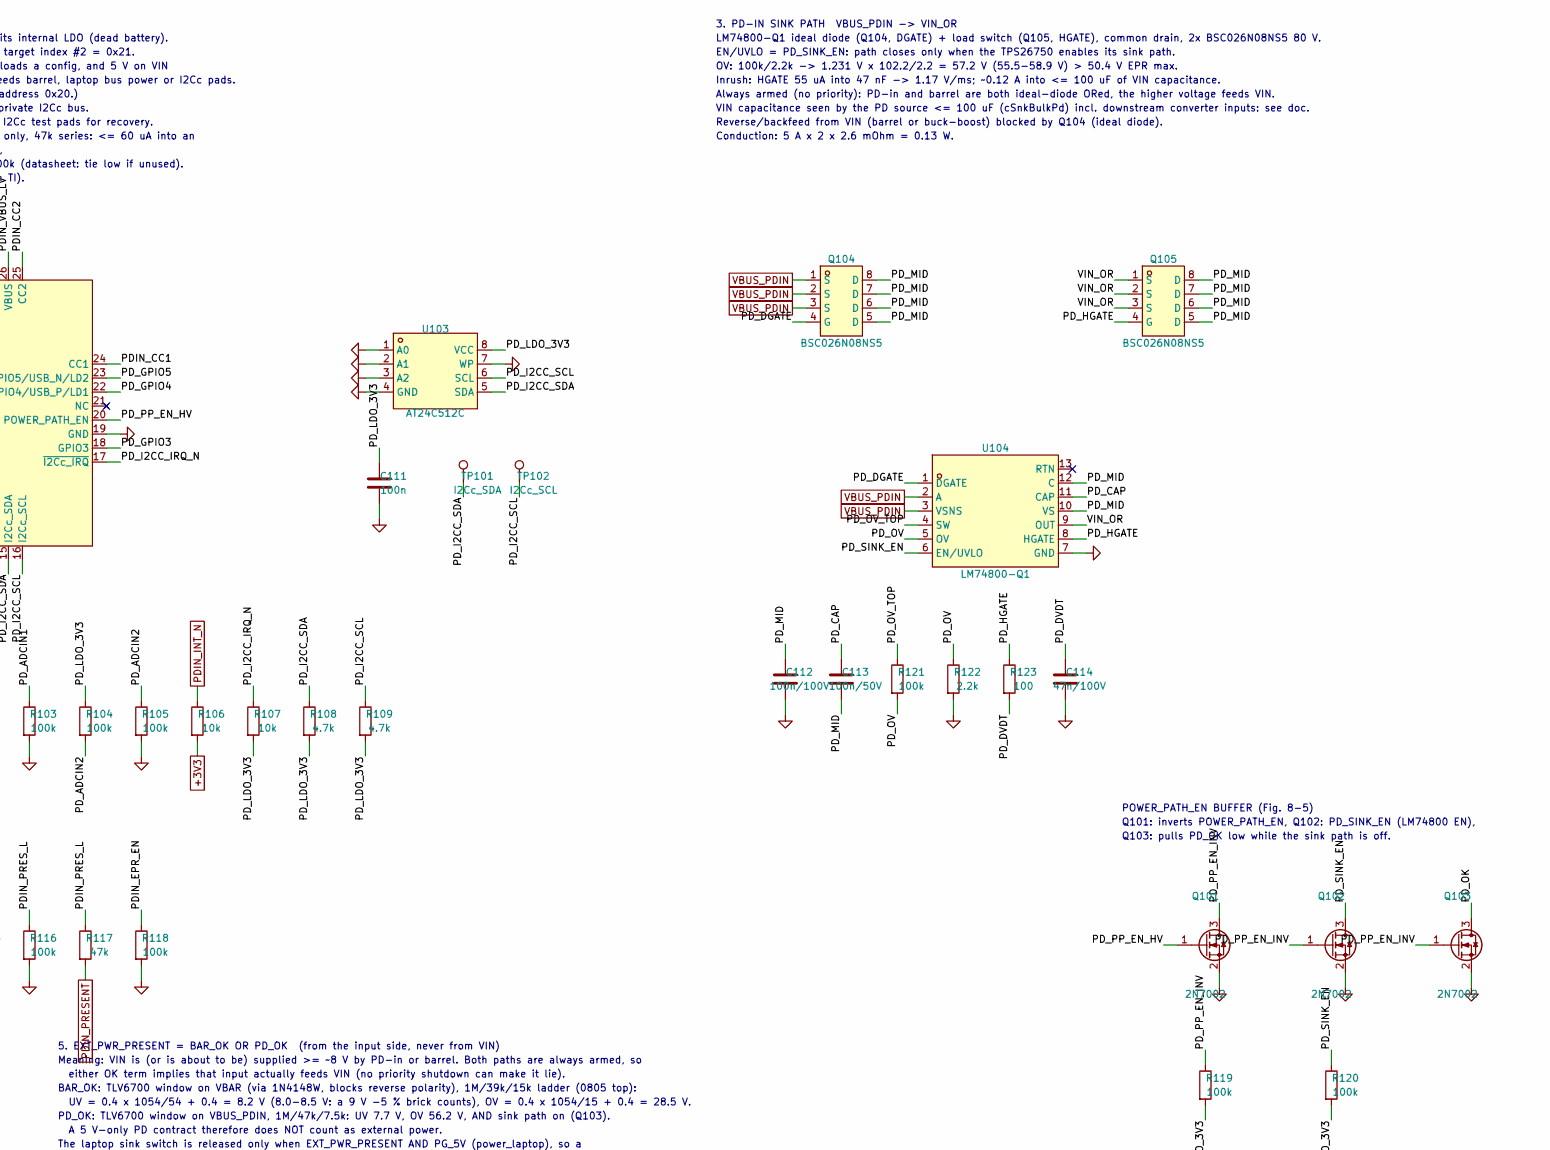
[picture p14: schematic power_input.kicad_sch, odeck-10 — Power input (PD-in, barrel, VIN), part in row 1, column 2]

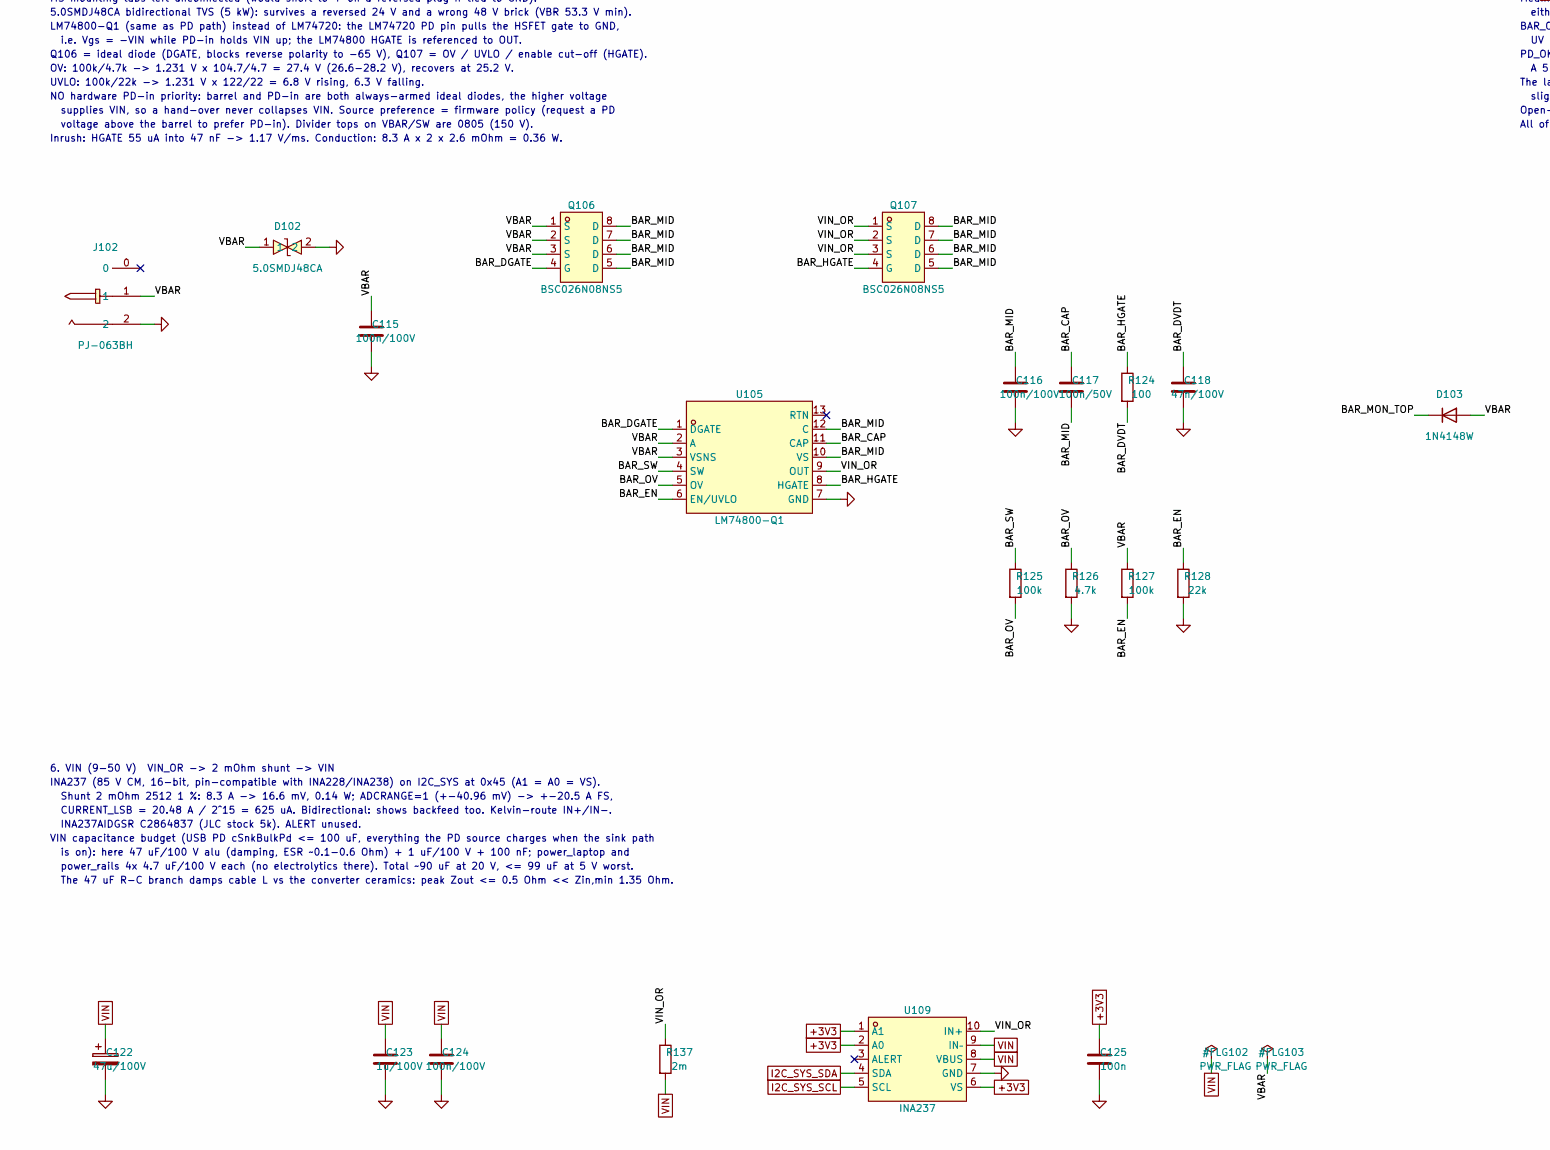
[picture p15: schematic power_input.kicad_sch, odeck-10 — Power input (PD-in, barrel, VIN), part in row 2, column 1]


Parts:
C101: 2.2u/100V; C_1210_3225Metric; LCSC C153036
C102, C103, C112, C115, C116, C124: 100n/100V; C_0805_2012Metric; LCSC C28233
C104: 1u; C_0402_1005Metric; LCSC C52923
C105, C113, C117: 100n/50V; C_0603_1608Metric; LCSC C14663
C106, C107, C108: 10u; C_0603_1608Metric; LCSC C19702
C109, C110: 220p; C_0603_1608Metric; LCSC C1603
C111, C119, C120, C121, C125: 100n; C_0402_1005Metric; LCSC C1525
C114, C118: 47n/100V; C_0603_1608Metric; LCSC C576852
C122: 47u/100V; CP_Elec_10x10; LCSC C371305
C123: 1u/100V; C_0805_2012Metric; LCSC C126585
D101: 5.0SMDJ51A; SMC_L6.9-W5.9-LS7.9-RD; MPN 5.0SMDJ51A; LCSC C2990373
D102: 5.0SMDJ48CA; SMC_L6.9-W5.9-LS7.9-BI; MPN 5.0SMDJ48CA; LCSC C2649886
D103: 1N4148W; D_SOD-123; LCSC C81598
J101: USB-C PD-in; USB-C-TH_DX07S024XJ1R1100-1; MPN DX07S024XJ1R1100; LCSC C134113
J102: PJ-063BH; DC-IN_PJ-063BH; MPN PJ-063BH; LCSC C3095900
Q101, Q102, Q103: 2N7002; SOT-23; LCSC C8545
Q104, Q105, Q106, Q107: BSC026N08NS5; PG-TDSON-8_L5.0-W6.0-P1.27-BL-EP; MPN BSC026N08NS5ATMA1; LCSC C5955453
R101, R106, R107: 10k; R_0402_1005Metric; LCSC C25744
R102, R103, R104, R105, R110, R111, R112, R113, R114, R115, R116, R118, R119, R120, R132, R136: 100k; R_0402_1005Metric; LCSC C25741
R108, R109, R126: 4.7k; R_0402_1005Metric; LCSC C25900
R117, R134: 47k; R_0402_1005Metric; LCSC C25792
R121, R125, R127: 100k; R_0805_2012Metric; LCSC C149504
R122: 2.2k; R_0402_1005Metric; LCSC C25879
R123, R124: 100; R_0402_1005Metric; LCSC C25076
R128: 22k; R_0402_1005Metric; LCSC C25768
R129, R133: 1M; R_0805_2012Metric; LCSC C17514
R130: 39k; R_0603_1608Metric; LCSC C23153
R131: 15k; R_0402_1005Metric; LCSC C25756
R135: 7.5k; R_0603_1608Metric; LCSC C23234
R137: 2m; R_2512_6332Metric; MPN RLP25FEGR002; LCSC C459679
TP101: I2Cc_SDA; TestPoint_Pad_D1.0mm
TP102: I2Cc_SCL; TestPoint_Pad_D1.0mm
U101: TPD4S480; WQFN-20_L3.0-W3.0-P0.40-BL-EP1.7; MPN TPD4S480RUKR; LCSC C43131250
U102: TPS26750; QFN-32_L4.0-W4.0-P0.40-BL-EP2.8; MPN TPS26750SRSMR; LCSC C42166327
U103: AT24C512C; SOIC-8_L4.9-W3.9-P1.27-LS6.0-BL; MPN AT24C512C-SSHD-T; LCSC C12371
U104, U105: LM74800-Q1; WSON-12_L3.0-W3.0-P0.50-TL-EP-2; MPN LM74800QDRRRQ1; LCSC C3215600
U106, U107: TLV6700; TSOT-23-6_L2.9-W1.6-P0.95-LS2.8-BR; MPN TLV6700DDCR; LCSC C2868382
U108: SN74LVC1G32; SOT-23-5; LCSC C10096
U109: INA237; VSSOP-10_L3.0-W3.0-P0.50-LS4.9-BL; MPN INA237AIDGSR; LCSC C2864837

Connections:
+3V3: C106.1, C119.1, C120.1, C121.1, C125.1, R106.2, R132.2, R136.2, U102.32 (VIN_3V3), U106.5 (VDD), U107.5 (VDD), U108.5 (VCC), U109.1 (A1), U109.2 (A0), U109.6 (VS); also elsewhere on the board
/Power input/BAR_CAP: C117.1, U105.11 (CAP)
/Power input/BAR_DGATE: Q106.4 (G), U105.1 (DGATE)
/Power input/BAR_DVDT: C118.1, R124.2
/Power input/BAR_EN: R127.2, R128.1, U105.6 (EN/UVLO)
/Power input/BAR_HGATE: Q107.4 (G), R124.1, U105.8 (HGATE)
/Power input/BAR_MID: C116.1, C117.2, Q106.5 (D), Q106.6 (D), Q106.7 (D), Q106.8 (D), Q107.5 (D), Q107.6 (D), Q107.7 (D), Q107.8 (D), U105.10 (VS), U105.12 (C)
/Power input/BAR_MON_OV: R130.2, R131.1, U106.4 (INB-)
/Power input/BAR_MON_TOP: D103.1 (K), R129.1
/Power input/BAR_MON_UV: R129.2, R130.1, U106.3 (INA+)
/Power input/BAR_OK: R132.1, U106.1 (OUTA), U106.6 (OUTB), U108.1
/Power input/BAR_OV: R125.2, R126.1, U105.5 (OV)
/Power input/BAR_SW: R125.1, U105.4 (SW)
/Power input/PDIN_CC1: C109.1, U101.12 (CC1), U102.24 (CC1)
/Power input/PDIN_CC2: C110.1, U101.11 (CC2), U102.25 (CC2)
/Power input/PDIN_C_CC1: J101.A5 (CC1), U101.4 (C_CC1), U101.7 (RPD_G1)
/Power input/PDIN_C_CC2: J101.B5 (CC2), U101.5 (C_CC2), U101.6 (RPD_G2)
/Power input/PDIN_EPR_EN: R118.1, U101.16 (EPR_EN), U102.5 (GPIO0)
/Power input/PDIN_FLT_N: R101.1, U101.9 (~FLT), U102.7 (GPIO2)
/Power input/PDIN_PRES_L: R116.1, R117.1, U102.6 (GPIO1)
/Power input/PDIN_VBIAS: C103.1, U101.3 (VBIAS)
/Power input/PDIN_VBUS_LV: C105.1, U101.19 (VBUS_LV), U102.26 (VBUS), U102.27 (VBUS)
/Power input/PD_ADCIN1: R102.2, R103.1, U102.2 (ADCIN1)
/Power input/PD_ADCIN2: R104.2, R105.1, U102.3 (ADCIN2)
/Power input/PD_CAP: C113.1, U104.11 (CAP)
/Power input/PD_DGATE: Q104.4 (G), U104.1 (DGATE)
/Power input/PD_DVDT: C114.1, R123.2
/Power input/PD_GPIO3: R110.1, U102.18 (GPIO3)
/Power input/PD_GPIO4: R111.1, U102.22 (GPIO4/USB_P/LD1)
/Power input/PD_GPIO5: R112.1, U102.23 (GPIO5/USB_N/LD2)
/Power input/PD_GPIO6: R113.1, U102.31 (GPIO6)
/Power input/PD_GPIO7: R114.1, U102.30 (GPIO7)
/Power input/PD_GPIO11: R115.1, U102.13 (GPIO11)
/Power input/PD_HGATE: Q105.4 (G), R123.1, U104.8 (HGATE)
/Power input/PD_I2CC_IRQ_N: R107.1, U102.17 (~I2Cc_IRQ)
/Power input/PD_I2CC_SCL: R109.1, TP102.1, U102.16 (I2Cc_SCL), U103.6 (SCL)
/Power input/PD_I2CC_SDA: R108.1, TP101.1, U102.15 (I2Cc_SDA), U103.5 (SDA)
/Power input/PD_LDO_1V5: C108.1, U102.4 (LDO_1V5)
/Power input/PD_LDO_3V3: C104.1, C107.1, C111.1, R101.2, R102.1, R104.1, R107.2, R108.2, R109.2, R119.2, R120.2, U101.10 (VPWR), U102.1 (LDO_3V3), U103.8 (VCC)
/Power input/PD_MID: C112.1, C113.2, Q104.5 (D), Q104.6 (D), Q104.7 (D), Q104.8 (D), Q105.5 (D), Q105.6 (D), Q105.7 (D), Q105.8 (D), U104.10 (VS), U104.12 (C)
/Power input/PD_MON_OV: R134.2, R135.1, U107.4 (INB-)
/Power input/PD_MON_UV: R133.2, R134.1, U107.3 (INA+)
/Power input/PD_OK: Q103.3 (D), R136.1, U107.1 (OUTA), U107.6 (OUTB), U108.2
/Power input/PD_OV: R121.2, R122.1, U104.5 (OV)
/Power input/PD_OV_TOP: R121.1, U104.4 (SW)
/Power input/PD_PP_EN_HV: Q101.1 (G), U102.20 (POWER_PATH_EN)
/Power input/PD_PP_EN_INV: Q101.3 (D), Q102.1 (G), Q103.1 (G), R119.1
/Power input/PD_SINK_EN: Q102.3 (D), R120.1, U104.6 (EN/UVLO)
/Power input/VBAR: C115.1, D102.1, D103.2 (A), J102.1, Q106.1 (S), Q106.2 (S), Q106.3 (S), R127.1, U105.2 (A), U105.3 (VSNS)
/Power input/VIN_OR: Q105.1 (S), Q105.2 (S), Q105.3 (S), Q107.1 (S), Q107.2 (S), Q107.3 (S), R137.1, U104.9 (OUT), U105.9 (OUT), U109.10 (IN+)
EXT_PWR_PRESENT: U108.4; also elsewhere on the board
GND: C101.2, C102.2, C103.2, C104.2, C105.2, C106.2, C107.2, C108.2, C109.2, C110.2, C111.2, C112.2, C114.2, C115.2, C116.2, C118.2, C119.2, C120.2, C121.2, C122.2, C123.2, C124.2, C125.2, D101.2 (A), D102.2, J101.0, J101.A1 (GND), J101.A12 (GND), J101.B1 (GND), J101.B12 (GND), J102.2, Q101.2 (S), Q102.2 (S), Q103.2 (S), R103.2, R105.2, R110.2, R111.2, R112.2, R113.2, R114.2, R115.2, R116.2, R118.2, R122.2, R126.2, R128.2, R131.2, R135.2, U101.8 (GND), U101.13 (GND), U101.18 (GND), U101.21 (EP), U102.11 (GND), U102.12 (GND), U102.14 (GND), U102.19 (GND), U102.28 (PP5V), U102.29 (PP5V), U102.33 (GND), U103.1 (A0), U103.2 (A1), U103.3 (A2), U103.4 (GND), U103.7 (WP), U104.7 (GND), U105.7 (GND), U106.2 (GND), U107.2 (GND), U108.3 (GND), U109.7 (GND); also elsewhere on the board
I2C_PD_SCL: U102.9 (I2Ct_SCL); also elsewhere on the board
I2C_PD_SDA: U102.8 (I2Ct_SDA); also elsewhere on the board
I2C_SYS_SCL: U109.5 (SCL); also elsewhere on the board
I2C_SYS_SDA: U109.4 (SDA); also elsewhere on the board
PDIN_INT_N: R106.1, U102.10 (~I2Ct_IRQ); also elsewhere on the board
PDIN_PRESENT: R117.2; also elsewhere on the board
VBUS_PDIN: C101.1, C102.1, D101.1 (C), J101.A4 (VBUS), J101.A9 (VBUS), J101.B4 (VBUS), J101.B9 (VBUS), Q104.1 (S), Q104.2 (S), Q104.3 (S), R133.1, U101.20 (VBUS), U104.2 (A), U104.3 (VSNS)
VIN: C122.1, C123.1, C124.1, R137.2, U109.8 (VBUS), U109.9 (IN–); also elsewhere on the board

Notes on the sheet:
1. PD-IN USB-C (power only)
JAE DX07S024XJ1R1100 (48 V / 5 A EPR-rated, C134113). Only VBUS, CC, GND, shell used:
USB2 D+/D-, SBU and SS pins are left open (no data on this port; no BC1.2).
Shell tied to GND. 5.0SMDJ51A TVS (5 kW, SMC): VRWM 51 V > 50.4 V EPR max, VBR 56.7-62.7 V,
Rdyn ~0.32 Ohm -> ~64 V at 5 A, ~68 V at 18 A (SMCJ51A: 82 V). Residual risk vs TPD4S480 63 V: see doc.
TPD4S480: CC short-to-VBUS (63 V) protection, dead-battery Rd (RPD_Gx tied to C_CCx),
VBUS -> VBUS_LV scaler (x0.42 in EPR) so the TPS26750 VBUS pin (22 V max) can sense 48 V.
EPR_BLK_G unused (no 5 V source FET: sink-only port). SBU channels unused.
2. TPS26750 EPR SINK CONTROLLER (TI SLVSH67 Fig. 8-24 reference)
Powered from +3V3 (VIN_3V3) when the deck runs, else from VBUS via its internal LDO (dead battery).
ADCIN1 = ADCIN2 = 100k/100k (decoded 5/5): 'AlwaysEnableSink', I2C target index #2 = 0x21.
Blank EEPROM: sink path closes at 5 V but PD stays off until a host loads a config, and 5 V on VIN
does NOT start the LM5148 (UVLO 8 V). First EEPROM programming needs barrel, laptop bus power or I2Cc pads.
(SafeMode alternative: ADCIN1 -> LDO_3V3, ADCIN2 -> GND = 7/0, address 0x20.)
Config/patch from AT24C512C (64 KB >= 36 KB req.) at 0x50 on the private I2Cc bus.
RP2350 updates it through the TPS26750 host interface (I2Ct, 0x21); I2Cc test pads for recovery.
GPIO0 = EPR_EN (to TPD4S480), GPIO1 = PDIN_PRESENT (informational only, 47k series: <= 60 uA into an
unpowered PMG1/RP2350 pin; config: high while sink contract active),
GPIO2 = TPD4S480 FLT# input, other GPIOs strapped to GND through 100k (datasheet: tie low if unused).
PP5V tied to GND: sink-only port, no 5 V sourcing / VCONN (verify with TI).
I2C_PD pull-ups live on the MCU sheet; PDIN_INT_N pull-up here.
POWER_PATH_EN BUFFER (Fig. 8-5)
Q101: inverts POWER_PATH_EN, Q102: PD_SINK_EN (LM74800 EN),
Q103: pulls PD_OK low while the sink path is off.
3. PD-IN SINK PATH VBUS_PDIN -> VIN_OR
LM74800-Q1 ideal diode (Q104, DGATE) + load switch (Q105, HGATE), common drain, 2x BSC026N08NS5 80 V.
EN/UVLO = PD_SINK_EN: path closes only when the TPS26750 enables its sink path.
OV: 100k/2.2k -> 1.231 V x 102.2/2.2 = 57.2 V (55.5-58.9 V) > 50.4 V EPR max.
Inrush: HGATE 55 uA into 47 nF -> 1.17 V/ms; ~0.12 A into <= 100 uF of VIN capacitance.
Always armed (no priority): PD-in and barrel are both ideal-diode ORed, the higher voltage feeds VIN.
VIN capacitance seen by the PD source <= 100 uF (cSnkBulkPd) incl. downstream converter inputs: see doc.
Reverse/backfeed from VIN (barrel or buck-boost) blocked by Q104 (ideal diode).
Conduction: 5 A x 2 x 2.6 mOhm = 0.13 W.
4. BARREL INPUT 9-24 V / 8 A (Same Sky PJ-063BH, 5.5x2.5 mm, pin 1 = centre +)
MS mounting tabs left unconnected (would short to + on a reversed plug if tied to GND).
5.0SMDJ48CA bidirectional TVS (5 kW): survives a reversed 24 V and a wrong 48 V brick (VBR 53.3 V min).
LM74800-Q1 (same as PD path) instead of LM74720: the LM74720 PD pin pulls the HSFET gate to GND,
i.e. Vgs = -VIN while PD-in holds VIN up; the LM74800 HGATE is referenced to OUT.
Q106 = ideal diode (DGATE, blocks reverse polarity to -65 V), Q107 = OV / UVLO / enable cut-off (HGATE).
OV: 100k/4.7k -> 1.231 V x 104.7/4.7 = 27.4 V (26.6-28.2 V), recovers at 25.2 V.

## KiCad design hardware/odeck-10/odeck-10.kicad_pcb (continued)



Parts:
C801, C832: 1u; C_0402_1005Metric; LCSC C52923
C802: 1n; C_0402_1005Metric; LCSC C1523
C803, C806, C827, C828: 10u; C_0603_1608Metric; LCSC C19702
C804, C808, C809: 22u; C_0603_1608Metric; LCSC C59461
C805, C807, C810, C812, C813, C814, C817, C818, C819, C823, C824, C825, C829, C831, C835, C836, C839, C840, C841: 100n; C_0402_1005Metric; LCSC C1525
C811, C815, C816, C820, C821, C822, C826, C830: 2.2u; C_0402_1005Metric; LCSC C12530
C833, C834: 20p; C_0402_1005Metric; LCSC C1554
C837: 390p; C_0402_1005Metric; LCSC C282239
C838: 100n; C_0402_1005Metric; LCSC C1525; not fitted
FB801: 100R@100MHz; L_0805_2012Metric; LCSC C1015
J801: RJ45 2.5G; RJ45-TH_DGUK211Q340CD2A4D2; MPN DGUK211Q340CD2A4D2(2.5G); LCSC C19725134
L801: 1uH; L_Sunlord_SWPA4018S; LCSC C91250
Q801: BSS138DW; SOT-363_SC-70-6; MPN BSS138DW-7-F; LCSC C154900
R801, R803, R820, R821: 100k; R_0402_1005Metric; LCSC C25741
R802: 59k; R_0402_1005Metric; LCSC C32297
R804: 0; R_0402_1005Metric; LCSC C17168
R805: 2.49k; R_0402_1005Metric; LCSC C25884
R806, R807, R808, R809, R810, R811, R813, R818, R819: 4.7k; R_0402_1005Metric; LCSC C25900
R812, R814: 10k; R_0402_1005Metric; LCSC C25744
R815: 10k; R_0402_1005Metric; LCSC C25744; not fitted
R816, R817: 510; R_0402_1005Metric; LCSC C25123
U801: RTL8156BG-CG; QFN-56_L6.0-W6.0-P0.35--TL-EP4.7; MPN RTL8156BG-CG; LCSC C41376388
U802: TPS22918; SOT-23-6; MPN TPS22918DBVR; LCSC C131941
U803: TPS62A02A; SOT-5X3-6_W1.6-L1.2-P0.50-LS1.6-BL; MPN TPS62A02ADRLR; LCSC C5820994
U804: SN74LVC3G17; VSSOP-8_L2.1-W2.4-P0.50-LS3.2-BR; MPN SN74LVC3G17DCUR; LCSC C68245
U805: 24AA025E48T-I/OT; SOT-23-6; MPN 24AA025E48T-I/OT; LCSC C129895
U806: 74LVC1G17; SOT-23-5; MPN 74LVC1G17W5-7; LCSC C151394
Y801: 25MHz; Crystal_SMD_3225-4Pin_3.2x2.5mm; LCSC C9006
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

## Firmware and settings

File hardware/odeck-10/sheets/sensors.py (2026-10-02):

"""odeck-10 — Sensors sheet: 8x TMP1075 on I2C_SYS (0x48-0x4F, ALERT wire-OR to TEMP_ALERT_N), 2x NTC hot-spot
thermistors into RP2350 ADC (bias on the mcu sheet), and copper thermocouple pads at the hot spots.
Design notes: docs/design/sensors.md"""
import sys, os
sys.path.insert(0, os.path.join(os.path.dirname(__file__), "..", "..", "..", "tools", "schgen"))
from schgen import Sheet

# --- part numbers (LCSC) -------------------------------------------------------------------------
C_100N = "C1525"                   # basic 100 nF 0402
TMP = "C2870250"                   # TI TMP1075DSGR, WSON-8 2x2 (+-1 C max -40..110 C)
NTC = "C13564"                     # Murata NCP18XH103F03RB 10k 1 % B25/50 3380 K, 0603
TP_FP = "TestPoint:TestPoint_Pad_2.0x2.0mm"

# (address, A2 A1 A0, placement, layout hint)
SENSORS = [
    (0x48, "000", "BUCK-BOOST", "LM51770 power stage (power_laptop): between the FET bridge and the 10 uH XAL1010 inductor"),
    (0x49, "001", "5V BUCK", "LM5148 stage (power_rails): next to Q301 high-side FET / L301 (48 V corner hot spot)"),
    (0x4A, "010", "HUB", "USB7206C (usb_hub): on the bottom side under the hub EP via field, or top side <= 3 mm from the package"),
    (0x4B, "011", "PMG1/MUX", "PMG1-S3 BGA + TUSB1064 (pd_pmg1 / usbc_muxes): between the two"),
    (0x4C, "100", "LAPTOP-C", "laptop USB-C receptacle (DX07): at the VBUS/GND pins, inside the 5 A VBUS pour"),
    (0x4D, "101", "ETHERNET", "RTL8156BG / RJ45 (ethernet): between the QFN-56 and the magjack"),
    (0x4E, "110", "LCD", "under the 2.0in LCD module (display_ui), centre of its footprint, top side"),
    (0x4F, "111", "AMBIENT", "board edge / ambient: front-left corner near the SD socket, far from every heat source"),
]

# thermocouple / IR-reference pads (copper only, GND-tied for heat spreading; not in BOM)
TPADS = [
    ("TC_BB_FET", "buck-boost FETs (LM51770 bridge, hottest FET)"),
    ("TC_BB_L", "buck-boost inductor XAL1010"),
    ("TC_5V_FET", "LM5148 high-side FET Q301"),
    ("TC_5V_L", "LM5148 inductor L301"),
    ("TC_HUB", "USB7206C package top / EP"),
    ("TC_LAPTOP_C", "laptop USB-C VBUS pins"),
    ("TC_ETH", "RTL8156BG"),
    ("TC_ORFET", "LM74700 OR-FET Q303 / sink switch area (5 V path)"),
]


def _note(s, text, at, size=1.27):
    """Multi-line note as one text item per line (embedded newlines do not survive schgen's quoting)."""
    for i, line in enumerate(text.split("\n")):
        s.note(line, at=(at[0], round(at[1] + i * 2.54, 2)), size=size)


def build(D):
    s = Sheet(D, "sensors.kicad_sch", "odeck-10 — Thermal sensors", ref_base=1200)

    # =============================================================================================
    # 1. TMP1075 x8
    # =============================================================================================
    _note(s, "1. TMP1075 x8 on I2C_SYS  (0x48-0x4F, A2..A0 strapped to GND/+3V3; ALERT open-drain wire-OR -> TEMP_ALERT_N)",
          (20.32, 15.24), 2.0)
    refs = []
    for i, (addr, bits, tag, where) in enumerate(SENSORS):
        col, row = i % 4, i // 4
        x, y = 40.64 + col * 93.98, 45.72 + row * 43.18
        a2, a1, a0 = ("+3V3" if b == "1" else "GND" for b in bits)
        u = s.part("odeck:TMP1075DSGR", "U", "TMP1075", at=(x, y), lcsc=TMP,
                   pins={"V+": "+3V3", "GND": "GND", "EP": "GND", "SDA": "I2C_SYS_SDA", "SCL": "I2C_SYS_SCL",
                         "ALERT": "TEMP_ALERT_N", "A2": a2, "A1": a1, "A0": a0},
                   desc=f"I2C temp sensor 0x{addr:02X} - {tag}: {where}")
        s.c("100n", "+3V3", "GND", at=(x + 27.94, y), lcsc=C_100N, desc=f"{u.ref} decoupling, at V+")
        refs.append(u.ref)
        _note(s, f"{u.ref}  0x{addr:02X}  {tag}", (x - 15.24, y + 15.24), 1.5)
    _note(s, "Placement (reference -> location; layout must put each sensor here, EP soldered to a GND pour that touches the source):\n"
             + "\n".join(f"  {r}  0x{a:02X}  {t:<10} {w}" for r, (a, _, t, w) in zip(refs, SENSORS)),
          (20.32, 116.84))
    _note(s, "I2C_SYS pull-ups (2.2k) and the single TEMP_ALERT_N pull-up (10k, read by TCA9534 P2) live on the MCU sheet - none here.\n"
             "TMP1075 power-on default (config 00FFh): 12-bit continuous, comparator-mode ALERT active low, THIGH 80 C / TLOW 75 C. Firmware\n"
             "  reprograms per-sensor limits at boot (e.g. buck-boost 100 C, hub 95 C, LCD 60 C) and uses TEMP_ALERT_N as the\n"
             "  derating interrupt. To find the source: switch to interrupt mode (TM = 1) after boot and read the SMBus Alert Response\n"
             "  Address 0x0C (DS 7.3.2.6, free on I2C_SYS), or simply read all 8 temperatures (~2 ms at 400 kHz).\n"
             "Accuracy +-1 C max (-40..110 C); WSON EP is the thermal path - it measures the copper it sits on, not air.",
          (20.32, 144.78))

    # =============================================================================================
    # 2. NTC hot spots
    # =============================================================================================
    x0, y0 = 20.32, 167.64
    _note(s, "2. NTC HOT SPOTS  NCP18XH103F03RB 10k B3380 0603 to GND; 10k 1 % bias + 100 nF from ADC_AVDD on the MCU sheet", (x0, y0), 2.0)
    y = y0 + 20.32
    s.part("Device:Thermistor_NTC", "TH", "10k NTC", "Resistor_SMD:R_0603_1608Metric", at=(x0 + 10.16, y),
           pins={"1": "NTC_ADC0", "2": "GND"}, lcsc=NTC,
           desc="NTC_ADC0: buck-boost inductor (XAL1010) - touching the inductor's pad copper, GND end on the GND plane")
    s.part("Device:Thermistor_NTC", "TH", "10k NTC", "Resistor_SMD:R_0603_1608Metric", at=(x0 + 30.48, y),
           pins={"1": "NTC_ADC1", "2": "GND"}, lcsc=NTC,
           desc="NTC_ADC1: LM5148 high-side FET Q301 - on its drain/SW copper side, as close as clearance allows")
    _note(s, "TH1201 -> NTC_ADC0: buck-boost inductor hot spot.   TH1202 -> NTC_ADC1: LM5148 Q301 (high-side FET) hot spot.\n"
             "Ratiometric divider (bias to ADC_AVDD = ADC reference): V = AVDD x R_NTC / (10k + R_NTC); 25 C -> 0.50, 85 C -> 0.12,\n"
             "  100 C -> 0.08 x AVDD (R(100 C) ~ 0.97k). Route NTC_ADCx as a guarded trace away from SW nodes; the 100 nF at the ADC pin\n"
             "  (mcu sheet) filters switching noise. Thermistor GND end is the local power GND: measure at low fsw-phase-noise points.",
          (x0 + 45.72, y0 + 10.16))
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

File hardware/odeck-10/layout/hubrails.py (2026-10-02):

"""hubrails block: USB hub (USB7206C, 6xx) + Rails (LM5148 5 V/8 A, TPS62933F +3V3, TPS62933P +1V15, 3xx)
+ sensors U1202/U1203/TH1202/TP1202/TP1203.  Region (138,80)-(180,108).  See docs/layout-notes/hubrails.md.

Floor plan inside the region (top side):
  x 138.5-160   LM5148 power column: L301 (top), FETs Q301/Q302 directly under L301's SW pad, input caps
                bottom-left (VIN enters at the left edge, y 96-108), U301 right of L301, C323 bottom-right.
                Output side (47 uF bank, OR-FET Q303, LM74700, 2 mOhm shunt, INA226) on the BOTTOM side under L301/R303.
  x 160-164.3   P1/P2 (card reader, USB-A #1) pair channel running down from the hub's left side (y >= 94.5).
                Above it: 25 MHz crystal (top-left hub corner), +3V3 buck (TPS62933F) in the top-left strip.
  x 164.3-177.7 USB7206C U601 (centre 171, 98), rot 0 -> upstream/P5 pins face the back (usbc block),
                P3/P4/P6 face the front, PF/SPI side faces the right block.  100 nF per-pin caps on the bottom
                in the ring between the EP via field and the pad row; straps/bulk on the bottom outside the ring.
  x 167.5-174   top corridor: upstream + P5 pairs (and their TX AC caps) going straight up to y 80.
  x 174-180     top-right: +1V15 buck (TPS62933P) next to the VCORE pin 78 corner.
  y 104.8-108   under the hub: P3 straight down (J702), P4/P6 turn right to the right block; their AC caps.
"""

REGION = [(138.0, 80.0, 180.0, 108.0)]

HUB = [f"C{n}" for n in range(601, 642)] + ["D601", "D602"] + [f"R{n}" for n in range(601, 634)] + \
      ["U601", "U602", "U603", "Y601"]
RAILS = [f"C{n}" for n in range(301, 342)] + ["D301", "L301", "L302", "L303", "Q301", "Q302", "Q303"] + \
        [f"R{n}" for n in range(301, 322)] + [f"U{n}" for n in range(301, 306)]
SENS = ["U1202", "C1202", "U1203", "C1203", "TH1202", "TP1202", "TP1203"]
REFS = HUB + RAILS + SENS

HX, HY = 171.0, 98.0          # USB7206C centre


def place(board, h):
    T, B = "top", "bottom"
    P = h.put

    def hp(dx, dy):
        return HX + dx, HY + dy

    # ================================================================== USB7206C (U601)
    # rot 0: pin 1 top-left; pins 76-100 (UP 89-95, P5 81-87, XTAL 97/98, RBIAS 100) face the back edge,
    # pins 1-25 (P1, P2) face left, 26-50 (P3, P4, P6) face the front, 51-75 (PF/SPI/SMBus) face the right block.
    P("U601", HX, HY, 0, T)

    # --- per-pin 100 nF.  The footprint carries the EP via array as PTH pads, so nothing may sit under the
    #     package on the bottom.  Right-side pins (no pairs there) get their caps on TOP at the pad row; pins
    #     interleaved with the SS pairs get theirs on the BOTTOM just outside the courtyard (via at the pad toe).
    P("C620", *hp(7.4, 4.75), 90, T)      # VDD33 pin 53
    P("C632", *hp(7.4, 2.6), 90, T)       # VCORE pin 55
    P("C616", *hp(7.4, 0.45), 90, T)      # VDD33 pin 62
    P("C617", *hp(7.4, -1.7), 90, T)      # VDD33 pin 67
    P("C633", *hp(7.4, -3.85), 90, T)     # 4.7u VCORE bulk
    P("C622", *hp(7.4, -6.0), 90, T)      # 4.7u VDD33 bulk
    # top edge, bottom side, row 1 (y_rel -7.4)
    P("C624", *hp(4.6, -7.4), 0, B)       # VCORE pin 78
    P("C618", *hp(2.4, -7.4), 0, B)       # VDD33 pin 79
    P("C625", *hp(0.2, -7.4), 0, B)       # VCORE pin 85
    P("C613", *hp(-4.2, -7.4), 0, B)      # VDD33 (+3V3 pad 1 right behind pin 99, so its toe via can land on it)
    P("C626", *hp(-2.0, -7.4), 0, B)      # VCORE (+1V15 pad 1 behind pin 93); swapped with C613 2026-10-03
    P("C614", *hp(-6.4, -7.4), 0, B)      # VDD33 pin 99
    # top edge, bottom side, row 2 (y_rel -8.65): RBIAS + bulk
    P("R601", *hp(-5.0, -8.65), 0, B)     # RBIAS 12k 1 % (pin 100)
    P("C623", *hp(-2.8, -8.65), 0, B)     # 1n VDD33
    P("C636", *hp(-0.6, -8.65), 0, B)     # 1n VCORE
    P("C634", *hp(1.6, -8.65), 0, B)      # 4.7u VCORE
    P("C635", *hp(3.8, -8.65), 0, B)      # 4.7u VCORE
    # left edge, bottom side: column 1 (x_rel -7.4), column 2 (-8.8)
    P("R622", *hp(-7.4, -3.8), 90, B)     # PF31 100k (pin 3)
    P("C627", *hp(-7.4, -1.65), 90, B)    # VCORE pin 9
    P("R607", *hp(-7.4, 0.5), 90, B)      # CFG_STRAP3 200k (pin 23)
    P("C628", *hp(-7.4, 2.65), 90, B)     # VCORE pin 18
    P("C629", *hp(-7.4, 4.8), 90, B)      # VCORE pin 25
    P("C639", *hp(-8.8, -1.65), 90, B)    # RESET_N 1n
    P("R624", *hp(-8.8, 0.5), 90, B)      # RESET_N 10k PU
    P("R605", *hp(-8.8, 2.65), 90, B)     # CFG_STRAP1 10k (pin 21)
    P("R606", *hp(-8.8, 4.8), 90, B)      # CFG_STRAP2 200k (pin 22)
    # bottom edge, bottom side: row A (y_rel 7.4), row B (8.65)
    P("C619", *hp(-4.6, 7.4), 0, B)       # VDD33 pin 26
    P("C630", *hp(-2.4, 7.4), 0, B)       # VCORE pin 31
    P("C631", *hp(-0.2, 7.4), 0, B)       # VCORE pin 38
    P("C615", *hp(2.0, 7.4), 0, B)        # VDD33 pin 43
    P("C621", *hp(4.2, 7.4), 0, B)        # 4.7u VDD33
    P("R629", *hp(-5.6, 8.65), 0, B)      # HUB_SMB_PU 4.7k pull-down (erratum E9)
    P("R619", *hp(-3.4, 8.65), 0, B)      # PF7
    P("R615", *hp(-1.2, 8.65), 0, B)      # PF3 (pins 44-48: PF3..PF7, 100k PD)
    P("R616", *hp(1.0, 8.65), 0, B)       # PF4
    P("R617", *hp(3.2, 8.65), 0, B)       # PF5
    P("R618", *hp(5.4, 8.65), 0, B)       # PF6
    # right edge, bottom side: one strap column (x_rel 7.95, rot 0, 1.25 mm pitch), ordered like the pins
    col = ["R628", "R627", "R623", "R614", "R613", "R612", "R611", "R609", "R608", "R610", "R621", "R604",
           "R603", "R602", "R620", "R631", "R630"]
    for k, r in enumerate(col):
        P(r, *hp(7.95, -10.8 + 1.25 * k), 0, B)

    # --- 25 MHz crystal at the top-left corner (XI/XO = pins 98/97), 20 pF load caps right under its pads
    P("Y601", 161.95, 92.85, 0, T)
    P("C638", 162.3, 92.0, 0, B)          # XO 20p
    P("C637", 161.65, 93.75, 90, B)       # XI 20p

    # --- SS TX AC caps (top, in-line, <= 5 mm from the pins)
    P("C601", HX - 1.9, HY - 9.8, 90, T)   # UP TXP  (pins 91/92 -> TUSB1064)
    P("C602", HX - 0.65, HY - 9.8, 90, T)  # UP TXN
    P("C612", HX + 1.35, HY - 9.8, 90, T)  # P5 TXN (pin 84 at x 172.6)  -- C611/C612 swapped 2026-10-03:
    P("C611", HX + 2.6, HY - 9.8, 90, T)   # P5 TXP (pin 83 at x 173.0)     P/N order now matches the hub pins
    P("C603", 160.55, 101.0, 270, T)       # P1 TXP (pins 7/8 -> GL3224), outer lane of the left channel
    P("C604", 161.8, 101.0, 270, T)        # P1 TXN
    P("C605", 162.3, 105.4, 270, T)        # P2 TXP (pins 16/17 -> USB-A #1), inner lane
    P("C606", 163.55, 105.4, 270, T)       # P2 TXN
    P("C607", HX - 4.2, 106.55, 270, T)    # P3 TXP (pins 29/30 -> USB-A #2, straight down)
    P("C608", HX - 2.95, 106.55, 270, T)   # P3 TXN
    # (C603-C608 rot 270: pad 1 = hub-side net faces north toward the hub pins)
    P("C609", 177.4, 105.5, 0, T)          # P4 TXP (pins 36/37 -> RTL8156BG, turns right); 2 mm east of the
    P("C610", 177.4, 106.75, 0, T)         # P4 TXN    pin 43-48 pocket so the +3V3/PF3-PF7 escape vias fit
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

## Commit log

2026-10-02 Add initial planning docs and component research
    Requirements, odeck-10 (10 Gbps) prototype plan, and research notes on
    JLCPCB capabilities, USB4 core chips, and peripheral parts.
2026-10-02 Add PD, hub/signal-path, power/assembly research; update odeck-10 plan
    - PD: PMG1-S3 dual-port for laptop + downstream ports, TPS26750 for PD-in
    - Hub: USB7206C, TUSB1064 upstream / TUSB1046 downstream muxes
    - Power: LM74720/LM74700 OR-ing, LM51770 buck-boost, laptop-port role rules
    - Connectors and JLC assembly notes; thermal flagged as top risk
2026-10-02 odeck-10: DP over USB-C, 2x USB-A, RP2350 update hub, thermal probes
    - Drop GL3523 sub-hub; hub ports now cover everything directly
    - RP2350 bundles and flashes firmware/config for all other components
    - Unique MAC via EUI-48 EEPROM
    - Prototype thermal + power instrumentation (TMP1075, NTCs, INA226/INA228)
2026-10-02 odeck-10: user buttons, forced 5V charge mode, per-port power sensing; no flash interlock
2026-10-02 Add power budget, board layout plan, and KiCad 10 project skeleton
    - docs/power-budget.md: internal/port/laptop loads, worst case ~186 W in, ~16 W heat
    - docs/board-layout.md: 110x75 mm provisional outline, edge/placement plan, stackup
    - hardware/odeck-10: hierarchical schematic (12 block sheets), PCB with
    JLC061611-1080A 6L stackup, outline, M3 holes, JLC rules, net classes
    - hardware/lib: empty shared symbol/footprint libraries
    [card_reader.kicad_sch, display_ui.kicad_sch, ethernet.kicad_sch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]
2026-10-02 Add schgen schematic-as-code tooling and LCSC import script
    - tools/schgen: generate KiCad sheets from Python, netlist verification,
    pin-type fixer, shared inter-sheet net registry
    - tools/import_lcsc.sh: easyeda2kicad wrapper (relative 3D paths, KiCad 10
    upgrade, locking)
    - hardware/odeck-10/sheets/build_all.py; TMP1075 imported as first part
    [build_all.py, fix_pins.py, nets.py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]
2026-10-02 Draft power sheets (input, laptop output, rails) and BOM stock audit
    - power_input: TPS26750/TPD4S480 EPR sink, LM74800 PD-in and barrel paths
    (reverse/OV/UV), hardware PD-in priority, EXT_PWR_PRESENT, INA237 VIN monitor
    - power_laptop: LM51770 buck-boost 5-28 V x 5 A with VSEL-only voltage steps,
    gated source switch, interlocked bus-power sink, latched 30.8 V OVP, INA226
    - power_rails: LM5148 5 V/8 A with ideal-diode backfeed blocking, TPS62933
    3.3 V and 1.15 V, INA226
    - tools/bom_check.py: JLC-stock-only audit (>=5); all 116 parts pass
    - schgen fixes: multi-line notes, PWR_FLAG skipped in verify, import --force
    - docs: design notes per sheet, I2C map, cross-sheet integration items
    C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
    [power_input.kicad_sch, power_laptop.kicad_sch, power_rails.kicad_sch]
2026-10-02 Draft data-path sheets: PD controller, USB-C muxes/DP, USB hub
    - pd_pmg1: PMG1-S3 (CYPM1321, dead-battery Rd) dual-port: laptop EPR source +
    DP UFP_D, downstream 5 V/3 A + DP DFP_D, HPD relay, VBUS-powered cold start,
    I2C 0x42, SWD/reset via cuttable jumpers
    - usbc_muxes: laptop + downstream USB-C, TUSB1064/TUSB1046 in GPIO mode,
    TPD4S480 (EPR) / TPD6S300 CC protection, 10G-rated ESD, AC coupling
    - usb_hub: USB7206C port map, SMBus-optional boot, reset gated by RAILS_PG,
    BC1.2 on USB-A ports, hub-TX AC caps
    - schgen: in_bom option; nets: VBUS_LSW, PMG1_VDDD, hub/mux/CC links
    - import_lcsc.sh: guard against overwriting other parts' footprints
    - 137 parts, all JLC stock >= 5
    Co-Author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
    [pd_pmg1.kicad_sch, power_input.kicad_sch, power_laptop.kicad_sch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]
2026-10-02 Draft remaining sheets: USB-A, card reader, Ethernet, MCU, display/UI, sensors
    - usb_a: 2x 10G USB-A, TPS2553 switches (hub OR RP2350 force), INA180 sense
    - card_reader: GL3224 + SD/microSD, card detect + activity to MCU
    - ethernet: RTL8156BG with switched 3.3 V, 0.95 V PWM buck, 2.5G magjack,
    LED buffer, EUI-48 EEPROM + gated I2C bridge for MAC eFuse write
    - mcu: RP2350B reference core, full GPIO table, TCA9534 expander, PIO I2C
    - display_ui: 2.0" ST7789 LCD + backlight PWM, buttons, unpopulated GPIO
    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
    [card_reader.kicad_sch, display_ui.kicad_sch, ethernet.kicad_sch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]
2026-10-02 Schematic review + footprint verification; fix all MAJOR findings
    Reviews (docs/review/): power, PD/mux, data path, MCU/UI - 0 blockers,
    7 majors, all resolved:
    - power: diode-OR inputs (no shutdown-based PD-in priority), sink hand-over
    gated by delayed PG_5V, PD-in capacitance within 100 uF, HV resistor sizes,
    OVP filter/threshold, VBB_PG soft-start qualification
    - card reader MS2_INS/SD2_WP phantom card, hub VBUS_DET level buffer
    - RP2350 inductor dot text; minors across all sheets (HPD pull-down, PMG1
    INT pin, PHY TX caps, erratum E9 pull-downs, PHY I2C bridge gating,
    backlight 39 ohm, +1V1 cap, IOX P7)
    Footprints: all 54 custom footprints checked vs manufacturer drawings,
    50 fixe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
    [card_reader.kicad_sch, display_ui.kicad_sch, ethernet.kicad_sch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]
2026-10-02 LCD on 12-pin FPC connector; verify USB-A footprint against Amphenol drawing
    - display_ui: Hirose FH34SRJ-12S-0.5SH dual-contact FPC connector (J1103),
    panel pin n -> connector pin 13-n after the 180 deg fold; panel is DNP in BOM
    with a pad-less outline footprint; foam tape 1.5 mm with connector window
    - USB-A footprint checked against Amphenol GSB4111xxxHR drawing (added to
    docs/datasheets): shell-leg spacing/offset fixed, board-edge marked;
    renamed to USB-A_Amphenol_GSB4111312HR
    - import_lcsc.sh: only upgrade newly imported footprints
    - stop tracking __pycache__
    [display_ui.kicad_sch, usb_a.kicad_sch]
2026-10-02 Cost pass, PCB sync + rough placement, renders, README
    - cost pass: extended parts 129 -> 114 (~$45/order less), nets unchanged
    - tools/pcbsync.py: scripted update-PCB-from-schematic (keeps placed parts)
    - tools/set_outline.py; board grown to 130x85 mm (provisional)
    - hardware/odeck-10/placement.py: edge connectors + anchor-based packing,
    small passives spill to bottom; all 796 parts on the board (2 at anchor)
    - docs/images: top/bottom/iso renders of the rough placement
    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
    [card_reader.kicad_sch, ethernet.kicad_sch, odeck-10.kicad_pcb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]
2026-10-02 Placement: floorplan, per-region placement scripts, DRC-clean placed board
    - docs/floorplan.md: 5 regions; board 130x89 mm (SD socket depth), microSD on
    top at the front-right (overhangs edge 2 mm under the LCD panel)
    - layout/{power,usbc,hubrails,front,right}.py + zz_integration.py; per-block
    placement rationale and routing intent in docs/layout-notes/
    - tools/apply_layout.py (region/ownership/overlap checks), set_outline.py,
    pcbsync --refresh, apply_routing.py (coupled pairs, via pairs, zones),
    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
    [card_reader.kicad_sch, odeck-10.kicad_pcb]
2026-10-02 WIP routing: planes/power, USB-C/DP and hub/Ethernet/SD routing scripts; net class patterns
    - routing/a_planes.py (GND planes L2/L5, L4 power islands, pours), b_power.py
    (power paths, thermal vias, Kelvin), c_hs_usbc.py (USB-C SS both
    orientations, DP lanes + AUX, hub up/P5 links), d_hs_hub.py + e_hs_eth_sd.py
    (hub P1-P4/P6 links, MDI, SD/microSD matched)
    - each script DRC-clean alone; integration fixes pending (placement tweaks,
    stitching after routing, cross-script via conflicts) - see docs/routing-notes
    - net class patterns rewritten so HV/PWR/HS/ETH classes actually match nets
2026-10-02 Placement fixes for routing; DRC rules scoped so net classes don't break fine-pitch pads
    - hubrails: C611/C612 swap, C603-C608 rotated (pad 1 to hub pin), C609/C610
    east, pin 99 via room, VBUS-detect parts repacked
    - right: C835/C836 rotated, RP2350 USB via room
    - usbc: U501 south, U504/U503 straps rearranged for downstream escape vias
    - zz_integration: R908 at the U901 CLK escape, TP1206/TP1202 moved
    - power: C220/C114/R122 to bottom (sense pair + VIN via room)
    - net class clearances 0.15; HV 0.3 mm spacing only for drawn copper
    - DRC: 0 errors (unrouted only); docs/routing-notes/placement-fixes.md
    [odeck-10.kicad_pcb]
2026-10-02 Routing wave 1: high-speed scripts adapted to placement fixes, blocked nets completed
    - c_hs_usbc: all CC/SBU/USB2 slow nets on both ports, P5 hub stubs, nominal
    HS_85/USB_90 geometry; skew <=0.15 mm except DS TX2 (0.25)
    - d_hs_hub/e_hs_eth_sd: all cap legs connected, microSD 116 mm matched,
    RP2350 USB, escape room kept for hub pin 99/RBIAS/+1V15, U901 pins 1/2
    - DRC rule: *_TX?_IC pair halves exempt from inter-pair spacing
2026-10-02 Routing wave 2: power/planes adapted to HS routes, z_stitch, full pipeline script
    - a_planes: zones only; b_power: avoids HS copper (computed obstacles), more
    vias at R137/R312, Q204 thermal vias, R202 sense exit, VBUS_LAPTOP L6 pieces
    tied to L4
    - z_stitch.py: geometry-checked GND stitching + edge fence, runs last,
    idempotent; mounting holes on GND
    - DRC: HV rule exempts tracks entering HV-rated 0.5 mm-pitch parts
    - tools/route_all.sh: scripted routing -> drop outer GND pours -> Freerouting
    -> zones + stitching + fill -> DRC; apply_routing --pcb
2026-10-02 Routing: plane-net fanout script; route_all keeps hot-loop GND pours
    f_fanout.py ties 711 plane-net SMD pads to their planes (tagged, idempotent);
    Freerouting's unrouted count 1760 -> 1118. route_all.sh step 2 now drops only
    a_planes' general GND pours.
2026-10-03 Routing runner: GROUPED scripts (group-owned copper), crash-safe footprint cache/exit; net partition tool
